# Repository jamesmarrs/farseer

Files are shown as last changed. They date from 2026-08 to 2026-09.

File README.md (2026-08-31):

# farseer

In-car race telemetry module: GPS uplink over UDP via Quectel BG95-M3, with a
low-volume server downlink.

## Bench wiring

See [docs/bench-wiring.md](docs/bench-wiring.md) for Curiosity Nano + Sixfab
Cellular IoT HAT connections, power rails, and bring-up checklist.

## Custom board

**The KiCad project is the single source of truth for the circuit** —
schematic, nets, reference designators, values, footprints, and MPNs. Open it
with:

```bash
open ki_cad_project/farseer/farseer.kicad_pro
```

Export the rendered schematic PDF and the BOM CSV (into `docs/generated/`,
machine-generated — never hand-edit) with:

```bash
./scripts/export_kicad.sh
```

The design *rationale* — datasheet citations, sizing math, traps, and
trade-offs the schematic cannot carry — lives in `docs/`, one document per
block: [MCU](docs/mcu-support-circuit.md),
[cellular](docs/cellular-support-circuit.md),
[GNSS](docs/gnss-support-circuit.md),
[power](docs/power-support-circuit.md), and
[interconnect](docs/interconnect-and-pin-budget.md) where the pin budget is
reconciled against the 48-pin PPS tables. Off-board parts (antennas, pigtail,
SIM) and cost estimates are in [docs/procurement.md](docs/procurement.md).
Pre-KiCad drawings and BOMs are retained in `docs/_archive/` for history only
and must not be treated as authoritative.

It carries no on-board debugger, so the Curiosity Nano's one-cable-does-everything
arrangement splits in two:

| | Bench (Curiosity Nano) | Custom board |
|---|---|---|
| Program + debug | Micro-USB to the on-board ATSAMD21 | **PICkit 5** on `J_icsp`, a 6-pin ICSP header |
| 115200 console | Same cable, debugger's CDC | **USB-C** on `J_dbg`, via a CP2102N bridge |

USB on the custom board is **data only** — it never powers the board, and the
PICkit must not be asked to power the target either.

## Server UDP tunnel (LocalXpose)

The module sends its telemetry datagrams over UDP to `BG95_SERVER_HOST` /
`BG95_SERVER_PORT` (defined in `bg95.h`). During development that destination is
a [LocalXpose](https://localxpose.io/) (`loclx`) UDP tunnel that forwards public
traffic to a listener on the dev machine.

### One-time setup

```bash
loclx account login                       # authenticate (UDP forwarding needs a paid plan)
loclx endpoint reserve --port 59128 --region us   # reserve us.loclx.io:59128 (once)
```

### Run the tunnel

Start the tunnel BEFORE powering the module, and forward to the same port your
server binds:

```bash
loclx tunnel udp --reserved-endpoint us.loclx.io:59128 --to 127.0.0.1:9000
```

### Gotchas (learned the hard way)

- **Use `127.0.0.1`, never `localhost`, in `--to`.** With `--to localhost:9000`
  loclx does not forward: `localhost` can resolve to IPv6 `::1` while the server
  binds IPv4, so tunneled packets are silently dropped even though the tunnel
  shows "running". Always use the IP literal, e.g. `--to 127.0.0.1:9000`.
- **Keep the port in sync.** The reserved-endpoint port, the module's
  `BG95_SERVER_PORT` in `bg95.h`, and your server's bind port (the `--to` port)
  must all agree. The reserved endpoint's public port and the local `--to` port
  do NOT have to match each other, but the module must target the public port.
- **`--to` port must match the server's bind port**, and the server must listen
  on that UDP port (e.g. `nc -u -l 9000` for a quick stand-in).
- **UDP forwarding is a paid `loclx` feature.** On a free plan the tunnel can
  appear up but never forward UDP.
- **`SEND OK` from the BG95 only means the module handed the datagram to the
  network** — UDP has no delivery ack, so it does not confirm the server (or
  tunnel) received anything.

### Verify the public path

Independently of the module, send a probe to the public endpoint and watch the
server (or a `nc -u -l <port>` stand-in) for it:

```bash
echo "probe" | nc -u -w1 us.loclx.io 59128
```

If the probe lands, the tunnel is good and any remaining delivery gap is on the
module egress side (e.g. BG95 DNS resolution of the host). If it does not land,
the tunnel/endpoint/port/plan is the problem — no firmware change will help.

## Structure

| Path | Purpose |
|---|---|
| _build | The [CMake build tree](https://cmake.org/cmake/help/latest/manual/cmake.1.html#introduction-to-cmake-buildsystems), can be deleted. |
| cmake | Generated [CMake](https://cmake.org/) files. May be deleted if user.cmake has not been added |
| .vscode | See [VSCode](https://code.visualstudio.com/docs/getstarted/settings) |
| .vscode/settings.json | Workspace specific settings |
| .vscode/farseer.mplab.json | The MPLAB project file, should not be deleted |
| out | Final build artifacts |

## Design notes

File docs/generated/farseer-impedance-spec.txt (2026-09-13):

FARSEER - CONTROLLED IMPEDANCE SPECIFICATION (generated, do not edit)

Fab: JLCPCB, 4-layer, 1.6 mm. Select 'Impedance Control' = YES and the
stackup JLC04161H-7628 at order time. The trace below is sized for this
stackup only; JLC's default 4-layer build is NOT equivalent.

Controlled net
  Net name              /GPS/GNSS_RF_IN
  Layer                 Top (F.Cu, L1)
  Structure             Coplanar waveguide with ground (single-ended)
  Reference plane       L2 (In1.Cu, GND)
  Trace width           0.34 mm  (base width as drawn; apply your etch compensation)
  Gap to coplanar GND   0.45 mm  (both sides, F.Cu GND pour)
  Target impedance      50 ohm single-ended
  Tolerance             +/-10 %
  Frequency             1.56-1.61 GHz (GNSS L1 band)
  Marking               text note on User.Comments beside the trace

Stackup as drawn in farseer.kicad_pcb
  layer            type      thickness  material / er
  F.Cu             copper       0.035   
  dielectric 1     prepreg     0.2104   FR4 7628 (JLC04161H-7628)  er 4.4
  In1.Cu           copper      0.0152   
  dielectric 2     core         1.065   FR4 core (JLC04161H-7628)  er 4.6
  In2.Cu           copper      0.0152   
  dielectric 3     prepreg     0.2104   FR4 7628 (JLC04161H-7628)  er 4.4
  B.Cu             copper       0.035   

Design basis: scripts/rf_impedance.py (field solve) and
docs/gnss-support-circuit.md section 5 'ESD and layout'.

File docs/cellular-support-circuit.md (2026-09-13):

# BG95-M3 Mini PCIe support circuit — design rationale

> **KiCad is the source of truth.** The circuit itself — parts, values, nets,
> footprints, MPNs — lives on the **`cellular` sheet**
> (`ki_cad_project/farseer/cellular.kicad_sch`: socket `J5`, SIM holder `J6`,
> BOM-only latch `MP1`, ESD `U9`, `R54`–`R58`, `C53`–`C61`) with the `3V3_CELL`
> buck on `3v3_cell.kicad_sch`. This document records only the reasoning a
> schematic cannot carry. If a value here ever disagrees with KiCad, KiCad
> wins.

Authoritative device source:
`datasheets/Quectel_BG95-M3_Mini_PCIe_Hardware_Design_V1.0.pdf`.

> **Read the right document.** `datasheets/quectel_bg95_series_hardware_design_v1-6.pdf`
> describes the raw **102-pin LGA module** soldered inside the card. Its pin
> numbers and its **1.8 V** UART levels do **not** apply at the Mini PCIe edge
> connector. Everything below comes from the Mini PCIe document. Getting these
> two confused is the single most expensive mistake available on this board.

---

## 1. The three findings that shape this design

**The card level-shifts internally — no level shifters needed.** Table 8
(p. 23) lists the UART lines as **3.3 V power domain** and the body text says
plainly *"The power domain of UART interface is 3.3 V."* Table 10 (p. 25) puts
`RI`, `DTR`, `W_DISABLE#`, and `PERST#` in the 3.3 V domain too. Only **PCM,
I2C, and the (U)SIM** lines are 1.8 V (Table 22/23 note 1, p. 38). The PIC at
3.3 V connects directly. Do not fit the TXS0108 that the raw-LGA design guide
calls for.

**There is no PWRKEY, and no power-on pulse to generate.** The functional
diagram (Figure 1, §2.3, p. 11) shows `VCC_3V3` feeding a boost circuit and an
**automatic power-on circuit** on the card; `PWRKEY` appears nowhere in the
52-pin map. The card boots when its rail comes up, so boot ordering is
controlled by the **`3V3_CELL` buck's EN** (`CELL_PWR_EN` into `U3` on
`3v3_cell.kicad_sch`), not by a module-side key pin. [bg95.c](../bg95.c)
drives this from RC7 with the matching active-HIGH polarity (HIGH = rail on)
— the inverse of the legacy Sixfab `HAT_PWR_OFF` scheme in
[bench-wiring.md](bench-wiring.md), which this firmware no longer targets.

**The SIM holder is ours.** `USIM_VDD/DATA/CLK/RST/DET` route out to socket
pins 8, 10, 12, 14, and 44 at **1.8 V** (Table 7, p. 19), so the full Quectel
SIM reference circuit exists on our board around `J6`.

## 2. Reading the 52-pin socket (traps, not the map)

The pin-by-pin map is the `J5` symbol in KiCad. What the schematic cannot say:

- **All four `VCC_3V3` pins (2, 39, 41, 52) must be fed.** They are spread
  across the connector deliberately; feeding only one is a current-density
  mistake. All fourteen GND pins go to the plane (Table 6, p. 18).
- Table 4 note 3 is a hard rule: **"Keep all reserved and unused pins
  unconnected."** Do not tie reserved pins to ground "to be safe" — several
  carry standard Mini PCIe functions (COEX, CLKREQ#, PETn0/PETp0, 1.5 V) that
  the card repurposes or leaves internally connected.
- **Standard-name collisions** will confuse anyone reading a generic Mini PCIe
  pinout: pins 11/13 are `REFCLK−`/`REFCLK+` in the PCIe standard but
  **UART_RX/TX** here; 23/25 are `PERn0`/`PERp0` but **UART_CTS/RTS**; 44 is
  `LED_WLAN#` but **USIM_DET**. The schematic uses the Quectel names.

## 3. Rail voltage — `3V3_CELL` stays at 3.3 V

**Decision: 3.3 V nominal. Do not raise the rail toward 3.6 V to buy droop
margin.** Recorded here because it is a tempting and dangerous optimization.

The card's input is 3.3 V ±9% (3.0–3.6 V; Table 21, p. 37), so 3.6 V is the
**ceiling of the tolerance window, not an operating point** — a ±2% buck set
at 3.6 V is already out of spec before ripple or load-release overshoot.

The decisive reason is cross-rail level compatibility. Table 22 (p. 38)
specifies the card's VOH as **`VCC_3V3` − 0.5 V to `VCC_3V3`**, so `UART_TX`
swings to whatever `3V3_CELL` is. That signal drives a PIC input powered from
the **separate `3V3_SYS` rail** at 3.3 V, and PIC I/O is rated to
**VDD + 0.3 V = 3.6 V** (DS40002213 §50.1). Raising `3V3_CELL` to 3.6 V would
sit exactly at the PIC's absolute maximum with zero margin and forward-bias
its ESD clamp on every UART idle. Because the two rails are independent,
raising one silently creates a mismatch no single-rail review would catch.

The correct fix for droop is lowering source impedance — capacitance, ESR,
and copper — which is what §4 does.

Input levels the other way are comfortable (card VIH = 0.7 × 3.3 = 2.31 V; the
PIC drives near 3.3 V), with one exception: **`PERST#` and `W_DISABLE#` have a
VIL maximum of 0.5 V** (Table 22 note 2), tighter than the 0.99 V that applies
elsewhere — drive them from a real push-pull GPIO or open-drain with a firm
pull-down, never through a lossy series resistor.

## 4. Socket power and bulk capacitance (C57–C61, C54–C56)

§3.2 (p. 18) is the governing text: in 2G the input peak current may reach
**2.7 A** during transmit, and a **low-ESR bypass capacitor no less than
470 µF** is required to prevent the voltage from dropping. Quectel's Figure 3
reference puts 470 µF + 100 nF + 33 pF + 10 pF at the card.

The reservoir is implemented as **three 220 µF polymer caps (`C57`–`C59`)**
plus `C60`/`C61` HF decoupling and the ladder's small RF-bypass caps
**`C9` (33 pF) and `C8` (10 pF)** at the socket VCC pins; the droop budget
and ESR arithmetic behind that choice are in
[power-support-circuit.md](power-support-circuit.md). (The 33 pF caps
`C54`–`C56` are *not* part of this ladder — they are the §3.3/Figure 4
EGSM900 filters on the USIM signal lines; see §5.)

Placement: `C8`/`C9` only work at RF if the loop is tiny — smallest cap
nearest the pin, so `C8` (10 pF) closest to `J5` VCC, then `C9`, then
`C61`/`C60`, with the bulk `C57`–`C59` behind them.

For thermals, LTE Cat M1 transmit is far gentler than the 2G burst — Table 21
(p. 41) gives 235–260 mA average and 495–618 mA max across bands. **The 2.7 A
figure is the EGPRS/2G case**, and it is what sets the rail.

Also from §3.2, a placement-time constraint: keep the switching supply's
power devices and routing **away from the antennas**. The `3V3_CELL` buck
(`U3`, its inductor `L3`, and catch diode `D4` on `3v3_cell.kicad_sch`) is a
switcher — keep its switch-node copper away from the card's antenna
connectors and the antenna cable run.

## 5. (U)SIM interface (J6, C53–C56, U9, R54–R56)

Only **1.8 V (U)SIM cards are supported** (§3.3, p. 19). The card supplies
`USIM_VDD` itself; our board provides the holder and protection, built from
**Figure 4** (holder with card-detect switch, p. 20).

- **Why a hinged holder** (`J6`, GCT SIM8060): the stainless cover locks over
  the card, so there is no eject spring for in-car vibration to actuate — the
  failure a push-push holder invites. The SIM is a **Hologram Hyper**
  triple-cut card punched to nano (1.62–5.5 V so 1.8 V-capable; industrial
  −40 to +105 °C).
- **Deliberate deviation from Figure 4:** the 0 Ω series links Quectel draws
  in RST/CLK/DATA (a cut/isolate debug aid, no electrical function) are
  omitted — the lines run straight from socket to holder. `R54` (15 kΩ to
  `USIM_VDD`) is the Figure 4 anti-jamming pull-up on `USIM_DATA`.
- **Card detection — why the 51 k/51 k divider (`R55`/`R56`).** Figure 4
  pulls `USIM_DET` to an always-on 1.8 V rail through 51 kΩ; the switch
  grounds it when a card is seated. The Mini PCIe card exports **no always-on
  1.8 V rail** — only `USIM_VDD`, which the modem may power down when no SIM
  is present, corrupting the detect level exactly when detection matters. So
  the bias is synthesised with a 51 k/51 k divider from `3V3_CELL`, giving
  ~1.65 V — inside the 1.2–2.0 V VIH window of the 1.8 V domain (Table 23).
  Card inserted → switch closes → `SIM_DET` = 0 V.
- **Hot-plug is disabled by default** (§3.3): firmware must send
  `AT+QSIMDET=1,0` once (0 = pin low when inserted, matching this wiring;
  saved to NV, effective after reboot) and `AT+QSIMSTAT=1` for
  insertion/removal URCs. With that, a card that bounces under vibration
  re-initialises automatically instead of leaving the modem dead until a
  power cycle — and the URC timestamps the event.
- `C53` on `USIM_VDD` must stay ≤ 1 µF and close to the holder (§3.3); the
  33 pF caps (`C54`–`C56`) filter EGSM900 interference on RST/CLK/DATA;
  `U9` (TI TPD4E02B04DQAR, 4-channel array, 0.25 pF/ch typ, USON-10;
  IEC 61000-4-2 ±12 kV contact) is the §3.3-mandated ESD array.

Layout rules from §3.3, all mandatory in review: holder close to the socket,
**trace length under 200 mm**; SIM signals away from RF and power traces (in a
car, with the antenna cable and a 2.7 A switching rail nearby, this is the
real risk); socket-to-holder ground short and wide (≥ 0.5 mm); `USIM_DATA` and
`USIM_CLK` separated and shielded with ground; all SIM peripheral parts at the
holder, not the socket.

## 6. UART to the PIC (R57, R58)

Direct connection, 3.3 V both ends, **115200 8N1** matching
[uart3.c](../uart3.c) (supported rates 9600–230400, §3.5).

**Watch the naming.** Table 4 says pin 11 `UART_RX` is *"Connect to DTE's TX"*
and pin 13 `UART_TX` is *"Connect to DTE's RX"* — the names are
**card-relative**, already crossed for you. Wire PIC TX (`CELL_RX` net) to
pin 11 and PIC RX (`CELL_TX` net) to pin 13; do not cross them a second time.

`R57`/`R58` (220 Ω series) survive from the bench design: with both ends on
one board the back-power case from [bench-wiring.md](bench-wiring.md) is gone,
but they remain useful for edge-rate and ESD control.

Hardware flow control is disabled by default (`AT+IFC`) and unused by
firmware, but `CELL_CTS`/`CELL_RTS` are routed to spare PIC pins anyway — at
115200 with UDP bursts they are cheap insurance and cannot be retrofitted.

## 7. Control and indication

### PERST# (pin 22)

The only reset available, and the card's boot-order lever alongside the buck
EN. Pulled up on the card, active low (Table 10). Reset requires driving low
for **≥ 2 s and ≤ 3.8 s**, then releasing (Figure 10, p. 27), with
**VIL ≤ 0.45 V** — tighter than the general 3.3 V spec.

Drive it open-drain (`TRIS` toggling against the card's internal pull-up)
rather than push-pull, so the card's pull-up defines the idle state while the
PIC is in reset and there is no contention if the rails skew. A ≥ 2 s low is
an eternity in firmware — implement it in the existing non-blocking state
machine in [bg95.c](../bg95.c), not as a busy-wait.

> **Open item:** the belt-and-braces external pull-up (10 kΩ to `3V3_SYS`)
> and a `PERST#` test point are not currently placed in KiCad — only the
> `CELL_PERST` net. Decide before layout; a 2–3.8 s pulse is worth being able
> to scope.

### W_DISABLE# (pin 20)

Airplane-mode input, pulled up on the card, active low. Left **NC**: the pin
function is disabled by default (needs `AT+QCFG="airplanecontrol",1`), and
`AT+CFUN=4` achieves the same in software. Same 0.5 V VIL limit if ever
driven.

### LED_WWAN# (pin 42)

Open collector, **sinks up to 40 mA**; §3.7.4 requires a series resistor with
the LED (Figure 11: pin → LED → resistor → VCC; ~1 kΩ gives ≈2 mA with a red
LED). The default `AT+QCFG="ledmode",0` pattern (Table 13) is a genuinely
useful trackside diagnostic — 200/1800 ms = searching, 1800/200 ms =
registered, 125/125 ms = data — readable from across the paddock.

> **Open item:** no LED or resistor is currently placed in KiCad. If fitted,
> the resistor is not optional — the pin will sink 40 mA and cook the LED.

### RI (pin 17) and DTR (pin 31)

`RI` pulses **low for 120 ms** on a URC after
`AT+QCFG="risignaltype","physical"` (Figure 9); it is routed (`CELL_RI`) so
firmware can stop polling for downlink URCs via interrupt-on-change. `DTR`
(sleep control) is left NC.

## 8. USB (pins 36, 38) — not fitted

The card's USB 2.0 port carries AT commands, NMEA, debugging, and **firmware
upgrade** (§3.4). The update path is currently not fitted on the board; if it
is ever added: 90 Ω differential with ground surround, common-mode choke close
to the socket, low-cap ESD array, no routing under crystals/RF, minimal stubs
(§3.4, Figure 6). Until then, modem re-flash requires bench access to the
card.

## 9. RF / antenna

**Nothing on our board.** The card carries its own 50 Ω main-antenna
connector (§5.1); no 50 Ω trace, matching network, or antenna feed exists on
the host PCB. What the board must provide is **mechanical**: clearance above
the card for the U.FL plug and cable bend radius (Figure 16), a routing path
to the enclosure bulkhead, and strain relief — in a race car this cable sees
vibration continuously, so anchor it. Mating plug family per §5.4: U.FL-LP.
Off-board antenna parts are in [procurement.md](procurement.md).

## 10. ESD

Table 20 (§6.5) lists the card's own ESD ratings as **TBD**. Treat that as
"unspecified, therefore unprotected" and protect at the host: `U9` on the SIM
lines (the only user-accessible connector on this subsystem, hence the
realistic entry point — mandatory per §3.3). A socket-local rail TVS (former
`D6`) was considered and removed: `3V3_CELL` never leaves the board, load
transients are the job of the `C57`–`C61` bank, and no avalanche TVS clamps
low enough to protect a 3.6 V-max load from a failed buck (the SMAJ family
floor is 5.0 V standoff / ~9.2 V clamp; the regulator's own OVP is the real
mitigation).

## 11. Mechanical

- Full-size Mini PCIe socket (`J5`, Molex 679105700 per Figure 19). Its custom
  footprint combines the stock KiCad 52-pin Mini PCIe connector geometry with
  the remote latch land pattern from Molex drawing `SD-67910-004`: the latch
  datum is 50.40 mm from the socket datum, with Ø1.60/Ø1.10 mm locator holes,
  24.20 mm hole spacing, and four 4.80 × 3.00 mm anchor pads. The latch is
  represented by BOM-only item `MP1` (Molex 48099-5701), currently DNP.
  `MP1` intentionally has no separate PCB footprint because its complete land
  pattern is already part of `J5`. In a vehicle, fit positive retention before
  service; a card that walks out of its socket takes the telemetry link with it.
- Operating range tops out at **+75 °C** (§2.2; extended +80 °C). An
  enclosure in a race car, possibly near the transmission tunnel, can exceed
  that — plan mounting location and airflow accordingly.

---

## 12. Bring-up checklist (process, not values)

- [ ] Every RESERVED pin genuinely **unconnected** — not grounded (Table 4
      note 3)
- [ ] No level shifters anywhere on the UART — the card is 3.3 V (Table 8)
- [ ] PIC TX → pin 11, PIC RX → pin 13 (names are card-relative; do not cross
      twice)
- [ ] `PERST#` drive meets VIL ≤ 0.45 V; firmware holds it low 2–3.8 s in the
      `bg95.c` state machine
- [ ] Firmware sends `AT+QSIMDET=1,0` and `AT+QSIMSTAT=1` once (polarity
      matches the divider wiring)
- [ ] PCM and I2C left NC
- [ ] Buck switch node and inductor kept away from the antenna connector and
      cable route (§3.2 EMI warning)
- [ ] `3V3_CELL` still **3.3 V nominal** — see §3 before anyone "adds margin"
- [ ] Socket latch plus secondary retention for vibration
- [x] 10 pF ladder cap decided: fitted, with 33 pF, as `C8`/`C9` at the
      socket VCC pins (completes the Figure 3 ladder)
- [ ] Open items decided: PERST# pull-up/test point, LED_WWAN# indicator,
      modem USB access

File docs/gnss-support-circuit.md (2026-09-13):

# NEO-M9N support circuit — design rationale

> **KiCad is the source of truth.** The circuit itself — parts, values, nets,
> footprints, MPNs — lives on the **`gps` sheet**
> (`ki_cad_project/farseer/gps.kicad_sch`: module `U4`, antenna connector
> `J3`, ESD `D5`, supply ferrite `FB1`, bias-T `L4`/`C52`/`R50`, decoupling
> `C48`–`C51`). This document records only the reasoning a schematic cannot
> carry. If a value here ever disagrees with KiCad, KiCad wins.

Authoritative device sources:

- `datasheets/NEO-M9N-00B_DataSheet_UBX-19014285.pdf` — electrical limits,
  pin definitions, package mechanicals.
- `datasheets/NEO-M9N_Integrationmanual_UBX-19014286.pdf` (**R10**, "IM") —
  the design chapter: power supply, minimal design, antenna circuits,
  footprint, layout.

---

## 1. Package — LCC, not LGA

The NEO form factor is a 24-pin **LCC** (leadless chip carrier) with 1.1 mm
pitch perimeter castellations (Datasheet §6, Table 20, Figure 5). This is a
friendly package to assemble: pads run along the outside edges, not under the
body, so joints are visible and probeable; there is no hidden thermal pad and
nothing needs X-ray inspection. Reflow with a stencil is ideal; hot air works.

Two footprint notes: use the suggested copper and paste-mask geometry from
IM §4.8.3 (Figures 37 and 38) rather than rolling your own, and allow keep-out
for the **de-paneling residual tabs** (up to 0.5 mm) that may protrude on one
long edge (Datasheet §6 note, p. 17).

## 2. Pin handling — the two that defy the "leave open" rule

The pin-by-pin connections are the `U4` symbol in KiCad. The datasheet's
baseline rule (§5, p. 12) is that *"all the inputs have internal pull-up
resistors in normal operation and can be left open if not used"* — with traps:

- **`D_SEL` (pin 2) must not be grounded.** Open selects UART + I2C (what the
  firmware uses); GND selects SPI. No external resistor needed — the internal
  pull-up is 30–130 kΩ.
- **`V_USB` (pin 7) must be tied to GND**, not left open — see §4.
- Reserved pins 15–17: do not connect.
- `RESET_N` (pin 8) has an internal 7–13 kΩ pull-up and no external RC is
  specified; it is driven open-drain from the PIC (`GNSS_RESET`).
- `TIMEPULSE` (pin 3) is routed (`GNSS_1PPS`) even though firmware does not
  use it yet — see §6.

## 3. Main supply (VCC)

Key electrical facts (Datasheet Tables 10–12): operating range 2.7–3.6 V,
**100 mA** acquisition peak, 28–50 mA average. Three constraints that are
easy to violate:

- **Series resistance in the VCC line must stay under 0.2 Ω.** IM §4.2.1 and
  §4.9.1: anything more generates input voltage noise under dynamic current.
  This directly constrains `FB1`, the ferrite on the GNSS branch — it was
  **selected for DCR below 0.2 Ω**, not just for its 600 Ω @ 100 MHz
  impedance. A typical bead of that impedance class can easily exceed 0.2 Ω;
  check DCR on any substitution.
- **The VCC ramp rate is a part-damaging spec.** 20–8000 µs/V (Table 10)
  means a 0 → 3.3 V rise must take between **66 µs and 26.4 ms**; too fast
  *"may permanently damage the device"* (note 7). The `3V3_SYS` buck (`U2`,
  LMR16006X) has internal soft-start; its ramp is checked against this window
  in [power-support-circuit.md](power-support-circuit.md), and must be
  re-checked if the rail's output capacitance ever changes.
- **The VCC pad wants copper, not a thin trace.** IM §4.8.4.2: large pad, low
  impedance, large vias to the power layer, with the 1 µF (`C50`) as close to
  the pad as physically possible. `C49` is the HF companion; `C48` is the
  local reservoir for the 100 mA acquisition peak.

## 4. V_BCKP and V_USB — "unused" does not mean "open"

**V_USB must be tied to GND.** IM §4.2.3: *"If the USB interface is not used,
the V_USB pin must be connected to GND."* Repeated in the §4.3 minimal design
and the §4.9.1 checklist. This is **not** covered by the inputs-may-float
rule.

**V_BCKP is tied to VCC** (IM §4.2.2: *"If no backup supply voltage is
available, connect the V_BCKP pin to VCC"* — never floating). What that
choice costs: without an independent backup source the receiver **cold-starts
at every power-up**, roughly 24–29 s to first fix versus a couple of seconds
hot (Datasheet Table 2) — felt every time the car is keyed off in the
paddock. Backup current is only 45 µA typ at 3 V, so a hold cap or supercap
is a cheap future upgrade; `C51` sits on the V_BCKP tie today.

Two rules if a real backup source is ever fitted:

- **No series resistance on V_BCKP** — the main-to-backup switchover draws a
  short current peak that a resistive path turns into a damaging drop
  (IM §4.2.2).
- In hardware backup mode (V_BCKP alive, VCC down), *"all I/O including
  UART"* must float or be high-impedance, or the chip gets parasitically
  powered through its own pins — the PIC's RD0 must not drive the NEO's RXD
  while the NEO's VCC is down. Today both parts share `3V3_SYS` and power
  down together, so the situation does not arise; it becomes a real
  constraint if GNSS ever moves to a switched rail.

## 5. RF front end — passive and active from one layout

Design goal: **either antenna works**, selected by populate / no-fit of the
bias-T (`L4`, `C52`, `R50`).

### What the module already provides

IM §4.4.3 and §4.5: a **SAW filter**, an **LTE band 13 notch filter**, and an
**LNA** on-module — with the SAW *before* the LNA, so strong out-of-band
interferers cannot saturate it — plus *"an internal DC block and 50 Ω
impedance matching for GNSS signal input."*

So **do not fit a DC block or a matching network on RF_IN** — both are
already inside — and an inexpensive passive antenna genuinely works (§4.5).
The internal SAW-first ordering matters in this vehicle: the BG95 transmits
at up to ~22 dBm from an antenna that may be tens of centimetres from the
GNSS antenna, and out-of-band immunity is a constant +13 dBm except close to
the GNSS band (IM §4.5.3, Figure 34).

### Bias-T choices (active-antenna case)

- **Why `L4` is 47 nH, not the 27 nH in IM Figure 33.** The governing spec is
  impedance **> 500 Ω at the GNSS frequency** (~1575 MHz) at > 300 mA; the
  47 nH part meets it with margin where a generic 27 nH can fall short.
  Verify the impedance curve, not just the inductance, on any substitution.
- **Why `R50` is 22 Ω and not the 10 Ω in IM Table 26.** The text below
  Table 26 qualifies it: when the module supplies bias from `VCC_RF`, short
  circuit current must stay below 150 mA — *"a value of 19 Ω or more is
  required at a module supply of 3.3 V."* 22 Ω is the nearest standard value.
  Check the power rating for the sustained-short case, and remember the
  bias-T inductor DCR (1–2 Ω) and the module's internal feed inductor (1.2 Ω)
  are part of that loop. The antenna feed is the most likely thing to short
  in a race car — a chafed coax against bodywork does it — and this resistor
  is what stops that from destroying the bias-T inductor or the module's
  internal feed.
- `VCC_RF` outputs VCC − 0.1 V at up to 50 mA operating (200 mA abs max),
  comfortably covering the 5–20 mA a typical active antenna draws
  (IM §4.5.2). `LNA_EN` is **active high**. If a future active antenna needs
  a voltage other than 3.3 V, IM §4.5.2 says to use a filtered external
  supply rather than `VCC_RF`.
- **Passive antenna:** no DC bias needed — the antenna connects straight to
  RF_IN (§4.5.1); the bias-T goes no-fit.

### ESD and layout

`D5` (PESD0402-140, low-capacitance, GNSS-band rated) sits at the antenna
connector: IM §4.5.2 requires ESD at the input, and an external RF connector
is a conduction path for destructive signals (§4.9.3). `J3` is a 50 Ω SMA
through-hole right-angle jack for the roof/shell antenna feed — Amphenol RF
`132136`, drawing `SMA6252A2-3GTSGP-50`, filed as
`datasheets/components/J3/Amphenol_132136_SMA6252A2-3GTSGP-50.pdf`. That
PDF is an image-only drawing with no text layer: `pdftotext` returns
nothing, so rasterise it (`pdftoppm -r 200 -png`) to read it.

RF_IN trace rules (IM §4.8.4.1), layout-review pass/fail:

- Grounded co-planar waveguide referenced to layer 2, matched to 50 Ω.
- Via-shield the trace along its entire length; surround the RF_IN pad.
- No stubs; any RF component close to the RF_IN pin.

**Sizing basis (the numbers KiCad carries).** The board is built on the
JLCPCB **JLC04161H-7628** 1.6 mm 4-layer stack: 35 µm top copper over a
single 7628 prepreg, **h = 0.2104 mm, εr 4.4** (JLC impedance-control
spec), to the L2 ground plane. On that stack the grounded CPW of
**W = 0.34 mm, gap S = 0.45 mm** to the F.Cu ground pour, referenced to
In1.Cu, field-solves to **49.8–51.1 Ω** (`scripts/rf_impedance.py line`).
The two figures are the same cross-section solved with electric-wall and
magnetic-wall outer boundaries; they bracket the open-region answer, and
the model cannot resolve inside that ±1 Ω, so quoting a single number here
would overstate what is known. Width is held by the `RF_IN` netclass, gap
by the `GNSS_RF_CPW` rule in `farseer.kicad_dru`.

Two things in that solve are easy to leave out and cost real ohms:

- **Soldermask is worth ≈ 4 Ω.** Bare copper solves to 54–55 Ω; with 20 µm
  of εr 3.6 mask over and between the conductors it drops to the figure
  above. A calculator that ignores mask will tell you this trace is high and
  push you to widen it — do not.
- **Copper thickness** is included (35 µm). Zero-thickness closed forms read
  1–2 Ω higher again.

Cross-check against the fab's own numbers for this exact stackup: JLC's
calculator returns 0.330 mm width for a 0.340 mm gap at 50 Ω, and a
0.345 mm / 0.508 mm design on the same stack has been VNA-verified to
3 GHz. Both sit within 1 Ω of the 0.34 / 0.45 mm drawn here, so the width
was left alone. Confirm on the order form anyway — JLC does the etch
compensation and measures the coupon, so their model wins if it disagrees.

Sensitivity (same solver, one variable at a time from nominal):

| variable | range | Z0 |
|---|---|---|
| prepreg height | ±10 % | 48.4 – 53.6 Ω |
| trace width | ±0.02 mm etch | 52.6 – 49.6 Ω |
| prepreg εr | 4.2 – 4.6 | 52.0 – 50.2 Ω |
| gap | 0.30 – 0.70 mm | 49.8 – 51.7 Ω |

Prepreg height dominates and is the one you cannot see on the Gerbers.
**This is why the board is ordered with JLC's controlled-impedance option
and the stackup pinned to JLC04161H-7628** — they hold ±10 % against their
measured stack; without it the prepreg tolerance alone spreads Z0 across
48–54 Ω, more than everything else on this page combined. The order-time
spec is `docs/generated/farseer-impedance-spec.txt`, regenerated by
`scripts/export_kicad.sh` from the netclass, the rule and the stackup so it
cannot drift from the board, and a matching note sits on `User.Comments`
beside the trace. The gap is a weak knob and exists for shielding, as the IM
asks, not for tuning.

Two traps this replaces:

- The 0.2 mm width the net started life with is a zero-thickness result on a
  0.1 mm prepreg. With 35 µm copper it is ~42–45 Ω on that stack and
  **~63–68 Ω on the JLC stack**. Prepreg height dominates: change fab or
  stack and re-run `scripts/rf_impedance.py` before touching anything else.
- The run is **26.6 mm**, and at L1 (1575.42 MHz) λ0 = 190 mm, εeff ≈ 3.4,
  so **λg ≈ 103 mm** and the trace is **≈ λ/4 (93°)**. A quarter-wave line
  shows any Z0 error at full strength (Z_in = Z0²/50): the old 0.2 mm trace
  would have presented 79–92 Ω to the module (RL 11–13 dB, 0.2–0.4 dB lost
  ahead of the LNA). At the fab's ±10 % the worst case is Z_in ≈ 40 or 60 Ω,
  RL ≈ 20 dB, a few hundredths of a dB. Getting Z0 right matters more here
  than on a short stub would, but the controlled-impedance order is what
  makes it stick.

**`J3` launch.** The pin-1 through-hole is the one discontinuity on the line
that was genuinely off, and it was not visible from the pad outline. An
axisymmetric solve of the whole launch (`scripts/rf_impedance.py launch`:
plated barrel through the full 1.6 mm, both annular pads, both inner planes,
both outer pours) put the stock footprint at **1.21 pF, ≈ 12.7 dB return
loss**. The dominant term is the 1.5 mm barrel coupling coax-fashion to the
In1/In2 plane edges, and that edge was only 2.406 mm across — the pad has
`remove_unused_layers`, so KiCad measured the 0.45 mm clearance from the
hole, not the pad, which made the inner antipad *smaller* than the outer
pour opening. Two changes, both applied by `scripts/apply_rf_tuning.py`:

- **Pin 1 is a 2.05 mm circle, not the stock 2.3 mm roundrect.** Same
  1.5 mm hole. The dimension is KiCad's own pin-1 pad for the vertical
  members of this Amphenol family (`901-144`, `132134`); the `132136`
  drawing specifies holes only (Ø1.5 centre, 4 × Ø1.7 on a 5.08 mm square,
  Ø1.27 pin) and every one of them already matched, so nothing mechanical
  moved. Annular ring 0.275 mm against JLC's 0.15 mm minimum. Do not swap in
  the vertical footprint itself — `J3` is the right-angle jack and the
  vertical outline, courtyard and 3D model are wrong for it.
- **Rule area `J3_RF_ANTIPAD`: 3.0 mm circle, In1.Cu + In2.Cu only, no
  copper pour.** Coax capacitance goes as 1/ln(b/a), so 2.4 → 3.0 mm is
  worth 0.22 pF, 3.0 → 4.0 mm only 0.06 pF, and past that nothing. 3.0 mm is
  the knee, and it stops before the void undercuts the trace (0.35 mm past
  the pad edge, ≈ 1° electrical) or crowds the four ground barrels (inner
  pad edges at 2.34 mm radius). F.Cu and B.Cu keep their pours: the bottom
  ring is the solder joint and both outer pours are the coplanar reference.

Together: 1.21 → 0.77 pF, **≈ 12.7 → 17.9 dB** return loss, net of the
0.25 pF a 50 Ω line carries over that footprint anyway. That is where to
stop — the connector is specified at VSWR 1.3 max (17.7 dB) over DC–6 GHz,
so the launch is no longer the limit. The whole change is worth under
0.2 dB of signal; it is cheap and correct, not decisive.

Via fence: 0.6 mm / 0.3 mm GND vias, centres ≈ 1.1 mm off the trace axis on
both sides, pitch ≤ 1.6 mm along the run (λg/20 ≈ 5.2 mm is the ceiling),
including the `D5`/`L4`/`J3` stretch. A pair at 1.4 mm from the `J3` pin
closes the gap before the fence proper starts at 3.6 mm; the connector's
own ground barrels at 2.54 mm offset bracket the pad as the IM asks. `D5`
and `L4` tap the line with their pads centred on the trace axis, so they add
shunt capacitance (~0.6 pF, RL ≈ 17 dB) but no stub. The 0.8 mm-wide `U4`
RF_IN pad is an inherent, electrically short (<10°) discontinuity and is
left alone.

Absolute limits: in-band 0 dBm, out-of-band +13 dBm, and **max external gain
30 dB** (Tables 10/11 note 8). A high-gain active antenna plus an extra LNA
can exceed 30 dB — do not stack them.

## 6. UART to the PIC

Direct connection, no level shifting, no series resistors specified. Default
**38400 baud, 8N1** NMEA (Table 19), matching the bring-up sequence in
[gps.c](../gps.c), which then negotiates to 115200 for 25 Hz operation.
Levels at 3.3 V are comfortably compatible both ways (Vih = 0.8 × VCC =
2.64 V; outputs swing within 0.4 V of the rails); max 5 mA per digital I/O;
**no hardware flow control** exists (Datasheet §5.1).

`TIMEPULSE` (`GNSS_1PPS`) is routed even though firmware does not use it yet:
1 PPS with **30 ns RMS** accuracy gives a way to discipline timestamps far
better than UART arrival time — exactly what correlating position to lap
timing wants.

---

## 7. Bring-up checklist (process, not values)

- [ ] Populate decision made: passive (bias-T no-fit) vs. active (`L4`,
      `C52`, `R50` fitted, `VCC_RF`/`LNA_EN` in play)
- [ ] `3V3_SYS` ramp verified inside 66 µs – 26.4 ms for the 0 → 3.3 V rise
- [ ] Any `FB1` substitution re-checked for DCR < 0.2 Ω
- [ ] RF_IN laid out as a via-shielded grounded co-planar 50 Ω waveguide,
      no stubs, no DC block, no matching network
- [ ] RF_IN geometry re-checked against the fab stack actually ordered:
      W 0.34 mm / S 0.45 mm assumes JLC04161H-7628 (0.2104 mm 7628 prepreg,
      εr 4.4); any other prepreg height changes the width
- [ ] Footprint and paste mask taken from IM Figures 37/38, with de-panel tab
      keep-out on the long edge
- [ ] Total external gain ≤ 30 dB — no active antenna stacked with an extra
      LNA
- [ ] GNSS antenna sited as far as practical from the BG95 antenna (see
      [procurement.md](procurement.md))

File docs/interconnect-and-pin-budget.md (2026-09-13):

# Interconnect and PIC pin budget

The single place where the subsystems are reconciled against one another. The
circuit itself lives in the KiCad project
(`ki_cad_project/farseer/farseer.kicad_pro`); the net names below are the
global labels used on its sheets, so a net can be traced from sheet to sheet
by name. Per-block rationale lives in
[mcu-support-circuit.md](mcu-support-circuit.md),
[cellular-support-circuit.md](cellular-support-circuit.md),
[gnss-support-circuit.md](gnss-support-circuit.md), and
[power-support-circuit.md](power-support-circuit.md).

> **Every PPS assignment below was checked against the 48-pin column of Table
> 21-1 (PPS Input Selection) and Table 21-2 (PPS Output Selection)**,
> DS40002213F pp. 360-362. The PPS registers accept an illegal port silently
> and route nothing, so this check is the difference between a working board
> and a dead signal with no error.

---

## 1. System block diagram

```mermaid
flowchart LR
  subgraph power [Power]
    VSYS["VSYS 7-18 V"]
    BuckCell["U3 TPS54560-Q1"]
    BuckSys["U2 LMR16006X"]
    RailC["3V3_CELL"]
    RailS["3V3_SYS"]
  end

  subgraph mcu [PIC18F57Q84 48-TQFP]
    PIC["U1 PIC"]
    ICSP["J1 6-pin ICSP, PICkit 5"]
    Bridge["U7 CP2102N USB-UART bridge"]
    UsbC["J4 USB-C"]
  end

  subgraph cell [BG95-M3 Mini PCIe]
    Socket["J5 52-pin socket"]
    SIM["J6 Nano-SIM 1.8 V"]
    AntL["LTE antenna U.FL"]
  end

  subgraph gnss [NEO-M9N 24-LCC]
    NEO["U4 NEO-M9N"]
    AntG["J3 GNSS antenna SMA"]
  end

  VSYS --> BuckCell --> RailC --> Socket
  VSYS --> BuckSys --> RailS
  RailS --> PIC
  RailS --> NEO
  RailS --> Bridge

  PIC <-->|"ICSP program + debug"| ICSP
  PIC <-->|"UART1 115200 console"| Bridge
  Bridge <-->|"USB CDC, data only"| UsbC

  PIC -->|"CELL_PWR_EN -> EN"| BuckCell
  PIC <-->|"UART3 115200"| Socket
  PIC -->|"CELL_PERST"| Socket
  Socket <--> SIM
  Socket --- AntL

  PIC <-->|"UART2 38400 then 115200"| NEO
  PIC -->|"GNSS_RESET"| NEO
  NEO -->|"GNSS_1PPS"| PIC
  NEO --- AntG
```

Two rails, deliberately separate: `3V3_CELL` absorbs the BG95's 2.7 A bursts,
`3V3_SYS` stays quiet for the PIC and the GNSS receiver. **Both are 3.3 V and
must stay 3.3 V** — see
[cellular-support-circuit.md](cellular-support-circuit.md) §3 for why raising
either one breaks cross-rail logic levels.

**No level shifters exist anywhere on this board.** The Mini PCIe card
presents a 3.3 V UART and 3.3 V control pins, and the NEO-M9N runs from the
same 3.3 V rail as the PIC. The 1.8 V domains (card SIM, PCM, I2C) never
touch the MCU — the SIM lines run from the socket to the holder and nowhere
else. The Curiosity Nano's 74LVC1T45 shifters exist only because its target
voltage is adjustable.

---

## 2. Complete PIC pin budget

Existing assignments come from the firmware; new ones are allocated here.
Connections and series parts are in KiCad — this table is the allocation and
its PPS legality.

| Pin | Port | Net | Dir | Peripheral | PPS check (48-pin) | Source |
|-----|---|-----|-----|---|---|---|
| 1 | RC7 | `CELL_PWR_EN` → `U3` EN (via `R49`) | out | GPIO | none needed | [bg95.c](../bg95.c), **repurposed** |
| 6 | VSS | GND | — | — | — | Req |
| 7 | VDD | `3V3_SYS` | — | — | — | Req |
| 9 | RB1 | *(reserved for W_DISABLE#)* | out | GPIO | none needed | not wired in KiCad |
| 16 | RB4 | `CELL_PERST` | out | GPIO | none needed | **new** |
| 17 | RB5 | `CELL_RI` | in | **INT2** | INT2PPS = **B**, F | **new**, Opt |
| 18 | RB6 | `ICSPCLK` | — | ICSP | — | Req, keep clear |
| 19 | RB7 | `ICSPDAT` | — | ICSP | — | Req, keep clear |
| 20 | RE3 | `MCLR` | in | reset | — | Req |
| 21 | RA0 | `CELL_TX` (from card pin 13) | in | **U3RX** | U3RXPPS = **A**, F | [uart3.c](../uart3.c) |
| 22 | RA1 | `CELL_RX` (to card pin 11) | out | **U3TX** | UART3 TX 0x26 = **A**, F | [uart3.c](../uart3.c) |
| 23 | RA2 | `CELL_CTS` (from card pin 25) | in | **U3CTS** | U3CTSPPS = **A**, F | **new**, Opt |
| 24 | RA3 | `CELL_RTS` (to card pin 23) | out | **U3RTS** | UART3 RTS 0x28 = **A**, F | **new**, Opt |
| 30 | VDD | `3V3_SYS` | — | — | — | Req |
| 31 | VSS | GND | — | — | — | Req |
| 36 | RF0 | `USB_RXD` (to U7 RXD) | out | **U1TX** | UART1 TX 0x20 = C, **F** | [uart1.c](../uart1.c) |
| 37 | RF1 | `USB_TXD` (from U7 TXD) | in | **U1RX** | U1RXPPS = C, **F** | [uart1.c](../uart1.c) |
| 40 | RC2 | `GNSS_1PPS` | in | **CCP1** capture | CCP1PPS = **C**, F | **new** |
| 42 | RD0 | `GNSS_RX` (to NEO pin 21) | out | **U2TX** | UART2 TX 0x23 = B, **D** | [uart2.c](../uart2.c) |
| 43 | RD1 | `GNSS_TX` (from NEO pin 20) | in | **U2RX** | U2RXPPS = B, **D** | [uart2.c](../uart2.c) |
| 44 | RD2 | `GNSS_RESET` | out | GPIO | none needed | **new** |

The `USB_TXD`/`USB_RXD` names are **bridge-relative** (U7's TXD drives the
PIC's RX), same convention as `CELL_TX`/`CELL_RX` being card-relative — the
crossing is already in the names, do not cross again in layout.

Free after allocation: RD4-RD7 (2-5), RB0 (8), RB2 (10), RB3 (11),
RF4-RF7 (12-15), RA4-RA5 (25-26), RE0-RE2 (27-29), RA7 (32), RA6 (33),
RC0 (34), RC1 (35), RF2 (38), RF3 (39), RC3 (41), RD3 (45), RC4-RC6 (46-48).
Roughly 27 spare pins — comfortable headroom for sensors, CAN, or an SD card
later.

Per DS40002213F §4.6, drive every unused pin low in firmware or tie it to VSS
through 1-10 kΩ.

### Why these particular pins

**The four UART3 signals use contiguous RA0-RA3 pins.** UART3 RX/CTS inputs and
TX/RTS outputs support **ports A and F** on the 48-pin part, so all four PORTA
assignments are legal. The net names are card-relative: RA0 receives
`CELL_TX`, while RA1 transmits `CELL_RX`. Putting flow control on port B or D
— which would look fine on a 40-pin part — would route nothing.

**`GNSS_1PPS` on RC2 buys hardware timestamping.** CCP1 capture is available
only on **ports C and F** at 48 pins, and RC2 is CCP1's own POR default.
Capturing the 1 PPS edge in hardware rather than an ISR is the difference
between ~30 ns and tens of microseconds of jitter, which is what makes the
pulse worth routing at all. The same C/F restriction applies to SMT1
(`SMT1SIGPPS` = C, F) if a longer capture window is ever wanted — the
constraint already called out in the project rules.

**`CELL_RI` on RB5 uses INT2**, whose 48-pin ports are **B and F**. That lets
a downlink URC wake the firmware instead of being polled.

**`CELL_PWR_EN` uses RC7**, a GPIO that needs no PPS routing. Its active-HIGH
polarity is defined in [bg95.c](../bg95.c) — see section 3.

**Programming and debug are `J1` with a PICkit 5**, not the USB-C port. The
PIC18F57Q84 has no USB peripheral, and its JTAG module is boundary scan only
(DS40002213F §39), so ICSP carries both the programming and the in-circuit
debug traffic. The USB-C port (`U7` from `3V3_SYS`, so it can never
back-power the board) is the console half of what the Curiosity Nano's
debugger used to provide, and nothing more.

---

## 3. Power-up and boot order

There is **no PWRKEY** on the Mini PCIe card; it has an automatic power-on
circuit and boots whenever `3V3_CELL` is live. Sequencing is therefore done
by gating the `3V3_CELL` buck.

```mermaid
sequenceDiagram
    participant V as VSYS
    participant B as U2 / 3V3_SYS
    participant P as PIC
    participant A as U3 / 3V3_CELL
    participant C as BG95 card
    participant G as NEO-M9N

    V->>B: rail rises (always enabled)
    B->>P: PIC + NEO powered together
    B->>G: VCC ramp must land in 66 us - 26.4 ms
    Note over P,A: EN pull-down holds U3 off<br/>while PIC is in reset -> card OFF
    P->>P: init clocks, UARTs, GPIO
    P->>A: drive CELL_PWR_EN high
    A->>C: 3V3_CELL rises -> card auto-powers on
    C->>P: UART active, AT sequence begins
    Note over P,C: PERST# low 2-3.8 s available for recovery
```

1. **`3V3_SYS` first, always.** `U2` is unconditionally enabled, so the PIC
   and the NEO-M9N come up together on the same rail. They can never drive
   each other while one is unpowered, which eliminates the back-power failure
   documented in [bench-wiring.md](bench-wiring.md).
2. **The card starts OFF.** The `EN` pull-down on `3v3_cell.kicad_sch` holds
   `U3` disabled while the PIC is in reset and RC7 is high-impedance (the
   TPS54560-Q1's 1.2 µA internal pull-up only develops 0.12 V across it, well
   below the 1.2 V enable threshold).
3. **The PIC decides when the modem boots** by driving `CELL_PWR_EN` high.
4. **`PERST#` is for recovery, not boot** — a wedged modem gets a 2-3.8 s low
   pulse rather than a power cycle.

> **Firmware change done: `CELL_PWR_EN` polarity inverted.**
> [bg95.c](../bg95.c) previously drove RA2 for the Sixfab `HAT_PWR_OFF` pin,
> where **HIGH = module off**. On the custom board RC7 drives the buck's `EN`,
> where **HIGH = rail on**, and the firmware now matches: init writes
> `LATC7 = CELL_PWR_OFF` (0) and the power-on write in `ST_PWR_HOLD` is
> `LATC7 = CELL_PWR_ON` (1). The polarity is defined once by the
> `CELL_PWR_ON`/`CELL_PWR_OFF` macros in `bg95.c` — getting this backwards
> means the modem is powered before the PIC is ready, or never powers at all.

**GNSS ramp check.** The NEO-M9N tolerates a VCC ramp of only
**20-8000 µs/V**, so a 0 → 3.3 V rise must take between **66 µs and
26.4 ms**; too fast can permanently damage it. That constrains `U2`, and it
is verified in [power-support-circuit.md](power-support-circuit.md).

---

## 4. Combined pre-order checklist

Per-block checklists live in each document. These are the cross-cutting items
that no single document owns.

- [ ] Every PPS assignment re-verified against the **48-pin** column of
      Tables 21-1 and 21-2, not the 28/40-pin columns
- [ ] `CELL_CTS` / `CELL_RTS` on port A or F only (UART3 restriction)
- [ ] `GNSS_1PPS` on port C or F only (CCP1 / SMT1 restriction)
- [x] `CELL_PWR_EN` polarity flipped in [bg95.c](../bg95.c) — high now means
      on
- [ ] `U3` EN pull-down fitted so the card is off while the PIC is in reset
- [ ] `U2` ramp inside the NEO-M9N's 66 µs - 26.4 ms window
- [ ] `FB1` on the GNSS branch has DCR **< 0.2 Ω**
- [ ] Both rails still **3.3 V nominal**
- [ ] Single ground plane, with the `U3` switch node and the SIM/RF areas
      kept apart
- [ ] `U3` power stage routed away from both antenna connectors and cable
      runs
- [ ] Unused PIC pins driven low or pulled to VSS through 1-10 kΩ
- [ ] `U7` fed from `3V3_SYS`, never from USB VBUS — the console must not be
      able to power or back-power the board
- [ ] PICkit 5 target power left off; the board supplies its own rails while
      being programmed or debugged
- [ ] GNSS and LTE antennas separated as far as the enclosure allows (see
      [procurement.md](procurement.md))

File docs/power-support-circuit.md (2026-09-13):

# Power rails — design rationale

> **KiCad is the source of truth.** The circuit itself lives on three sheets
> of `ki_cad_project/farseer/`: **`power_protection.kicad_sch`** (battery
> input `J2`, fuse `F1`, load-dump clamp `D2`, reverse-polarity FET `Q1`,
> pi filter `L1`/`C31`–`C33`, front-end reservoir `C7`),
> **`3v3_cell.kicad_sch`** (`U3` TPS54560-Q1 → `3V3_CELL`), and
> **`3v3_sys.kicad_sch`** (`U2` LMR16006X → `3V3_SYS`). The modem's burst
> reservoir (`C57`–`C59`) sits on `cellular.kicad_sch`, at the socket where
> the current is drawn. This document records the sizing arithmetic and
> trade-offs behind those values. If a value here ever disagrees with KiCad,
> KiCad wins.

Trigger for the reservoir analysis: §3.2 of
`datasheets/Quectel_BG95-M3_Mini_PCIe_Hardware_Design_V1.0.pdf` requires *"a
low-ESR bypass capacitor **no less than 470 µF**"* at the card's 3.3 V input.

---

## 1. What the socket capacitors actually do

The division of labour at the Mini PCIe socket (all on `cellular.kicad_sch`):

| Refs | Job | Frequency domain |
|---|-----|---|
| `C57`–`C59` (3 × 220 µF polymer) | Burst energy reservoir | Low — sized by charge |
| `C60`/`C61` (10 µF + 100 nF) | HF decoupling at the power pins | High — sized by impedance |
| `C54`–`C56` (33 pF) | Quectel Figure 3 RF ladder | RF |
| `C7` (on `power_protection`) | Front-end load-dump reservoir, harness side | Untouched by this analysis |

The reservoir is deliberately **at the socket, not at the converter** — the
22 µF ceramics at `U3` (`C43`–`C45`) are only local output capacitance.

## 2. Droop budget

The card accepts **3.0–3.6 V, typ 3.3 V** (Table 21, Mini PCIe design guide).
Feeding 3.3 V leaves 300 mV to the lower limit, but not all of it is
available for droop:

| Term | Allocation | Note |
|---|---|---|
| Total 3.3 V → 3.0 V | **300 mV** | Hard floor |
| Buck setpoint tolerance (±2%) | −66 mV | Reference + 1% divider tolerance |
| Output ripple (design target 30 mV p-p) | −30 mV | |
| **Available for transient droop** | **≈ 204 mV** | |

Allocate roughly 20 mV to ESR and the remainder to capacitance.

## 3. ESR term — evaluated first

ESR drop is instantaneous and **no amount of capacitance reduces it**:

```
dV_esr = I_burst × ESR = 2.7 A × ESR
```

| Effective ESR | Drop at 2.7 A |
|---|---|
| 25 mΩ | 68 mV |
| 20 mΩ | 54 mV |
| 8 mΩ | 22 mV |

This is why **several smaller polymer capacitors in parallel beat one large
aluminium electrolytic**: paralleling N identical devices divides both ESR
and ESL by N. A single 470 µF aluminium part would satisfy the capacitance
number while landing in the 25 mΩ-plus range and eating a third of the droop
budget on its own. Target: **effective ESR ≤ 10 mΩ**, giving ≤ 27 mV.

## 4. Capacitance term

The reservoir does **not** have to supply the whole 2G burst. `U3` is a 5 A
converter and can carry 2.7 A continuously; the capacitors only bridge the
interval before the control loop responds:

```
dV_c = I_burst × t_response / C
```

With ~184 mV left after the ESR allocation:

| Loop response `t` | Minimum C |
|---|---|
| 10 µs | 147 µF |
| 20 µs | 293 µF |
| 30 µs | 440 µF |
| 50 µs | 734 µF |

This is the sanity check that makes Quectel's number make sense: **470 µF
corresponds to roughly 30–50 µs of full-current response**, about right for
their reference design's MIC29302 **LDO**. A TPS54560-Q1 switching at 500 kHz
responds faster, so 470 µF is conservative here — but it is the stated
minimum and we meet it.

Two effects that do **not** bind:

- **Inductor slew.** At 12 V in, 3.3 V out, 10 µH (`L3`), current slews at
  (12 − 3.3)/10 µH ≈ 0.87 A/µs, so 2.7 A takes ~3.1 µs. The control loop,
  not the inductor, is the limit.
- **Burst-to-burst recharge.** A GSM slot is 577 µs within a 4.615 ms frame,
  leaving ~4 ms and ~2.3 A of spare converter capability to recharge. Ample.

## 5. Selection — why 3 × 220 µF

| Term | Value |
|---|---|
| Capacitance | 660 µF |
| Effective ESR (3 × ~20 mΩ in parallel) | ≈ 6.7 mΩ |
| ESR drop at 2.7 A | ≈ 18 mV |
| Capacitive droop at t = 20 µs | ≈ 82 mV |
| **Total estimated droop** | **≈ 100 mV** vs 204 mV available |

Comfortably inside budget, clears the 470 µF floor with margin, and three
parallel parts keep ESR and ESL low. **Rejected alternatives:** 5 × 100 µF
(lowest ESR, but most board area and placement effort for margin already
sufficient) and 2 × 330 µF (fewest parts, highest ESR of the three options).

Verify at purchase: ESR specified at 100 kHz for the actual MPN, ripple
current rating covers the burst, voltage rating derates acceptably at 3.3 V.

## 6. `3V3_CELL` loop compensation — re-derived for 660 µF

Tripling the output capacitance moved the converter's loop, so compensation
was not a "finalize during capture" item. With `R_load = 3.3 V / 2.7 A ≈
1.22 Ω`, the output pole moved from ≈ 651 Hz (at the original 200 µF) down to
≈ **197 Hz** at 660 µF, and the ESR zero sits at
`1 / (2π × 6.7 mΩ × 660 µF) ≈ 36 kHz`.

The compensation network in KiCad (`R47`, `C46`, `C47` on
`3v3_cell.kicad_sch`) **was re-derived for this** — the Design Notes on those
parts record the TPS54560-Q1 datasheet equations used: Equation 46 for
mid-band gain with Cout ≈ 700 µF (660 µF polymer plus derated local ceramic)
at a 4.4 kHz target crossover, Equation 47 placing the zero at the ~207 Hz
modulator pole, and Equation 48 for the high-frequency pole against the
34 kHz ESR zero. Re-run those equations if the reservoir ever changes again.

**Soft-start / inrush — still verify at bring-up.** Charging 660 µF adds
`I = C × dV/dt` on top of the load current:

| Soft-start time | Added inrush |
|---|---|
| 2 ms | 1.09 A |
| 5 ms | 0.44 A |
| 10 ms | 0.22 A |

The TPS54560-Q1 has **no SS/TR pin** — soft-start is internal and fixed by the
switching frequency (datasheet §7.5, "Internal soft-start time": 2.1 ms typ at
f_SW = 500 kHz, 10 % → 90 %; Figure 21 for the curve). `R46` sets 500 kHz, so
expect **≈ 2 ms**, i.e. roughly **1 A of added inrush** on top of the load
while the reservoir charges. That is well inside the 6.3 A minimum switch
current limit (§7.5, "Current limit threshold"), and the modem draws almost
nothing until the rail is up, so the 2 ms ramp is acceptable; the ≥ 5 ms row
above is not reachable without lowering f_SW, and there is no reason to. Verify
the ramp and peak inductor current on the bench at bring-up.

**`EN` sequencing still works.** Soft-start of a few milliseconds is
irrelevant next to the modem's own multi-second boot, so gating the rail from
`CELL_PWR_EN` (PIC RC7, through the series resistor into `U3` EN) behaves as
described in [interconnect-and-pin-budget.md](interconnect-and-pin-budget.md).
The EN pull-down (see its Design Note in KiCad) keeps the card off while the
PIC is in reset.

## 7. `3V3_SYS` and the NEO-M9N ramp — checked, unaffected

The NEO-M9N is on `U2` (LMR16006X), a separate converter, so nothing above
changes its behaviour. Stated explicitly because the constraint is
**part-damaging** rather than merely out of spec.

NEO `VCC` ramp must be **20–8000 µs/V** (Datasheet Table 10; note 7: too fast
*"may permanently damage the device"*). For a 0 → 3.3 V rise:

| Bound | Ramp rate | Rise time |
|---|---|---|
| Fastest allowed | 20 µs/V | **66 µs** |
| Slowest allowed | 8000 µs/V | **26.4 ms** |

Action at bring-up: measure the LMR16006X's soft-start ramp on `3V3_SYS` and
confirm it falls inside that window. Internal soft-start is typically a few
hundred microseconds to a few milliseconds, comfortably mid-range, but **the
fast bound is the dangerous one** — do not fit a fast-start variant or bypass
soft-start. If output capacitance on this rail ever grows, re-check the slow
bound too.

Related constraint from the NEO integration manual (§4.2.1): series
resistance in the VCC line must stay **below 0.2 Ω**, which makes `FB1` on
`gps.kicad_sch` a DCR-selected part, not just an impedance-selected one — see
[gnss-support-circuit.md](gnss-support-circuit.md).

## 8. Q1 reverse-polarity pass FET

`Q1` sits on `power_protection.kicad_sch` between the fused battery node
(`D2` cathode) and the pi-filter input (`L1`). It carries the **whole board
input current** — `L1`'s Design Notes already put that at **~2.5 A worst
case at 7 V in**, and `F1` is 5 A.

The original `DMP6110SFDF` (U-DFN2020-6 Type F, 110 mΩ max @ −10 V, −3.5 A)
dissipated **I²R ≈ 0.69 W** in a 2 × 2 mm DFN at that current. That was the
thermal bottleneck, not the gate network (`R41` + `D1` 10 V clamp; `VGSS` is
still ±20 V).

KiCad now uses `DMP6023LFGQ-13` (PowerDI3333-8, AEC-Q101):

| | Old `DMP6110SFDF` | New `DMP6023LFGQ` |
|---|---|---|
| `RDS(on)` max | 110 mΩ @ −10 V | 25 mΩ @ −10 V / 33 mΩ @ −4.5 V |
| Continuous `ID` | −3.5 A | −7.7 A (25 °C) / −6.2 A (70 °C) |
| Dissipation at 2.5 A | 0.69 W | 0.16–0.21 W |
| Package | 2.0 × 2.0 mm DFN | 3.3 × 3.3 mm PowerDI3333-8 |

At 2.5 A and 33 mΩ, even the datasheet minimum-pad `RθJA` of 123 °C/W
(Note 5) is only ~26 °C rise. `VDSS` is still −60 V, which clears the
`SM8S26A` clamp at ~42 V. Pinout is **not** the old DFN: pins 1–3 source,
pin 4 gate, pad 5 merged drain tab.

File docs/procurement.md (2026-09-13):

# Procurement — off-board parts, costs, and pre-order checks

The **on-board** parts list is generated from KiCad — run
`scripts/export_kicad.sh` and use `docs/generated/farseer-bom.csv`
(Reference, Value, Footprint, MPN, Manufacturer, Alt MPN, Description, DNP).
This document covers what a KiCad BOM export cannot: parts that never touch
the host PCB, rough cost expectations, and the ordering checks.

Authoritative sources:

- `datasheets/Quectel_BG95-M3_Mini_PCIe_Hardware_Design_V1.0.pdf` — §5
  (antenna connection): connector type, band list (Table 17), antenna and
  cable-loss requirements (Table 20), U.FL-LP mating-plug recommendation
  (§5.4), mated space factor (Figure 16).
- [Taoglas CAB.011 datasheet](https://cdn.taoglas.com/datasheets/CAB.011.pdf)
- [Taoglas TG.30.8113 datasheet](https://www.taoglas.com/datasheets/TG.30.8113W.pdf)

---

## 1. LTE antenna feed (off-board)

The LTE RF chain is entirely off-board: the BG95-M3 Mini PCIe card carries
its own 50 Ω MAIN antenna receptacle (Hardware Design §5.1, Table 16), so the
path is card receptacle → pigtail → enclosure bulkhead → antenna. Contrast
with the GNSS side, where the connector (`J3`) and ESD diode (`D5`) are real
board parts on `gps.kicad_sch` because the NEO-M9N's RF_IN pin is on our PCB.

| Ref | Qty | Value / description | Suggested MPN | Notes |
|-----|-----|---|---|---|
| X_pigtail | 1 | Pigtail, IPEX MHF I plug → SMA(F) bulkhead straight, 95 mm of 1.13 mm coax, 50 Ω, VSWR ≤ 1.3 to 6 GHz | **Taoglas CAB.011** | MHF I mates the card's U.FL-type MAIN receptacle (§5.4 recommends the U.FL-LP family — **not MHF4**, which looks identical and does not mate). Loss ≈ 0.27 dB at 2 GHz for the 95 mm run plus ~0.2–0.3 dB of connector transitions, well inside the Table 20 budget (< 1 dB low bands / < 1.5 dB high bands). D-cut bulkhead: use a D-hole panel cutout for anti-rotation under vibration |
| X_ant | 1 | LTE antenna, SMA(M), 50 Ω, covering 663–2180 MHz (Cat M1 bands, Table 17) + GSM850/900/DCS1800/PCS1900 | **Taoglas TG.30.8113** (Apex, hinged SMA(M), 600–6000 MHz dipole) | Ground-plane independent, 70 %+ typical efficiency (Table 20 requires > 30 %, VSWR ≤ 2 — verify the per-band VSWR plot for B2/B4/B12/B13 before ordering). Hinge is rated for high-vibration use; the straight TG.30.8111 is an alternative with one less moving part. **Known gap: no coverage checkmarks for B71 (617–698 MHz)** — irrelevant for Cat M1, matters only if NB2 on B71 is ever required |

Nothing electrical goes on our board for this chain: no 50 Ω trace, no
matching network, no DC block, no bias-T (the MAIN receptacle carries no DC).
The card's ESD ratings for its antenna connectors are listed TBD (Table 20,
§6.5), and with no board-side RF node there is nowhere to hang a diode — the
antenna's DC-grounded element is the practical ESD path.

What the *mechanical* design owes these parts (also flagged in
[cellular-support-circuit.md](cellular-support-circuit.md) §9):

- Vertical clearance above the card for the mated MHF I plug and its cable
  bend radius (Figure 16 space factor).
- A **6.35 mm D-hole** panel cutout at the enclosure wall for the SMA(F)
  bulkhead (¼-36 UNS thread, nut + washer supplied with CAB.011).
- Cable anchoring — in a race car this cable sees vibration continuously.
- Route the pigtail away from the `3V3_CELL` buck's inductor and switch node
  (§3.2 EMI warning) and do **not** bundle it with the GNSS coax for long
  parallel runs.

## 2. Other off-board items (no line in any BOM)

- **BG95-M3 Mini PCIe card** — plugs into `J5`; the socket is on the board,
  the card is a purchase.
- **GNSS antenna** — SMA(M) onto `J3`. Passive or active decides the bias-T
  populate option on `gps.kicad_sch`; see
  [gnss-support-circuit.md](gnss-support-circuit.md) §5. Total external gain
  must stay ≤ 30 dB.
- **SIM card** — Hologram Hyper, triple-cut punched to nano (4FF); 1.8 V
  capable, industrial temperature grade.
- **PCB fabrication and the enclosure.**

## 3. Antenna siting (install-time, no parts)

- **LTE antenna ≥ 50 cm from the GNSS antenna** (20 cm absolute floor),
  ideally with body metal between them. The separation rule applies to the
  radiating elements — the two SMA bulkheads may sit adjacent on the
  enclosure.
- The specific threat is **LTE B13 uplink (777–787 MHz), whose 2nd harmonic
  (1554–1574 MHz) lands inside the GNSS band** — the NEO-M9N's on-module B13
  notch (IM §4.4.3) is the last line of defence, not the first.
- Verification once hardware exists: compare NMEA C/N0 with the BG95 idle vs.
  transmitting a sustained uplink on B13; a mean drop > 1–2 dB means more
  separation or re-routed cables.

## 4. JLCPCB assembly BOM

`scripts/export_kicad.sh` also writes the two BOMs JLCPCB's SMT quote page
accepts, in its required column layout (`Comment`, `Designator`, `Footprint`,
`LCSC Part #`, `MPN`):

| File | Contents |
|---|---|
| `docs/generated/farseer-jlcpcb-bom-full.csv` | every placeable line |
| `docs/generated/farseer-jlcpcb-bom-smt.csv` | SMT only — `C7`, `F1`, `J1`, `J2`, `J3`, `J5`, `J6`, `JP1`, `MP1` removed as through-hole, wave-solder, or mechanical |

`R54` is DNP in the schematic and is in **neither** file: JLCPCB places every
line it is given, so a do-not-populate part has to be omitted, not annotated.

LCSC part numbers come from `scripts/lookup_lcsc.py`, which resolves each MPN
in the KiCad BOM and caches the result in `docs/generated/jlcpcb-parts.csv`
(LCSC number, Basic/Extended class, stock, unit price, match status). Rules
that script follows, and that any manual edit must keep:

- **Exact MPN only.** This is an AEC-Q200/Q100 design; a "same value" substitute
  silently drops that qualification. Punctuation is ignored when comparing
  (JLC writes `EEH-ZA1H101P` as `EEHZA1H101P`) because that is the same
  ordering number, not a substitute — those rows read `exact-normalized`.
- A part JLC does not carry gets an **empty `LCSC Part #`** and a
  `no-exact-match` status, plus whatever JLC stocks under a similar MPN in
  `JLCCandidates`. Those candidates are **unverified leads for a human**, not
  approved substitutions — some differ only in tape-and-reel suffix, others in
  voltage rating, dielectric, or automotive grade.
- Re-running is offline unless the schematic introduced a new MPN; cached hits
  are reused and previous misses are retried. `--refresh` re-queries everything.

Uploading also needs a CPL / centroid file (`Designator`, `Mid X`, `Mid Y`,
`Rotation`, `Layer`, millimetres) exported from `farseer.kicad_pcb`; that is not
generated yet.

## 5. Approximate cost (qty 1, USD, distributor list — order of magnitude)

| Item | Rough cost |
|---|---|
| On-board parts (full KiCad BOM, incl. `U1` PIC and `U4` NEO-M9N) | ~$70–108 |
| CAB.011 pigtail | ~$5–8 |
| TG.30.8113 antenna | ~$10–15 |

Excluded from all figures: the BG95-M3 card, the GNSS antenna, the SIM, the
PCB, and the enclosure. Prices are volatile — expect materially lower in
volume.

## 6. Verify before ordering

- [ ] Pigtail card end is **MHF I / U.FL-compatible**, not MHF4
- [ ] Mated plug height fits between the card and the enclosure lid
      (Figure 16)
- [ ] 95 mm reaches from the card's MAIN receptacle to the bulkhead with
      slack for strain relief and bend radius — if not, use Taoglas's cable
      builder for a custom length and re-check the loss budget
- [ ] Antenna per-band VSWR ≤ 2 and efficiency > 30 % on B2/B4/B12/B13
      (Table 20 requirements)
- [ ] B71 not required (NB2-only band; TG.30.8113 does not cover it)
- [ ] LTE antenna sited ≥ 50 cm from the GNSS antenna
- [ ] Reservoir caps (`C57`–`C59`): ESR specified at 100 kHz for the actual
      MPN, ripple-current rating covers the 2.7 A burst, voltage derating
      acceptable at 3.3 V (see
      [power-support-circuit.md](power-support-circuit.md) §5)
- [ ] Any `FB1` substitution re-checked for DCR < 0.2 Ω
- [ ] KiCad BOM re-exported (`scripts/export_kicad.sh`) after the last
      schematic change, and DNP column reviewed against the populate
      decisions (GNSS bias-T, open items in the block docs)
- [ ] `scripts/export_kicad.sh` raised no "never been looked up" warning, i.e.
      every MPN in the BOM has been through `scripts/lookup_lcsc.py`
- [ ] Every empty `LCSC Part #` in the JLCPCB BOM has an explicit decision
      (approved substitute, consignment, or hand assembly)
- [ ] Stock and Basic/Extended class confirmed on JLCPCB itself at quote time —
      `jlcpcb-parts.csv` is a snapshot, and Extended parts carry a setup fee

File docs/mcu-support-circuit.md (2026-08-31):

# PIC18F57Q84 support circuit — design rationale

> **KiCad is the source of truth.** The circuit itself — parts, values, nets,
> footprints, MPNs — lives in the KiCad project
> (`ki_cad_project/farseer/farseer.kicad_pro`), on the **root sheet**
> (`farseer.kicad_sch`, the MCU block) and the **`usb_c` sheet**
> (`usb_c.kicad_sch`, the debug console). This document records only the
> reasoning that a schematic cannot carry: datasheet citations, traps,
> trade-offs, and rejected alternatives. If a value here ever disagrees with
> KiCad, KiCad wins.

Authoritative device source:
`pic_resources/PIC18F27-47-57Q84-Microcontroller-Data-Sheet-DS40002213.pdf`
(**DS40002213F**), plus `pic_resources/PIC18F57Q84-Curiosity-Nano-Schematics.pdf`
for reference values Microchip actually shipped.

> **Package warning.** Every pin claim below is from the **48-pin TQFP** column
> of Table 3-2 / Figure 2-7. The datasheet covers 28/40/44/48-pin parts in the
> same tables; numbers from a smaller package do not apply.

---

## 1. The mandatory-connection list, and the trap that isn't there

§4.1 (DS40002213F p. 18) is explicit: **all VDD and VSS pins** (§4.2) and
**MCLR** (§4.3) must always be connected; ICSPCLK/ICSPDAT, OSC pins, and VREF
only if used. That is the entire list. There is **no VCAP pin** on this device
(the word does not appear in DS40002213F), so no external core-regulator
capacitor is required — a common trap when porting from older PIC families
that do have one.

Two package consequences worth designing around: there is **no separate analog
supply** (no AVDD/AVSS pins), so ADC quality depends entirely on how clean
`3V3_SYS` is at the VDD pins — nothing can be filtered separately. And **VREF
is not a dedicated pin**: precision analog would cost RA2 and/or RA3, which are
general I/O in the current design (RA2/RA3 are `CELL_CTS`/`CELL_RTS`).

## 2. Decoupling (C2, C3, C1, C4, C5)

§4.2.1 (p. 19) makes per-VDD-pair decoupling **required**, not recommended
(Table 3-2 note 5 repeats it). `C2`/`C3` are those caps; `C4`/`C5` are the
optional decade pair; `C1` is the §4.2.2 tank cap.

Layout rules from §4.2.1, all pass/fail at review time:

- Cap must be **low-ESR with self-resonance at 200 MHz or higher**; ceramic.
  This rules out bargain-bin Y5V parts.
- Same side of the board as the MCU; if a via is unavoidable, the pin-to-cap
  trace must be **no longer than 0.25 in (6 mm)**.
- Route power **to the capacitor first, then to the device pin**.
- The VDD/VSS pairs (pins 7/6 and 30/31) are on **opposite corners** of the
  package — two separate placements, one shared cap is not compliant.

§4.2.2 makes the tank cap conditional on power runs longer than six inches.
The run from the `3V3_SYS` buck is short, but the NEO-M9N shares the rail and
the BG95 card is a violent switching load nearby, so `C1` (4.7 µF) is kept
anyway.

## 3. MCLR network (R1, R2, C6, JP1)

The board needs field reprogramming, so §4.3's "tie MCLR to VDD" shortcut does
not apply; the Figure 4-1 network does. Why these values and not others:

- **R1 is 10 kΩ, not the Curiosity Nano's 47 kΩ.** The Nano fits only a 47 kΩ
  pull-up (R200) and no capacitor — evidence the simple version works on a
  debugger-driven board, but Figure 4-1 note 1 says **R1 ≤ 10 kΩ**. Follow the
  datasheet, not the dev board.
- **R2 (series into MCLR) must stay ≤ 470 Ω** (Figure 4-1 note 2): it limits
  current from `C6` into the pin on ESD/EOS breakdown.
- **C6 fights the programmer.** §4.3 warns that programmers drive MCLR with
  fast transitions that must not be adversely affected, and Figure 4-2 answers
  with a jumper — that is what `JP1` is for. If the PICkit complains about VPP
  or target detect, lifting `C6` via `JP1` is the knob to reach for.
- **All MCLR components must sit within 0.25 in (6 mm) of pin 20** (§4.3).
- The internal weak pull-up (MCLRE, and LVP forcing MCLR on) gives a working
  reset but **no ESD/EOS protection and no noise filtering** — it is not a
  substitute for the network.

## 4. ICSP header (J1, R3, R5)

**The tool is a PICkit 5, and it is the programmer *and* the debugger** — ICSP
on RB6/RB7 buys programming, halt/single-step, three hardware breakpoints, and
RAM/SFR watch, forever (DS40002213F p. 6). Nothing on the board changes between
programming and debugging: MPLAB manages the `DEBUG` bit (CONFIG7[5]) itself.

> **JTAG cannot do this.** §39 (p. 884): *"The PIC18-Q84 JTAG module does not
> currently support programming over JTAG."* Boundary scan only. ICSP is the
> sole programming and debug path, which is why §4.4's rule is non-negotiable.

- §4.4 is emphatic about what **not** to add: *"Pull-up resistors, series
  diodes and capacitors on the ICSPCLK and ICSPDAT pins are not recommended."*
  RB6/RB7 carry nothing else on this board; `R3`/`R5` are small series
  resistors within §4.4's "tens of ohms, not exceeding 100 Ω" ESD allowance.
- The 6-pin 0.1 in header is the §48.3 (p. 1064) alternative to the RJ-11; the
  PICkit 5 mates directly, its connector pins 7–8 simply go unused. The
  PICkit 5's own 8-pin body is described in no document under
  `pic_resources/`, so the cited 6-pin footprint is the choice here.

Four things that are not obvious from the pinout and each cost an afternoon:

- **Header pin 2 is VDD *sense*, not VDD *supply*.** Leave MPLAB's *"Power
  target circuit from tool"* **off** and power the board from `VSYS` first.
  The tool's supply is meant for a bare MCU; this board hangs the NEO-M9N,
  two bucks, and a BG95 card capable of 2.7 A bursts off the same system. The
  failure is a confusing target-voltage/target-detect error, not an overload
  message — the single most likely first-attempt failure on a new board.
- **Mark pin 1.** The header is unkeyed; reversing it puts VPP where VSS
  should be. Square pad, silkscreen triangle, `VPP` legend.
- **If the tool complains about VPP or target detect, lift `C6` first**
  (`JP1`, §3 above).
- **LVP is a one-way door at 3.3 V.** `LVP` (CONFIG4[5]) erases to `1`, so the
  board programs from VDD alone — what the PICkit does by default and what we
  want. §48.2: while LVP is enabled the MCLR Reset function cannot be
  disabled, and *"the LVP bit can only be reprogrammed to '0' by using the
  High-Voltage Programming mode."* **Do not clear `LVP` in the project
  configuration** — every session after that needs high-voltage entry on VPP,
  and the §3 RC network is the first thing in its way.

## 5. Clock — HFINTOSC, no crystal

The board runs from HFINTOSC at 64 MHz and fits no crystal. The firmware
already assumes 64 MHz Fosc (see the baud derivation in [uart1.c](../uart1.c):
`64 MHz / (16 × 35) = 114286` for `U1BRG = 34`), every UART is asynchronous
with generous margin, and a crystal would cost pins RA6/RA7 for nothing.

> **Gotcha that will brick bring-up if missed.** CONFIG1 resets to all 1s
> (p. 46): **RSTOSC = 111** means "EXTOSC per FEXTOSC" and **FEXTOSC = 111**
> means "external clock above 8 MHz". A factory-fresh or fully erased part
> comes up expecting an **external clock this board does not have**. CONFIG1
> must be programmed with `RSTOSC = 000` (HFINTOSC 64 MHz, CDIV 1:1) for the
> board to run standalone.

If a crystal is ever retrofitted, §4.5 layout rules apply: same side as the
MCU, ≤ 0.5 in (12 mm) from the pins, load caps immediately next to the
crystal, grounded pour routed to MCU ground with no signal traces inside it.

## 6. Pin budget and unused I/O

Firmware pin assignments and the full 48-pin map are reconciled in
[interconnect-and-pin-budget.md](interconnect-and-pin-budget.md) — the single
place the allocation is checked against the **48-pin** PPS legality tables
(Table 21-1/21-2). Net names in KiCad (`CELL_*`, `GNSS_*`, `USB_TXD/RXD`)
match the firmware.

**Unused I/O:** §4.6 (p. 23) — configure as outputs driven low, or tie to VSS
through 1–10 kΩ. Prefer the firmware approach (free); reserve resistors for
pins left floating at a connector. RF3 is unused (no status LED on this board).

## 7. What the Curiosity Nano had that this board deliberately does not

- ATSAMD21E18 on-board debugger and its 3.3 V LDO — replaced by `J1` +
  PICkit 5 (programming/debug) and the `usb_c` sheet (console).
- MIC5353 adjustable LDO and the USB power path — this board is powered from
  the vehicle rail only; USB is data only.
- 74LVC1T45 level shifters between debugger and target — the Nano needs them
  because its target voltage is adjustable 1.8–5.1 V; our rail is fixed 3.3 V,
  so the bridge talks to the PIC directly.
- The 10 MHz crystal and load caps — see §5.
- The debugger's VTG monitoring, which produced the back-power fault
  documented in [bench-wiring.md](bench-wiring.md). On a custom board with
  shared rails that failure mode disappears.

## 8. Debug console — why the `usb_c` sheet looks the way it does

The console is UART1 on RF0/RF1 at 115200 ([uart1.c](../uart1.c)); on the Nano
those pins went into the debugger's CDC virtual COM port. The custom board
replaces that with `U7`, a Silicon Labs **CP2102N-A02-GQFN24** USB-to-UART
bridge on `usb_c.kicad_sch`
(`datasheets/Silabs_CP2102N_USB-UART_Bridge_DataSheet_Rev1.5.pdf`).

### Why a bridge chip and not USB straight to the PIC

**The PIC18F57Q84 has no USB peripheral.** The peripheral summary tables
(pp. 15–17) list CAN FD, every timer and serial block in the family — and no
USB module. The MCU cannot enumerate under any firmware, so a USB-C port is
only possible via a bridge that does the enumerating. The bridge gives the
**CDC half** of what the Nano's debugger did; programming and hardware debug
stay on `J1` with the PICkit 5.

### Powered from `3V3_SYS`, not from VBUS

USB is **data only** — it never powers the board. Since the board must be
running on `VSYS` for a console to be worth reading anyway, the bridge sits on
`3V3_SYS` too, which buys the important property: **when the vehicle rail is
off, `U7` is unpowered and cannot drive the PIC's pins.** A bus-powered bridge
would stay alive off a plugged-in laptop and drive the PIC's RX pin into an
unpowered MCU, parasitically powering it through input protection — the same
class of failure as the bench back-power fault and the failure u-blox warns
about for the NEO in hardware-backup mode. Self-powering avoids it
structurally rather than by adding parts.

The QFN24 variant was chosen because it carries **separate VIO and VDD pins**
(Table 1.1), letting the whole part sit on `3V3_SYS`. The topology is two
datasheet figures at once:

- **Figure 2.3** (regulator unused): `VREGIN` tied to `VDD` on a 3.0–3.6 V
  input (Table 3.6 note 1 states it outright).
- **Figure 2.6** (self-powered): VBUS reaches the **sense pin only**, through
  the divider `R33`/`R34` (22.1 kΩ / 47.5 kΩ). The bus-powered alternative
  (Figure 2.5, VBUS into `VREGIN`) is exactly the wiring this design avoids.

The divider is mandatory, not a refinement. §2.3: the sense pin's absolute
maximum is **VIO + 2.5 V** while the attach threshold is **VIH = VIO − 0.6 V**,
so at VIO = 3.3 V the tap must land between 2.7 V and 5.8 V —
5 V × 47.5/(22.1 + 47.5) = **3.41 V** does. The same note explains the second
job: the divider's current limit prevents VBUS leakage damage from a live
cable against a **dead board** — in a race car, the normal state of affairs.

Two parts that are easy to leave off, both fitted: the **1 kΩ `RSTb` pull-up
to VIO** (`R35`; §2.1 is unconditional), and **4.7 µF + 0.1 µF at each of the
three power pins** — six capacitors (`C25`–`C30`), not two. The 0.1 µF halves
(`C26`/`C28`/`C30`) stay 0402 GCM X7R. The 4.7 µF halves (`C25`/`C27`/`C29`)
are **0603 GRT188C71C475KE13** (X7S 16 V, AEC-Q200 infotainment): GCM X7R
4.7 µF 16 V does not exist smaller than 0805, and three 0805s will not sit on
the QFN24 power pins. That is a size/rating trade for a debug console, not a
drop of the per-pin pair. The MCU tank `C1` stays the 0805 GCM part.

### USB-C specifics that are easy to get wrong

- **Two 5.1 kΩ CC resistors (`R29`, `R32`), one per CC pin.** One shared
  resistor is a common shortcut and it breaks attach detection.
- **D+/D− to both A6/A7 and B6/B7** on `J4` — a USB-2.0-only receptacle still
  has two data pairs, one per orientation; wire both or the cable only works
  one way up. `U6` (USBLC6-2SC6) carries the ESD on the pairs.
- **The shell gets an RC to ground** (`R25`/`C23`), not a hard short: ESD
  needs a path, but a DC connection between car chassis and laptop ground is a
  loop you do not want in a vehicle.

### The cross, once

`U7` TXD → PIC RF1 (`USB_TXD` net into the PIC's RX) and `U7` RXD ← PIC RF0.
The Nano wires it the same way (DS50003011 Figure 3-1). The names are already
crossed — crossing them a second time in layout is the identical trap to the
BG95's pin 11/13 naming in
[cellular-support-circuit.md](cellular-support-circuit.md).

### The console has to work in both directions

Today the traffic is one-way (`printf` out of RF0). But the server URL should
eventually be field-settable, and the device has **1024 bytes of Data EEPROM**
sitting unused — enough for host, port, and APN many times over, rewritable
without a programmer. What matters at board level:

- **The receive path is not decorative.** `U7` TXD through its series
  resistor to RF1 must stay populated even though nothing currently listens on
  UART1; dropping it makes the console output-only and the EEPROM config path
  unreachable without a PICkit.
- **No auto-reset circuit.** Do not wire DTR/RTS through an RC into MCLR: it
  would put a capacitor on MCLR outside the §3 network, fight the PICkit for
  the pin, and hand a laptop the ability to reset a module in a moving car.
  Reset belongs to `J1`.

---

## 9. Bring-up checklist (process, not values)

- [ ] CONFIG1 programmed with `RSTOSC = 000` — an erased device expects an
      external clock and a crystal-less board will not run
- [ ] MPLAB *"Power target circuit from tool"* left **off**; board powered
      from `VSYS` before the PICkit connects
- [ ] `LVP` left at its erased `1` — clearing it forces high-voltage entry on
      VPP forever after
- [ ] If the programmer objects to the MCLR RC, lift `C6` via `JP1`
- [ ] Every unused pin driven low in firmware or pulled to VSS via 1–10 kΩ
- [ ] All PPS assignments re-checked against the **48-pin** port tables
      (Table 21-1/21-2), not the 28/40-pin columns

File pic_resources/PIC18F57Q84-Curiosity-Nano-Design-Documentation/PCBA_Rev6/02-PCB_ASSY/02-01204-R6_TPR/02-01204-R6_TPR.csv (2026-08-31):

Net | Name | X Coord | Y Coord | Side | Hole Size | Type
 | J100-1 | 7.62mm | 2.3368mm | Bottom | 1mm | Through hole
VCC_VBUS | J100-56 | 7.62mm | 17.9832mm | Bottom | 1mm | Through hole
DBG0 | J100-53 | 15.24mm | 17.5768mm | Bottom | 1mm | Through hole
RF3_LED0 | J100-28 | 76.2mm | 2.7432mm | Bottom | 1mm | Through hole
ID_SYS | J100-2 | 10.16mm | 2.7432mm | Bottom | 1mm | Through hole
VCC_EDGE | J100-51 | 20.32mm | 17.5768mm | Bottom | 1mm | Through hole
RC1 | J100-50 | 22.86mm | 17.9832mm | Bottom | 1mm | Through hole
GND | J100-52 | 17.78mm | 17.9832mm | Bottom | 1mm | Through hole
RC0 | J100-49 | 25.4mm | 17.5768mm | Bottom | 1mm | Through hole
RA5_ANA5 | J100-48 | 27.94mm | 17.9832mm | Bottom | 1mm | Through hole
RB5_ANB5_PWM2/3 | J100-47 | 30.48mm | 17.5768mm | Bottom | 1mm | Through hole
RB4_ANB4_PWM2/3 | J100-46 | 33.02mm | 17.9832mm | Bottom | 1mm | Through hole
RA2_ANA2 | J100-45 | 35.56mm | 17.5768mm | Bottom | 1mm | Through hole
RA1_ANA1 | J100-44 | 38.1mm | 17.9832mm | Bottom | 1mm | Through hole
RA0_ANA0 | J100-43 | 40.64mm | 17.5768mm | Bottom | 1mm | Through hole
GND | J100-42 | 43.18mm | 17.9832mm | Bottom | 1mm | Through hole
RD7 | J100-41 | 45.72mm | 17.5768mm | Bottom | 1mm | Through hole
RD6 | J100-40 | 48.26mm | 17.9832mm | Bottom | 1mm | Through hole
RD5 | J100-39 | 50.8mm | 17.5768mm | Bottom | 1mm | Through hole
RA4 | J100-38 | 53.34mm | 17.9832mm | Bottom | 1mm | Through hole
RF7 | J100-37 | 55.88mm | 17.5768mm | Bottom | 1mm | Through hole
RF6 | J100-36 | 58.42mm | 17.9832mm | Bottom | 1mm | Through hole
RF5 | J100-35 | 60.96mm | 17.5768mm | Bottom | 1mm | Through hole
RF4 | J100-34 | 63.5mm | 17.9832mm | Bottom | 1mm | Through hole
GND | J100-33 | 66.04mm | 17.5768mm | Bottom | 1mm | Through hole
RE1 | J100-32 | 68.58mm | 17.9832mm | Bottom | 1mm | Through hole
RE0 | J100-31 | 71.12mm | 17.5768mm | Bottom | 1mm | Through hole
RA7 | J100-30 | 73.66mm | 17.9832mm | Bottom | 1mm | Through hole
RA6 | J100-29 | 76.2mm | 17.5768mm | Bottom | 1mm | Through hole
CDC_RX | J100-3 | 12.7mm | 2.3368mm | Bottom | 1mm | Through hole
CDC_TX | J100-4 | 15.24mm | 2.7432mm | Bottom | 1mm | Through hole
DBG1 | J100-5 | 17.78mm | 2.3368mm | Bottom | 1mm | Through hole
DBG2 | J100-6 | 20.32mm | 2.7432mm | Bottom | 1mm | Through hole
RD0_UART2/4_TX | J100-7 | 22.86mm | 2.3368mm | Bottom | 1mm | Through hole
RD1_UART2/4_RX | J100-8 | 25.4mm | 2.7432mm | Bottom | 1mm | Through hole
RB2_I2C1_SDA | J100-9 | 27.94mm | 2.3368mm | Bottom | 1mm | Through hole
RB1_I2C1_SCL | J100-10 | 30.48mm | 2.7432mm | Bottom | 1mm | Through hole
RC4_SPI1_MOSI | J100-11 | 33.02mm | 2.3368mm | Bottom | 1mm | Through hole
RC5_SPI1_MISO | J100-12 | 35.56mm | 2.7432mm | Bottom | 1mm | Through hole
RC6_SPI1_SCK | J100-13 | 38.1mm | 2.3368mm | Bottom | 1mm | Through hole
RD4_SPI1_SS | J100-14 | 40.64mm | 2.7432mm | Bottom | 1mm | Through hole
GND | J100-15 | 43.18mm | 2.3368mm | Bottom | 1mm | Through hole
RB0_UART2/4_TX | J100-16 | 45.72mm | 2.7432mm | Bottom | 1mm | Through hole
RB3_UART2/4_RX | J100-17 | 48.26mm | 2.3368mm | Bottom | 1mm | Through hole
RE2 | J100-18 | 50.8mm | 2.7432mm | Bottom | 1mm | Through hole
RC7 | J100-19 | 53.34mm | 2.3368mm | Bottom | 1mm | Through hole
RC2 | J100-20 | 55.88mm | 2.7432mm | Bottom | 1mm | Through hole
RC3 | J100-21 | 58.42mm | 2.3368mm | Bottom | 1mm | Through hole
RD2 | J100-22 | 60.96mm | 2.7432mm | Bottom | 1mm | Through hole
RD3 | J100-23 | 63.5mm | 2.3368mm | Bottom | 1mm | Through hole
RF1_UART1/3/5_RX | J100-26 | 71.12mm | 2.7432mm | Bottom | 1mm | Through hole
RF0_UART1/3/5_TX | J100-25 | 68.58mm | 2.3368mm | Bottom | 1mm | Through hole
GND | J100-24 | 66.04mm | 2.7432mm | Bottom | 1mm | Through hole
RF2 | J100-27 | 73.66mm | 2.3368mm | Bottom | 1mm | Through hole
DBG3 | J100-54 | 12.7mm | 17.9832mm | Bottom | 1mm | Through hole
V\O\F\F\ | J100-55 | 10.16mm | 17.5768mm | Bottom | 1mm | Through hole
SWCLK | J202-1 | 3.19mm | 10.795mm | Bottom | 0mm | Surface mount
GND | J202-2 | 3.19mm | 9.525mm | Bottom | 0mm | Surface mount
VCC_P3V3 | J202-4 | 4.46mm | 9.525mm | Bottom | 0mm | Surface mount
SWDIO | J202-5 | 5.73mm | 10.795mm | Bottom | 0mm | Surface mount
S\R\S\T\ | J202-6 | 5.73mm | 9.525mm | Bottom | 0mm | Surface mount
BOOT | TP202-1 | 12.4mm | 5.777mm | Bottom | 0mm | Surface mount

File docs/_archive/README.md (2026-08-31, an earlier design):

# Archive — pre-KiCad artifacts (NOT a source of truth)

Everything in this folder predates the KiCad project and is **superseded** by
[`ki_cad_project/farseer/`](../../ki_cad_project/farseer/). It is retained only
as project history.

**Do not read anything here as authoritative.** The reference designators in
these files (`C_pic1`, `J_icsp`, `U5`, `FB2`, `C10/C11`, …) no longer exist in
the KiCad schematic, and several values are known-stale (e.g. the GNSS bias
choke is drawn here as 27 nH; the real part is `L4` = 47 nH). Do not cite these
files, and do not reconcile the KiCad project against them.

Contents:

- `*-schematic.{svg,png,pdf}` — hand-drawn schemdraw renders of the five old
  schematic sheets.
- `gen_*_schematic.py`, `schematic_common.py`, `build_schematics.sh` — the
  Python/schemdraw pipeline that produced those renders.
- `mcu-bom.md`, `cellular-bom.md`, `gnss-bom.md`, `power-supply-bom.md` — the
  hand-maintained per-block BOMs.
- `gen_full_bom.py`, `full-bom.md`, `full-bom.csv` — the merged-BOM generator
  and its outputs.

Current sources of truth:

- Circuit, nets, designators, values, footprints, MPNs: the KiCad project
  (`ki_cad_project/farseer/farseer.kicad_pro`).
- Rendered schematic PDF and BOM CSV: `docs/generated/`, regenerated with
  `scripts/export_kicad.sh`.
- Design rationale: the `docs/*-support-circuit.md` files.

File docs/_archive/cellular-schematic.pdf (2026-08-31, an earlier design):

FARSEER CELLULAR SUPPORT CIRCUIT - Quectel BG95-M3, Mini PCIe card

Reference designators shown; component values are in cellular-support-circuit.md

Pin numbers are the 52-pin Mini PCIe edge connector (Mini PCIe Hardware Design V1.0, Table 4)

(1) SOCKET POWER : 3V3_CELL -> VCC_3V3 pins 2, 39, 41, 52

## 3V3_CELL

D_cell

+

C10 / C11 | C12 / C13 | C14 / C15
J2 pin 2 | J2 pin 39 | J2 pin 41 | J2 pin 52

3 x 220 uF polymer
>= 470 uF total | 10 uF + 100 nF | 33 pF + 10 pF

Quectel 3.2: in 2G the input peak current reaches 2.7 A, and a LOW-ESR BYPASS CAPACITOR OF NO LESS THAN 470 uF is required to keep the rail from collapsing. C10/C11 is that reservoir; C12-C15 complete the Figure 3 ladder.
All four VCC_3V3 pins must be fed - they are spread across the connector deliberately, and feeding only one is a current-density mistake. All fourteen GND pins (4, 9, 15, 18, 21, 26, 27, 29, 34, 35, 37, 40, 43, 50) go to plane.
Sizing arithmetic is in power-rail-notes.md. Keep buck A's inductor and switch node away from the antenna run.
(2) J2 SIGNAL MAP : every non-power pin we touch

J2 Mini PCIe socket, 52-pin full size + latch

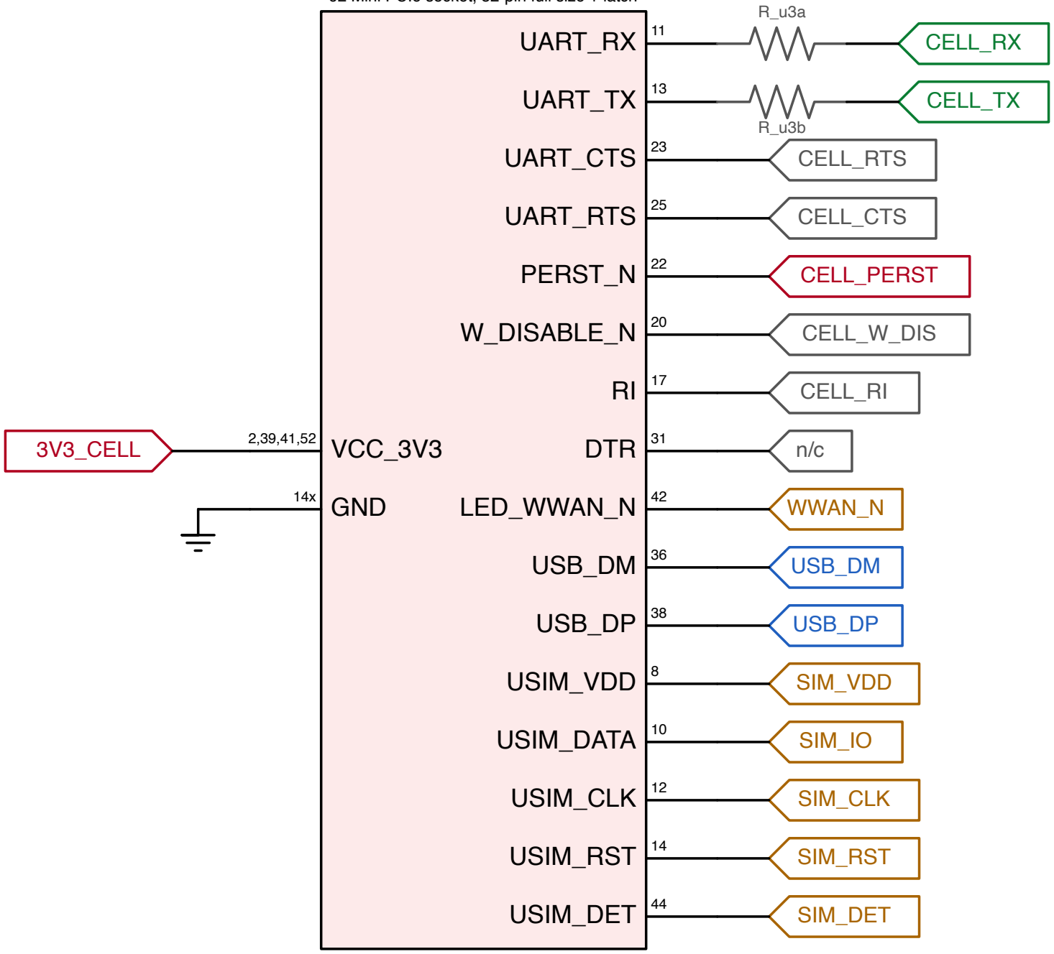
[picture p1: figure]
2,39,41,52 VCC_3V3; 14x GND; 11 UART_RX; 13 UART_TX; 23 UART_CTS; 25 UART_RTS; 22 PERST_N; 20 W_DISABLE_N; 31 DTR; 42 LED_WWAN_N; 36 USB_DM; 38 USB_DP; USIM_VDD; 10 USIM_DATA; 12 USIM_CLK; 14 USIM_RST; 44 USIM_DET; 3V3_CELL

CELL_RX | from PIC RF4 (U3TX) through R_u3a - card RX
CELL_TX | to PIC RF5 (U3RX) through R_u3b - card TX
CELL_RTS | from PIC RF7 (U3RTS) - Opt, flow control off by default
CELL_CTS | to PIC RF6 (U3CTS) - Opt, flow control off by default
CELL_PERST | from PIC RB0, open-drain - VIL <= 0.45 V, hold low 2-3.8 s
CELL_W_DIS | from PIC RB1 - Opt airplane mode, VIL <= 0.45 V
CELL_RI | to PIC RB2 (INT2) - Opt, 120 ms low pulse on a URC
n/c | sleep control - Opt, not routed
WWAN_N | to sheet 4 - open collector, sinks up to 40 mA
USB_DM | to sheet 5 - Opt, 90 ohm differential
USB_DP | to sheet 5 - Opt, 90 ohm differential
SIM_VDD | to sheet 3 - 1.8 V, supplied BY the card
SIM_IO | to sheet 3 - 1.8 V
SIM_CLK | to sheet 3 - 1.8 V
SIM_RST | to sheet 3 - 1.8 V
SIM_DET | to sheet 3 - 1.8 V domain, card-detect, hot-plug via AT+QSIMDET

NO LEVEL SHIFTERS. Table 8 puts UART_RX/TX/CTS/RTS in the 3.3 V power domain and Table 10 does the same for RI, DTR, W_DISABLE# and PERST#, so the 3.3 V PIC wires straight across. Do not fit the TXS0108 the raw-LGA guide
calls for. Only (U)SIM, PCM and I2C are 1.8 V, and none of those reach the MCU.
The UART names are CARD-RELATIVE and therefore ALREADY CROSSED: pin 11 UART_RX is "connect to DTE's TX" and pin 13 UART_TX is "connect to DTE's RX". Wire PIC TX to pin 11 and PIC RX to pin 13; do not cross them a second time.
There is NO PWRKEY on this card. Figure 1 shows an automatic power-on circuit, so the card boots whenever
3V3_CELL is live - boot order is set by buck A's EN pin (PIC RA2, high = on), not by a module key pin.
LEFT UNCONNECTED: WAKE# (1), I2C_SCL/SDA (30, 32), PCM_CLK/DOUT/DIN/SYNC (45, 47, 49, 51), and every RESERVED pin (3, 5, 6, 7, 16, 19, 24, 28, 33, 46, 48). Table 4 note 3: keep all reserved and unused pins unconnected - do NOT ground them "to be safe", since several carry repurposed standard Mini PCIe functions.
(3) (U)SIM HOLDER - 1.8 V only, Quectel Figure 4 (holder with card-detect switch)

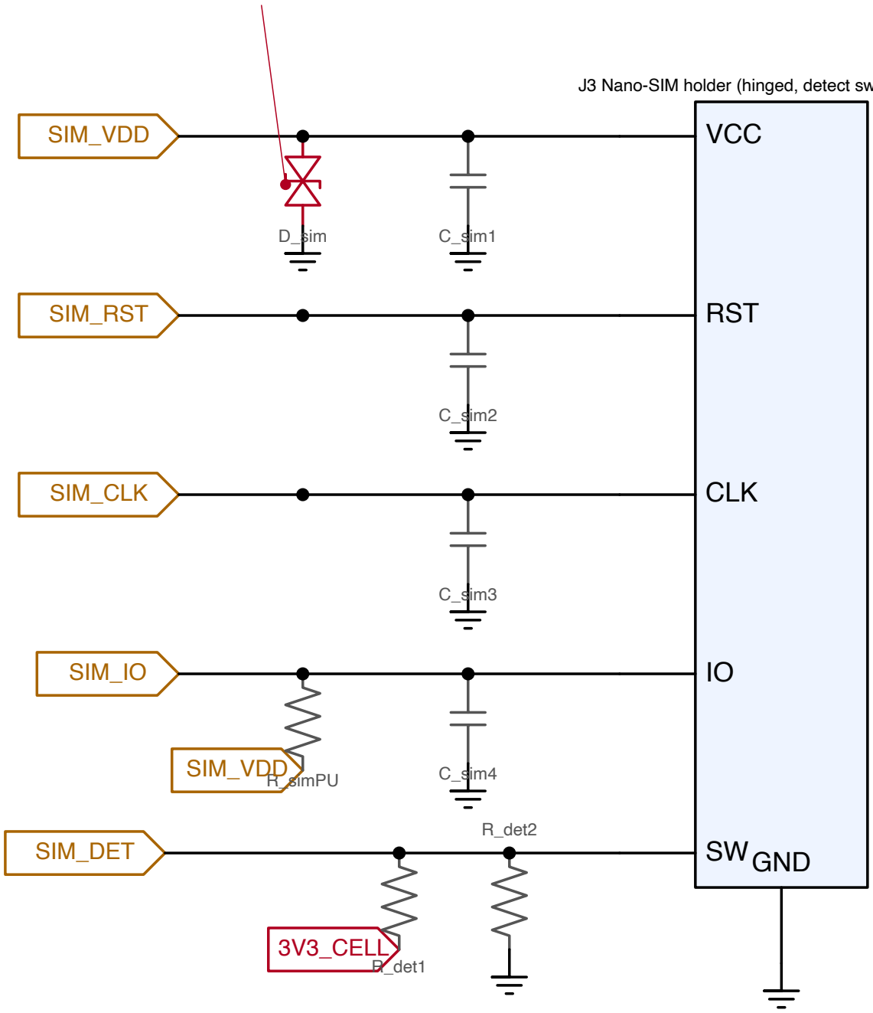
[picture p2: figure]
VCC; RST; CLK; SWGND; D_sim; C_sim1; SIM_VDD; C_sim2; SIM_RST; C_sim3; SIM_CLK; C_sim4 R_simPU SIM_VDD; SIM_IO; R_det2; R_det1; 3V3_CELL; SIM_DET

J3 Nano-SIM holder (hinged, detect switch)

One TVS array, <= 15 pF, covering all four SIM lines at the holder.

The card supplies USIM_VDD itself at 1.8 V; our board provides the holder and the protection network. C_sim1 must NOT exceed 1 uF (3.3) and sits at the holder. The 33 pF caps filter EGSM900 interference. Figure 4's 0 ohm
series links in RST/CLK/DATA (debug aid only) are DELIBERATELY OMITTED - lines run straight to the holder.
The holder is a HINGED type (locking stainless cover, no eject spring to bounce under vibration); the Hologram triple-cut SIM is punched to the nano (4FF) cut.
CARD DETECT: the switch closes SW to the grounded shell when the card is seated, so SIM_DET reads low = inserted. Quectel Figure 4 pulls USIM_DET to an always-on 1.8 V rail, which this card does not export - R_det1/R_det2 divide 3V3_CELL to ~1.65 V instead, inside the 1.8 V domain VIH window (Table 23). Hot-plug is DISABLED BY DEFAULT: firmware sends AT+QSIMDET=1,0 (low = inserted, NV-saved) and AT+QSIMSTAT=1 for insertion/removal URCs. Layout, all mandatory at review: holder as close to the socket as possible with trace length under 200 mm; SIM signals kept away from RF and power-supply traces; ground between socket and holder short and wide, >= 0.5 mm; USIM_DATA and USIM_CLK separated and shielded by surrounding ground. The holder is the only user-accessible connector on this subsystem, so it is the realistic ESD entry point - D_sim is Req, not Rec.
(4) LED_WWAN# - network status, pin 42, open collector, active low

## 3V3_SYS

R_wwan

D_wwan

WWAN_N to J2 pin 42

R_wwan IS NOT OPTIONAL if D_wwan is fitted: 3.7.4 says a resistor MUST be placed in series, and the pin will sink up to 40 mA and cook the LED without it. 1 kOhm gives about 2 mA. Default pattern (AT+QCFG="ledmode",0): 200 ms low / 1800 ms high = searching, 1800 / 200 = registered and idle, 125 / 125 = data transfer - readable across a paddock.

(5) USB - pins 36 / 38, optional, firmware update path

## USB_DM

R_usb1
D_usb

L_usb

## J_usb

## USB_DP

R_usb2

## J_usb

R_usb1/2 are 0 ohm and NOT MOUNTED by default (Figure 6) - they exist so the pair can be broken out to test points. L_usb is a common-mode choke and belongs close to the socket. Route as a 90 ohm differential pair with ground surround, never under crystals, oscillators, magnetics or RF traces, preferably on an inner layer.

(6) RF AND MECHANICAL - no host-board parts
RF: NOTHING on our board. The card carries its own 50 ohm main antenna connector and the antenna mates directly to it - no 50 ohm trace, no matching network, no antenna feed on the host PCB. What the board must provide is mechanical: clearance above the card for the U.FL-LP plug and its cable bend radius, a route to the enclosure bulkhead, and strain relief. In a race car that cable sees vibration continuously - anchor it.
Mechanical: 51.0 x 30.0 mm full-size card, standard 52-pin Mini PCIe socket (e.g. Molex 679105700) WITH latch. In a vehicle the latch is structural, not convenience; add a retaining screw or bracket. Operating range tops out at +75 C (extended +80 C), which an enclosure near a transmission tunnel can exceed - plan the mounting spot.

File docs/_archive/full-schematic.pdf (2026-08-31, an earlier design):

FARSEER - WHOLE-BOARD SCHEMATIC

In-car race telemetry module: PIC18F57Q84 + BG95-M3 Mini PCIe (UDP uplink / downlink) + NEO-M9N GNSS

Sheet 0 is the system overview and the cross-board net list. Sheets A-D are the four detail schematics, unchanged, each generated from its own script and matching its own BOM 1:1.

(0) SYSTEM OVERVIEW - every inter-block connection. Pin numbers: U1 = 48-pin TQFP, J2 = 52-pin Mini PCIe edge, U4 = 24-pin LCC. Wires that cross WITHOUT a dot are not connected.

J1
VBAT_IN
7-18 V

F1 Q1 D1
fuse, reverse polarity,
load-dump TVS, pi filter

U2 TPS54560-Q1
buck 3.3 V, >= 4 A

U3 LMR16006X
buck 3.3 V, ~0.6 A

VSYS

U1 PIC18F57Q84-I/PT
48-pin TQFP
HFINTOSC 64 MHz,
no crystal fitted

J2 BG95-M3
Mini PCIe socket, 52-pin
LTE-M / NB-IoT / EGPRS
no PWRKEY: boots with its rail

J3
Nano-SIM, 1.8 V

LTE antenna
U.FL, on the card

U4 NEO-M9N-00B
24-pin LCC
SAW + LNA + band 13 notch, internal DC block and match

GNSS antenna
J_gnss + bias-T

U5 CP2102N-A02
USB-UART bridge,
runs from 3V3_SYS

J_dbg
USB-C
console only

USB CDC,
data only

J_icsp 6-pin ICSP
PICkit 5: program + debug

3V3_CELL - absorbs the 2.7 A 2G bursts

3V3_SYS

FB2, DCR < 0.2 ohm | VCC ramp must land in 66 us - 26.4 ms

UART3 115200 + PERST# / W_DISABLE# / RI 7 nets

UART2 38400 then 115200 + RESET_N + 1 PPS 4 nets

UART1 console, 115200 2 nets

ICSPDAT / ICSPCLK / MCLR_N 3 nets

CELL_PWR_EN
RA2 (23) -> buck A EN
HIGH = rail on = modem on

CROSS-BOARD NET LIST - every signal crossing a block boundary. No level shifters anywhere: the card's UART and control pins are 3.3 V, and the NEO shares the PIC's rail.

U1 <-> J2 BG95-M3 Mini PCIe socket

CELL_RX | RF4 (12) -> J2 pin 11 UART_RX | 220 ohm series
CELL_TX | RF5 (13) <- J2 pin 13 UART_TX | 220 ohm series
CELL_RTS | RF7 (15) -> J2 pin 23 UART_CTS | Opt
CELL_CTS | RF6 (14) <- J2 pin 25 UART_RTS | Opt
CELL_PERST | RB0 (8) -> J2 pin 22 PERST# | open-drain, 2-3.8 s
CELL_W_DIS | RB1 (9) -> J2 pin 20 W_DISABLE# | Opt
CELL_RI | RB2 (10) <- J2 pin 17 RI | Opt, INT2 wake

Card-relative names, ALREADY CROSSED: pin 11 is "connect to
the DTE's TX". Do not cross the pair a second time.

U1 <-> U4 NEO-M9N

GNSS_RX | RD0 (42) -> U4 pin 21 RXD
GNSS_TX | RD1 (43) <- U4 pin 20 TXD
GNSS_RESET | RB3 (11) -> U4 pin 8 RESET_N | open-drain
GNSS_1PPS | RC2 (40) <- U4 pin 3 TIMEPULSE | CCP1, 30 ns RMS

No hardware flow control exists on the NEO-M9N. TIMEPULSE is
routed even though the firmware does not use it yet: hardware
capture beats UART arrival time by orders of magnitude for
tying a position fix to lap timing.

U1 <-> U5 / J_icsp console and programming

DBG_TX | RF0 (36) -> U5 RXD (20) | 220 ohm series
DBG_RX | RF1 (37) <- U5 TXD (21) | 220 ohm series
ICSPDAT | RB7 (19) <-> J_icsp pin 4
ICSPCLK | RB6 (18) <-> J_icsp pin 5
MCLR_N | RE3 (20) <- J_icsp pin 1 VPP
CELL_PWR_EN | RA2 (23) -> buck A EN | HIGH = rail on

U5 TXD already drives the PIC RX - do not cross again.
Programming and in-circuit debug are J_icsp with a PICkit 5;
the PIC18F57Q84 has no USB peripheral, so USB-C is console only.

RAILS. VBAT_IN 7-18 V -> VSYS -> two independent bucks. 3V3_CELL absorbs the BG95's 2.7 A 2G bursts; 3V3_SYS stays quiet for the PIC, the NEO-M9N and the USB bridge, so a transmit burst cannot brown out the MCU or the GNSS receiver. Both rails are 3.3 V and must stay 3.3 V - raising either one breaks cross-rail logic levels. Single ground plane throughout.

BOOT ORDER. Buck B is always enabled, so the PIC and the NEO-M9N come up together and can never drive each other while one is unpowered. Buck A's EN pull-down holds the modem off while the PIC is in reset; the PIC then drives CELL_PWR_EN high and the card auto-powers on - there is no PWRKEY on this card. PERST# is for recovering a wedged modem, not for boot.

READING SHEETS A-D. Within them, connections are made by NET-LABEL TAG rather than by long wires, and the same tag name on two tiles is the same net: 3V3_SYS on sheet A is the same copper as 3V3_SYS on sheets B and D. Reference designators only are printed; component values live in the matching BOM markdown. Pin budget and PPS checks: interconnect-and-pin-budget.md.

FARSEER POWER RAILS - detailed schematic

Reference designators shown; component values are in power-supply-bom.md

(1) VEHICLE INPUT -> PROTECTION -> VSYS

VBAT_IN (J1)
F1
S | D

G

Q1 (rev-pol)

R1
Dz1 | D1

C0

FB0

VSYS

C2/C3

+

## C1 VSYS

(2) BUCK A U2 TPS54560-Q1 : VSYS -> 3.3 V (>=4 A, 2G-capable) -> 3V3_CELL

## VIN

EN

## BOOT

SW

## FB RT SS COMP GND

U2

C_inA

## VSYS

R_enA

## EN <- PIC GPIO

R_rt

C_ss

R_cmp

C_cmp

## FBA

C_boot

D2

L1
C_outA | 3V3_CELL R_fbA1

R_fbA2 FBA

(3) BUCK B U3 LMR16006X : VSYS -> 3.3 V (~0.6 A) -> 3V3_SYS (comp + soft-start internal)

## VIN

EN

## BOOT

SW

## FB GND

U3

C_inB

## VSYS

EN

EN floats = ON. Optional R_enB 100k -> VSYS, or a divider to set a custom UVLO.

## FBB

C_boot

D3

L2
C_outB | 3V3_SYS R_fbB1

R_fbB2 FBB

(4) 3V3_CELL -> BG95-M3 MINI PCIe SOCKET

## 3V3_CELL

+

C10/C11 | C12/C13 | 3V3

## W_DIS

## PERST

## UART_USB

## USIM

## GND

J2 Mini PCIe

3V3 = pins 2,39,41,52 | USIM = 1.8 V

## J3 SIM

Card is self-contained: on-card VBAT regulation, RF/BB decoupling + ferrite are INSIDE the module. The raw-module VBAT star network (ferrite + MLCC arrays + 2x TVS) is NOT built on our board.

(5) 3V3_SYS -> PIC VTG + NEO-M9N (ferrite-isolated GNSS branch)

## 3V3_SYS

C_pic | PIC VTG

FB2

C_neo | C_bkp | NEO VCC

(A) POWER RAILS component values in power-supply-bom.md

FARSEER MCU SUPPORT CIRCUIT - PIC18F57Q84, 48-pin TQFP

Every resistor and capacitor shows its VALUE next to the reference designator. MPN / status / cost: mcu-bom.md

All pin numbers are the 48-pin TQFP column (DS40002213F Figure 2-7 / Table 3-2)

(1) U1 PIC18F57Q84-I/PT : every connected pin

7

## VDD

30

## VDD

6

## VSS

31

## VSS

20

## MCLR

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
U1 PIC18F57Q84-I/PT 48-pin TQFP

## 3V3_SYS

## 3V3_SYS

## MCLR_N

DBG_TX | to U5 RXD - console TX (U1TX)
DBG_RX | from U5 TXD - console RX (U1RX)
GNSS_RX | to NEO-M9N pin 21 RXD (U2TX)
GNSS_TX | from NEO-M9N pin 20 TXD (U2RX)
GNSS_RESET | to NEO-M9N pin 8 RESET_N, open-drain
GNSS_1PPS | from NEO-M9N pin 3 TIMEPULSE (CCP1 capture)
CELL_RX | to J2 pin 11 UART_RX (U3TX)
CELL_TX | from J2 pin 13 UART_TX (U3RX)
CELL_CTS | from J2 pin 25 UART_RTS (U3CTS, Opt)
CELL_RTS | to J2 pin 23 UART_CTS (U3RTS, Opt)
CELL_PERST | to J2 pin 22 PERST#, open-drain
CELL_W_DIS | to J2 pin 20 W_DISABLE# (Opt)
CELL_RI | from J2 pin 17 RI (INT2, Opt)
CELL_PWR_EN | to buck A EN - HIGH = rail on
ICSPCLK | to J_icsp pin 5 - keep clear of everything else
ICSPDAT | to J_icsp pin 4 - keep clear of everything else
LED0 | status LED, drives low to light

No AVDD / AVSS and no VCAP on this device, so ADC quality depends entirely on how clean 3V3_SYS is at pins 7 and 30 - there is no analog supply to filter separately, and VREF is not a dedicated pin (it would
cost RA2 / RA3). Unused I/O: drive low in firmware (DS40002213F 4.6) or tie to VSS through 1-10 kOhm.
(2) SUPPLY AND DECOUPLING : 0.1 uF per VDD pin, REQUIRED (DS40002213F 4.2.1)

## 3V3_SYS

C_picBulk
4.7 uF / 16 V X7R

C_pic1
0.1 uF X7R

C_pic2
0.1 uF X7R

C_picHF1/2
1 nF (Opt, DNP) | U1 VDD
VDD 7 / VSS 6 | VDD 30 / VSS 31 | only if HF noise is observed

Pins 7/6 and 30/31 sit on OPPOSITE CORNERS of the package, so these are two genuinely separate placements -one shared cap is not compliant. Each cap: ceramic, self-resonant at 200 MHz or above, same side of the board as the MCU, trace no longer than 6 mm, and power routed to the CAP FIRST and then on to the device pin.

(3) MCLR RESET NETWORK (DS40002213F Figure 4-1)

## 3V3_SYS

R_mclr1
10 kOhm

R_mclr2
220 Ohm
MCLR_N | to U1 pin 20 (RE3 / VPP)

C_mclr
0.1 uF

JP_mclr
(lift C_mclr)

Lift C_mclr here if the programmer objects to the RC (Figure 4-2). A no-fit pad on C_mclr does the same job for free.

All three parts within 6 mm of pin 20 (4.3). R_mclr1 <= 10 kOhm and R_mclr2 <= 470 Ohm are datasheet limits,
not suggestions: R_mclr2 caps the current C_mclr can dump into MCLR during an ESD/EOS breakdown. The Curiosity Nano fits 47 kOhm and no capacitor, which violates R1 <= 10 kOhm - follow the datasheet, not the dev board.
(4) ICSP PROGRAM + DEBUG HEADER - PICkit 5 (Microchip PICkit pinout, Figures 48-1 / 48-2)

1

## VPP

2

## VDD_T

3

## VSS

4

## PGD

5

## PGC

6
NC

J_icsp 6-pin 0.1 in header

## MCLR_N

## 3V3_SYS

SENSE ONLY - leave "Power target circuit from tool" OFF in MPLAB. The board runs the NEO-M9N, two bucks and a 2.7 A BG95 card; the PICkit cannot supply it, and reports a target-voltage error if asked.

pin 1: square pad + silkscreen triangle (the header is unkeyed)

R_icsp1
47 Ohm (Opt)R_icspPD1
47 kOhm | ICSPDAT | to U1 RB7, pin 19

R_icsp2
47 Ohm (Opt)

R_icspPD2
47 kOhm | ICSPCLK | to U1 RB6, pin 18

no connect

DS40002213F 4.4 is emphatic about what NOT to add: no pull-UPS, series diodes, or capacitors on ICSPCLK / ICSPDAT - they interfere with programmer communications. R_icsp1/2 are ESD series only and must not exceed 100 Ohm; the 47 kOhm pull-DOWNS are what Microchip debug tooling expects. Nothing else may share RB6 / RB7.

THIS HEADER IS BOTH PROGRAMMER AND DEBUGGER, permanently, not a manufacturing fixture. The device offers In-Circuit Debug with three breakpoints over the SAME two pins (DS40002213F p. 6); MPLAB clears DEBUG (CONFIG7[5]) for a debug session and no board change is needed. JTAG is not an alternative - 39 states the
PIC18-Q84 JTAG module does not support programming. Leave LVP (CONFIG4[5]) at its erased 1: clearing it
forces high-voltage VPP entry from then on, and only HV programming can ever set it back.
(5) DEBUG CONSOLE - USB-C to CP2102N-A02-GQFN24, CDC virtual COM port (console half of the Curiosity Nano debugger, DS50003011 3.1.2)

A4/B9

## VBUS

A6/B6
D+

A7/B7
D-

A5
CC1

B5
CC2

A1/B12

## GND

## SHELL

J_dbg USB-C, 16-pin, USB 2.0 only

1
IO1

6

## IO1b

3
IO2

4

## IO2b

5

## VBUS

2

## GND

D_dbg USBLC6-2SC6 SOT-23-6

C_dbg4
1 uF

R_vbus1
22.1 kOhm

R_vbus2
47.5 kOhm | VBUS_DET

Divider REQUIRED (CP2102N 2.3): 22.1k/47.5k -> 3.41 V at U5 pin 8. D_dbg pin 5 clamps raw VBUS (this node), not VBUS_DET.

## USB_DP

## USB_DM

D_dbg (USBLC6-2SC6) pin hookup - wire BOTH pins of each I/O pair: pin 1 I/O1 -+
pin 6 I/O1 -+- USB_DP = J_dbg D+ (A6/B6) = U5 D+ (pin 3)
pin 3 I/O2 -+
pin 4 I/O2 -+- USB_DM = J_dbg D- (A7/B7) = U5 D- (pin 4)
pin 5 VBUS ---- J_dbg VBUS (A4/B9) -> R_vbus1/R_vbus2 -> VBUS_DET -> U5 VBUS (pin 8) pin 2 GND ---- GND

R_cc1
5.1 kOhm

R_cc2
5.1 kOhm

R_shield
1 MOhm

C_shield
4.7 nF / 2 kV
R_shield || C_shield: ESD reaches ground,
but the car chassis and the laptop share no DC path

3
D+

4
D-

8

## VBUS

7

## VREGIN

6

## VDD

5

## VIO

9

## RSTb

21

## TXD

20

## RXD

2

## GND

U5 CP2102N-A02-GQFN24

## USB_DP

## USB_DM

## VBUS_DET

C_dbg1a
4.7 uF

C_dbg1b
0.1 uF

## 3V3_SYS

C_dbg2a
4.7 uF

C_dbg2b
0.1 uF

## 3V3_SYS

C_dbg3a
4.7 uF

C_dbg3b
0.1 uF
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

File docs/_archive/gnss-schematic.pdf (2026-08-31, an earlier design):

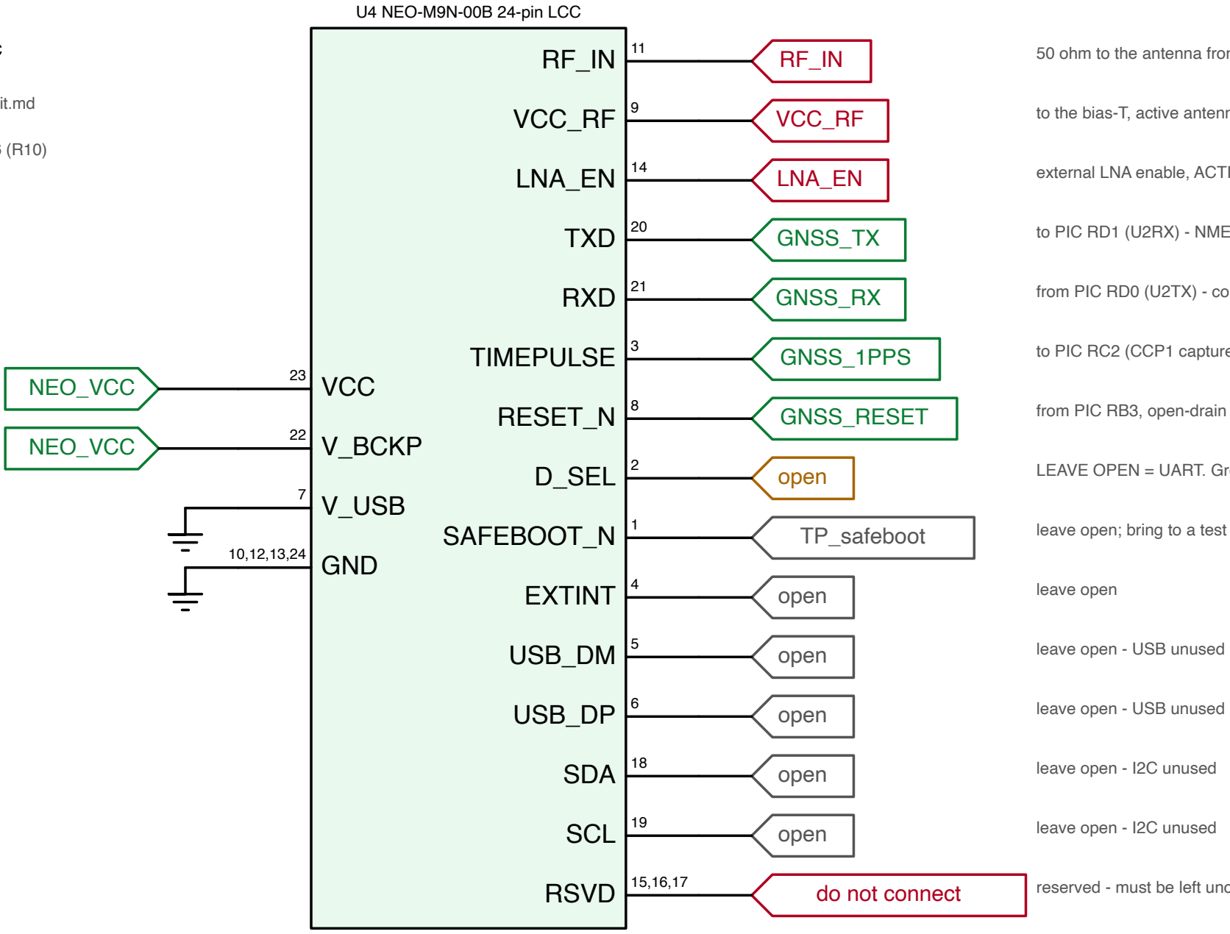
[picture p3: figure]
23 VCC; 22 V_BCKP; V_USB; 10,12,13,24 GND; VCC_RF; 14 LNA_EN; 20 TXD; 21 RXD; TIMEPULSE; RESET_N; D_SEL; SAFEBOOT_N; EXTINT; USB_DM; USB_DP; 18 SDA; 19 SCL; 15,16,17 RSVD; U4 NEO-M9N-00B 24-pin LCC; NEO_VCC; open; leave open; leave open - USB unused; leave open - I2C unused

FARSEER GNSS SUPPORT CIRCUIT - u-blox NEO-M9N-00B, 24-pin LCC

Reference designators shown; component values are in gnss-support-circuit.md

Sources: datasheet UBX-19014285 and integration manual UBX-19014286 (R10)

(1) U4 NEO-M9N-00B : all 24 pins, with the board action for each
RF_IN | 50 ohm to the antenna front end - no DC block, no matching
VCC_RF | to the bias-T, active antenna only - VCC - 0.1 V, 50 mA
LNA_EN | external LNA enable, ACTIVE HIGH - active antenna only
GNSS_TX | to PIC RD1 (U2RX) - NMEA out, 38400 then 115200
GNSS_RX | from PIC RD0 (U2TX) - configuration in
GNSS_1PPS | to PIC RC2 (CCP1 capture) - 1 PPS, 30 ns RMS, 4 mA
GNSS_RESET | from PIC RB3, open-drain - internal 7-13 kOhm pull-up
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

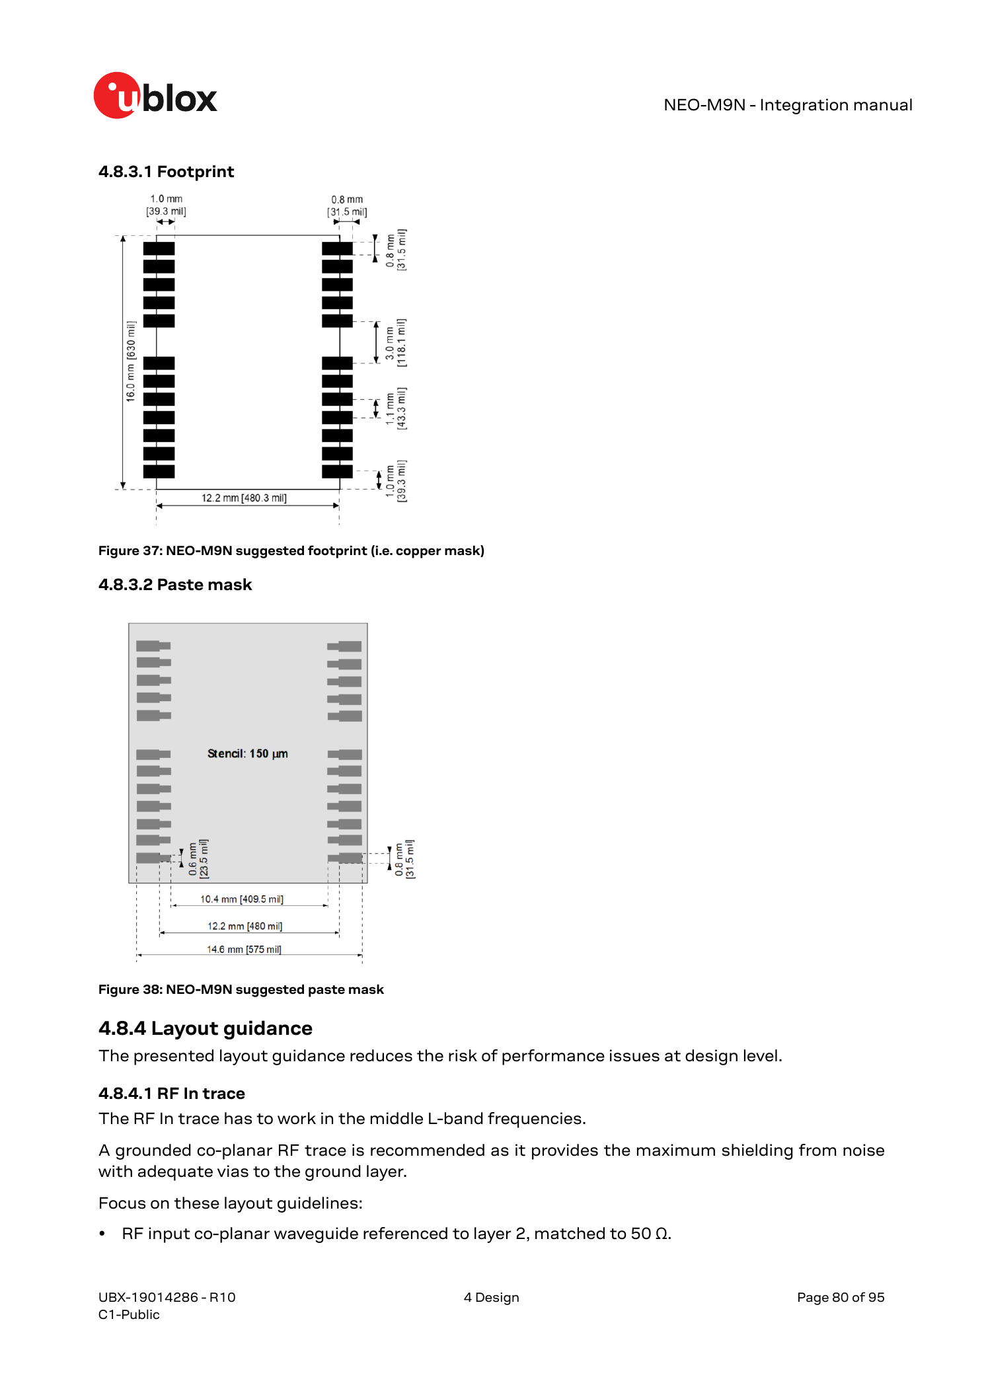
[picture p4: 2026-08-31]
neo-m9n-im-80.png

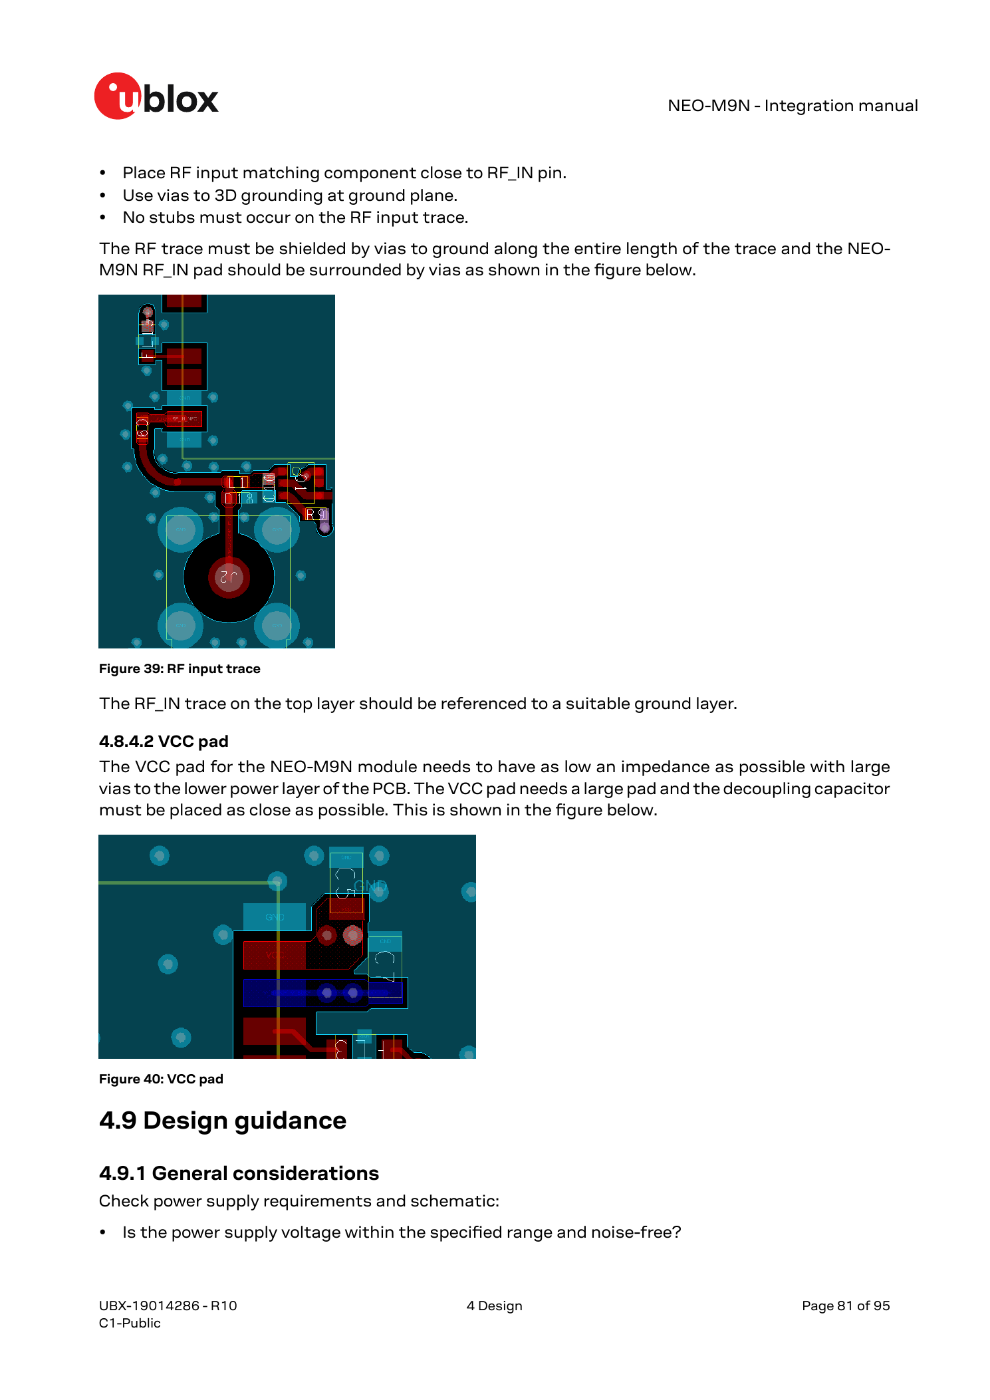
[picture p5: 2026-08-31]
neo-m9n-im-81.png

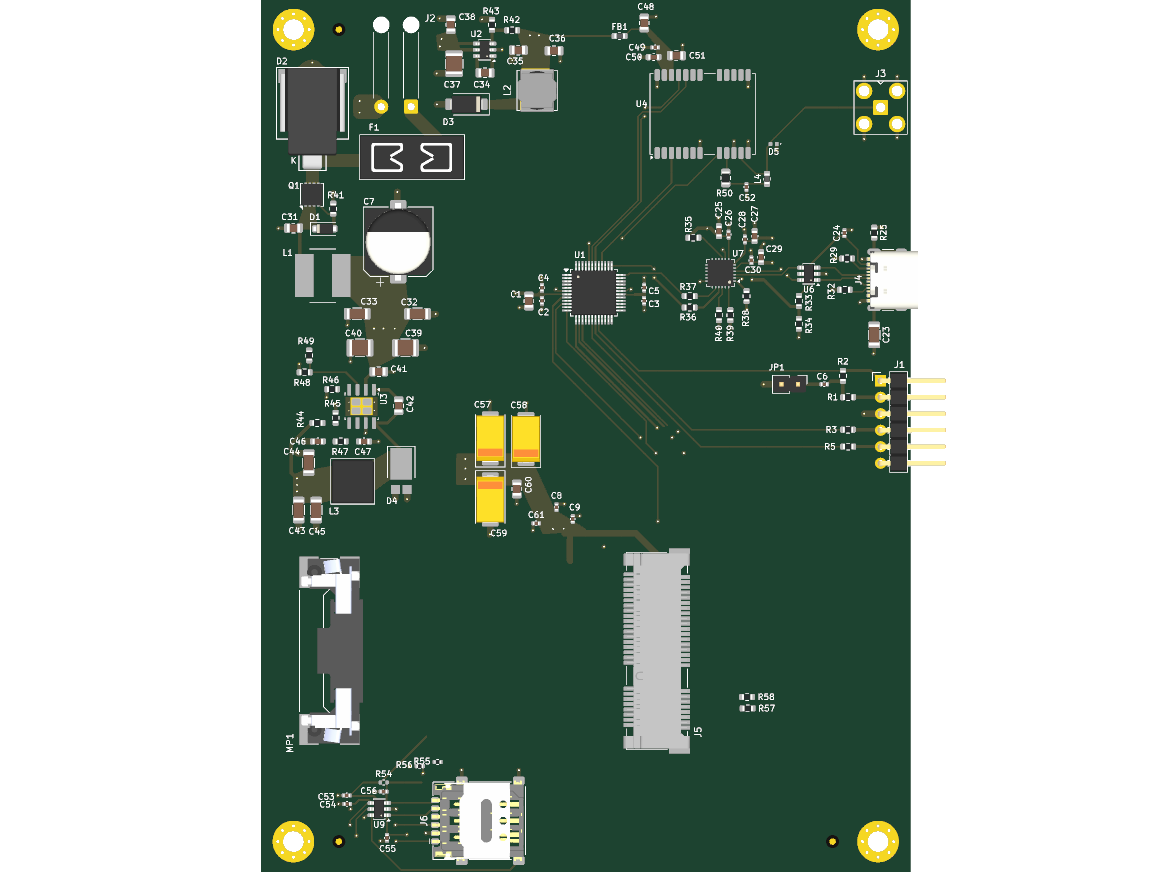
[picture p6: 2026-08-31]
out/mp1-model-check.png

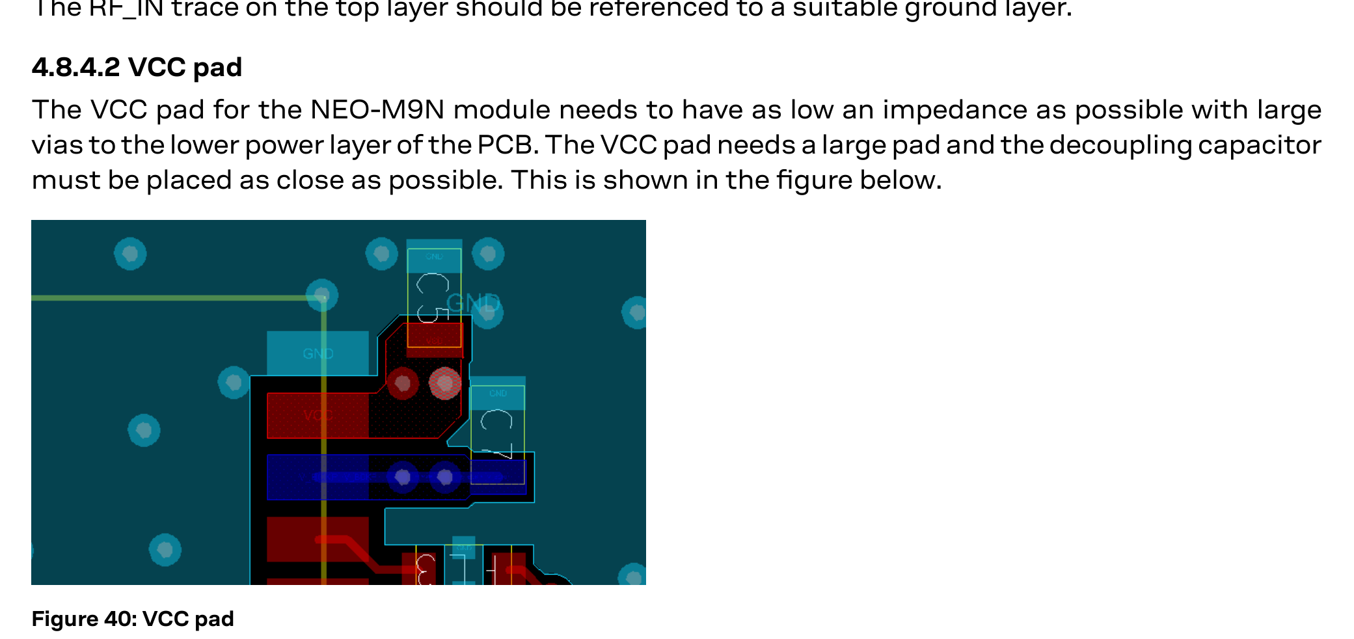
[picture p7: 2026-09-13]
out/im-fig40-c.png

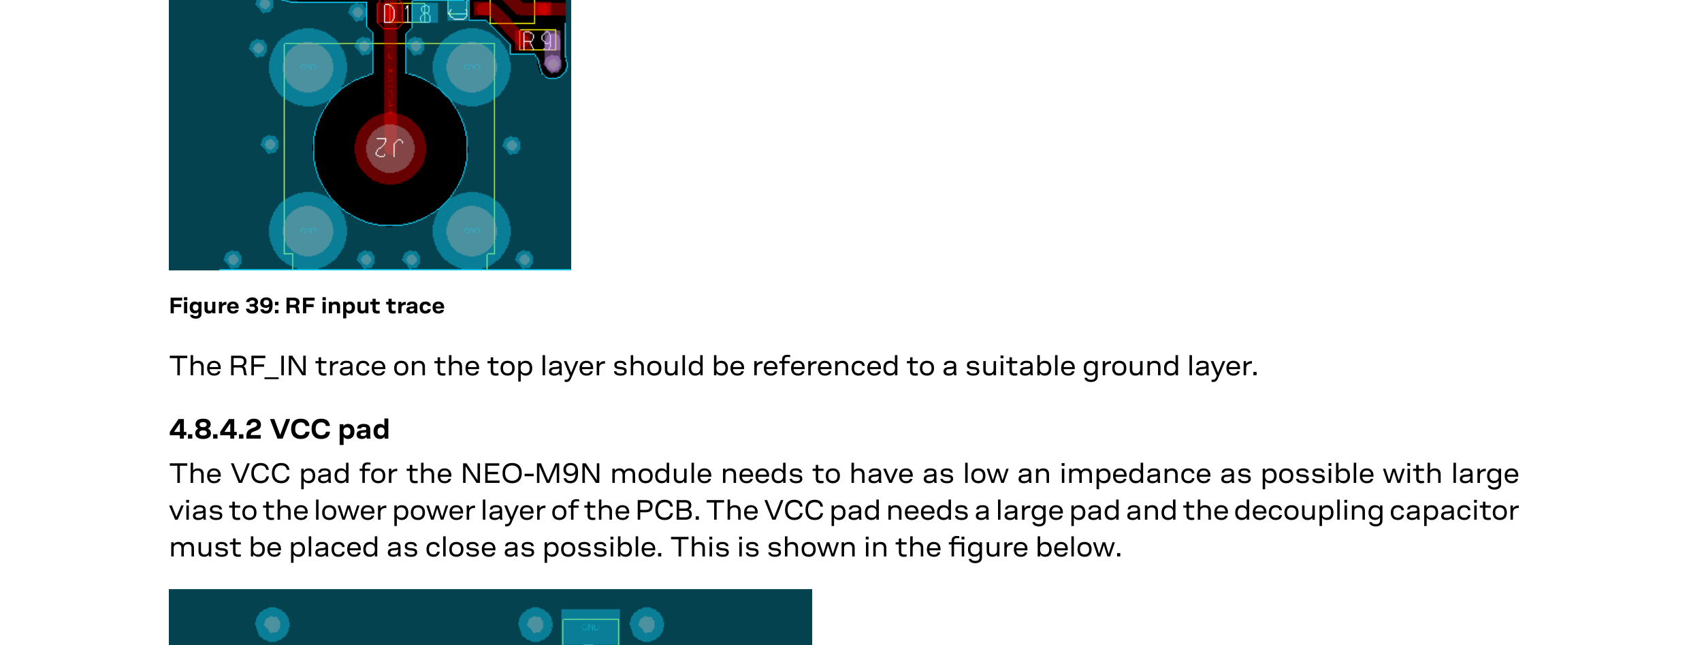
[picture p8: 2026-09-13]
out/im-fig40-tight.png

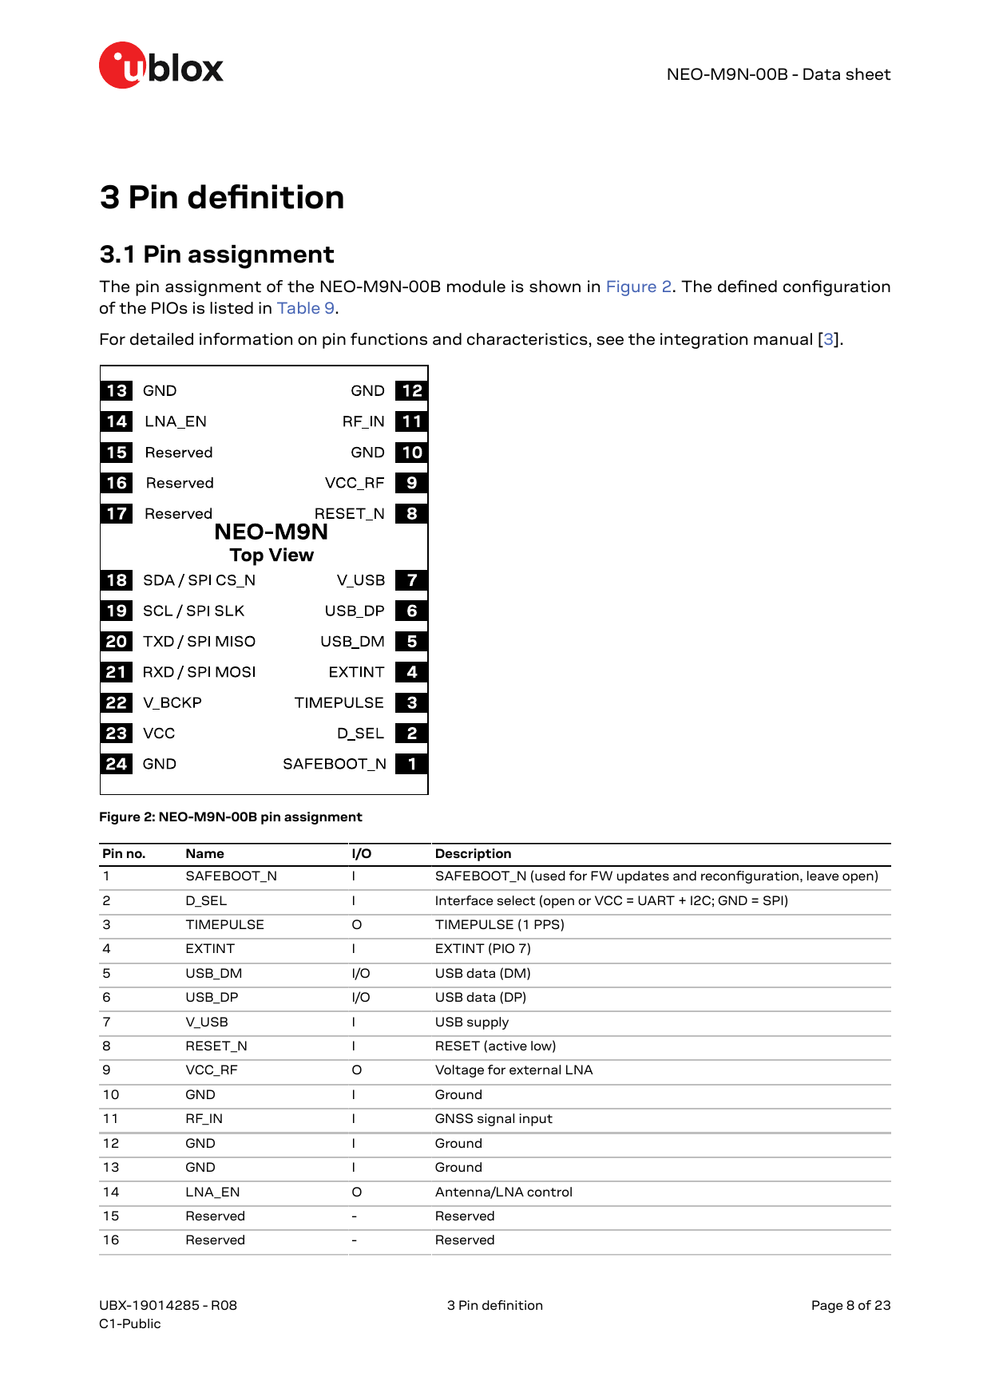
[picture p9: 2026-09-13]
out/ds-pin-08.png

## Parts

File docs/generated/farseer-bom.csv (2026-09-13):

Reference | Value | Footprint | MPN | Manufacturer | Alt MPN | Description | DNP
C1 | 4u7 | Capacitor_SMD:C_0805_2012Metric | GCM21BR71C475KA73L | Murata |  | Unpolarized capacitor
C2,C3,C6,C26,C28,C30 | 0u1 | Capacitor_SMD:C_0402_1005Metric | GCM155R71E104KE02D | Murata |  | Unpolarized capacitor
C4,C5 | 1n | Capacitor_SMD:C_0402_1005Metric | GCM155R71H102KA37D | Murata |  | Unpolarized capacitor
C7 | 100u | Capacitor_SMD:CP_Elec_10x10.5 | EEH-ZA1H101P | Panasonic |  | Polarized capacitor
C8 | 10p | Capacitor_SMD:C_0402_1005Metric | GCM1555C1H100JA16D | Murata |  | Unpolarized capacitor
C9,C54-C56 | 33p | Capacitor_SMD:C_0402_1005Metric | GCM1555C1H330JA16D | Murata |  | Unpolarized capacitor
C23 | 4n7 | Capacitor_SMD:C_1206_3216Metric | C1206C472KGRACAUTO | KEMET |  | Unpolarized capacitor
C24 | 1u | Capacitor_SMD:C_0402_1005Metric | GCM155R71C105KA55D | Murata |  | Unpolarized capacitor
C25,C27,C29 | 4u7 | Capacitor_SMD:C_0603_1608Metric | GRT188C71C475KE13D | Murata |  | Unpolarized capacitor
C31 | 1u | Capacitor_SMD:C_0805_2012Metric | GCM21BR71H105KA03L | Murata |  | Unpolarized capacitor
C32,C33 | 2u2 | Capacitor_SMD:C_1206_3216Metric | GCM31CR71H225KA55L | Murata |  | Unpolarized capacitor
C34,C42 | 100n | Capacitor_SMD:C_0805_2012Metric | GCM21BR71H104KA37L | Murata |  | Unpolarized capacitor
C35,C36 | 22u | Capacitor_SMD:C_0805_2012Metric | GCM21BR61A226ME36L | Murata |  | Unpolarized capacitor
C37 | 4u7 | Capacitor_SMD:C_1210_3225Metric | GCM32ER71H475KA55L | Murata |  | Unpolarized capacitor
C38,C41 | 0u1 | Capacitor_SMD:C_0805_2012Metric | GCM21BR71H104KA37L | Murata |  | Unpolarized capacitor
C39,C40 | 10u | Capacitor_SMD:C_1210_3225Metric | GCM32ER71H106KA03L | Murata |  | Unpolarized capacitor
C43-C45 | 22u | Capacitor_SMD:C_1206_3216Metric | GCM31CR71C226KE02L | Murata |  | Unpolarized capacitor
C46 | 56n | Capacitor_SMD:C_0603_1608Metric | GCM188R71H563KA55D | Murata |  | Unpolarized capacitor
C47 | 330p | Capacitor_SMD:C_0603_1608Metric | GCM1885C1H331JA16D | Murata |  | Unpolarized capacitor
C48,C51,C60 | 10u | Capacitor_SMD:C_0805_2012Metric | GCM21BR71C106KE22L | Murata |  | Unpolarized capacitor
C49,C52,C53,C61 | 100n | Capacitor_SMD:C_0402_1005Metric | GCM155R71C104KA55D | Murata |  | Unpolarized capacitor
C50 | 1u | Capacitor_SMD:C_0603_1608Metric | GCM188R71C105KA64D | Murata |  | Unpolarized capacitor
C57-C59 | 220u | Capacitor_Tantalum_SMD:CP_EIA-7343-31_Kemet-D | T525D227M006ATE025 | KEMET |  | Polarized capacitor
D1 | BZT52B10 | Diode_SMD:D_SOD-123F | BZT52B10Q-7 | Diodes Incorporated |  | 500mW Zener Diode, SOD-123F
D2 | SM8S26A | farseer_footprints:Littelfuse_DO-218AB | SM8S26A | Littelfuse |  | TVS diode, unidirectional, 26V standoff, 31.9V max breakdown, 42.1V clamp @ 167A, 7000W 10/1000us, load dump, SMTO-263 (DO-218AB compatible)
D3 | B160Q | Diode_SMD:D_SMA | B160Q-13-F | Diodes Incorporated |  | 60V 1A Schottky Diode, SMA
D4 | SBR8U60P5 | farseer_footprints:D_PowerDI-5_SBR8U60P5 | SBR8U60P5-13 | Diodes Incorporated |  | Super Barrier Rectifier, 60V 8A, Vf 0.46V @ 8A, PowerDI5 with bottom-side cathode heat sink
D5 | PESD0402-140 | farseer_footprints:D_0402_1005Metric_PESD0402-140 | PESD0402-140 | Littelfuse |  | Bidirectional transient-voltage-suppression diode
F1 | 5A | Fuse:Fuseholder_Blade_Mini_Keystone_3568 | 0297005.WXNV | Littelfuse |  | Fuse
FB1 | 600R@100MHz | Inductor_SMD:L_0603_1608Metric | BLM18KG601SZ1D | Murata |  | Ferrite bead
J1 | Conn_PIC_ICSP_ICD | Connector_PinHeader_2.54mm:PinHeader_1x06_P2.54mm_Horizontal | 61300611021 | Wurth Elektronik |  | Microchip PIC In-Circuit Serial Programming/Debugging (ICSP/ICD) connector
J2 | Conn_01x02 | Connector_Wire:SolderWire-0.5sqmm_1x02_P4.6mm_D0.9mm_OD2.1mm_Relief |  |  |  | Generic connector, single row, 01x02, script generated (kicad-library-utils/schlib/autogen/connector/)
J3 | SMA_RA_TH_50R | farseer_footprints:SMA_Amphenol_901-143_Horizontal | 132136 | Amphenol RF | 901-143-6RFX | coaxial connector (BNC, SMA, SMB, SMC, Cinch/RCA, LEMO, ...)
J4 | USB_C_Receptacle_USB2.0_16P | Connector_USB:USB_C_Receptacle_GCT_USB4105-xx-A_16P_TopMnt_Horizontal | USB4105-GF-A | GCT |  | USB 2.0-only 16P Type-C Receptacle connector
J5 | BG95-M3_MiniPCIe | farseer_footprints:Molex_67910-5700_MiniPCIe | 679105700 | Molex | ATTEND 119A-56A00-R02 (5.6 mm H, spec 119A-XXA00-R02); JAE MM60-52-B1-E1 - both standard CEM r1.2 land pattern; verify vendor product drawing and stack height before substituting | Mini PCIe socket, 52-pin, full-size, with latch - hosts Quectel BG95-M3 LPWA modem card. Pinout per Quectel Mini PCIe HW design Table 4 (NOT generic PCIe names)
J6 | SIM8060-6-1-14-00 | farseer_footprints:nanoSIM_GCT_SIM8060-6-1-14-00 | SIM8060-6-1-14-00-A | GCT |  | Nano-SIM (4FF) holder, hinged locking cover, 6 contacts + normally-open card-detect switch (SW closes to grounded shell when card seated)
JP1 |  | Connector_PinHeader_2.54mm:PinHeader_1x02_P2.54mm_Vertical | 61300211121 | Wurth Elektronik |  | Jumper, 2-pole, closed/bridged
L1 | 4u7 | farseer_footprints:L_Bourns_SRN8040TA | SRN8040TA-4R7M | Bourns |  | Inductor with ferrite core
L2 | 22u | farseer_footprints:L_Bourns_SRN6045TA | SRN6045TA-220M | Bourns |  | Inductor
L3 | 10u | Inductor_SMD:L_Coilcraft_XAL6060-XXX | XAL6060-103MEC | Coilcraft |  | Inductor
L4 | 47n | Inductor_SMD:L_0603_1608Metric | LQW18AN47NG00D | Murata |  | Inductor
MP1 | MiniPCIe_Latch | farseer_footprints:Molex_48099-5701_MiniPCIe_Latch | 48099-5701 | Molex |  | Optional Molex 48099-5701 Mini PCIe retention latch with four grounded shield/anchor pads
Q1 | DMP6023LFGQ | Package_SON:Diodes_PowerDI3333-8 | DMP6023LFGQ-13 | Diodes Incorporated |  | P-channel MOSFET, -60V, -7.7A, 25mOhm @ -10V, AEC-Q101, reverse-polarity pass FET, PowerDI3333-8
R1,R38-R40,R43,R45 | 10k | Resistor_SMD:R_0603_1608Metric | AC0603FR-0710KL | Yageo |  | Resistor, US symbol
R2,R36,R37,R57,R58 | 220 | Resistor_SMD:R_0603_1608Metric | AC0603FR-07220RL | Yageo |  | Resistor, US symbol
R3,R5 | 47 | Resistor_SMD:R_0603_1608Metric | AC0603FR-0747RL | Yageo |  | Resistor, US symbol
R25 | 1M | Resistor_SMD:R_0603_1608Metric | AC0603FR-071ML | Yageo |  | Resistor, US symbol
R29,R32 | 5k1 | Resistor_SMD:R_0603_1608Metric | AC0603FR-075K1L | Yageo |  | Resistor, US symbol
R33 | 22k1 | Resistor_SMD:R_0603_1608Metric | AC0603FR-0722K1L | Yageo |  | Resistor, US symbol
R34 | 47k5 | Resistor_SMD:R_0603_1608Metric | AC0603FR-0747K5L | Yageo |  | Resistor, US symbol
R35,R49 | 1k | Resistor_SMD:R_0603_1608Metric | AC0603FR-071KL | Yageo |  | Resistor, US symbol
R41,R48,R51 | 100k | Resistor_SMD:R_0603_1608Metric | AC0603FR-07100KL | Yageo |  | Resistor, US symbol
R42 | 33k2 | Resistor_SMD:R_0603_1608Metric | AC0603FR-0733K2L | Yageo |  | Resistor, US symbol
R44 | 31k6 | Resistor_SMD:R_0603_1608Metric | AC0603FR-0731K6L | Yageo |  | Resistor, US symbol
R46 | 200k | Resistor_SMD:R_0603_1608Metric | AC0603FR-07200KL | Yageo |  | Resistor, US symbol
R47 | 13k3 | Resistor_SMD:R_0603_1608Metric | AC0603FR-0713K3L | Yageo |  | Resistor, US symbol
R50 | 22 | Resistor_SMD:R_0805_2012Metric | ERJ-P06J220V | Panasonic |  | Resistor, US symbol
R54 | 15k | Resistor_SMD:R_0402_1005Metric | AC0402FR-0715KL | Yageo |  | Resistor, US symbol | DNP
R55,R56 | 51k | Resistor_SMD:R_0402_1005Metric | AC0402FR-0751KL | Yageo |  | Resistor, US symbol
U1 | PIC18F57Q84 | farseer_footprints:TQFP-48-1EP_7x7mm_P0.5mm_EP3.5x3.5mm_ThermalVias | PIC18F57Q84-I/PT | Microchip |  | 8-bit PIC18 microcontroller, 128kB Flash, 8kB RAM, CAN FD, 48-pin TQFP 7x7mm
U2 | LMR16006X | Package_TO_SOT_SMD:TSOT-23-6 | LMR16006XDDCR | Texas Instruments |  | Buck converter, 4-60V in, 0.6A, 0.7MHz (X), internal compensation and soft-start, 3V3_SYS rail (U2), SOT-23-THIN 6 (DDC)
U3 | TPS54560-Q1 | farseer_footprints:SOIC-8-1EP_3.9x4.9mm_P1.27mm_EP2.95x4.9mm_Mask2.71x3.4mm_ThermalVias | TPS54560QDDARQ1 | Texas Instruments |  | Buck converter, 4.5-60V in, 5A, non-synchronous, adjustable frequency, AEC-Q100, 3V3_CELL rail (U3), HSOIC-8 PowerPAD (DDA)
U4 | NEO-M9N | farseer_footprints:ublox_NEO-M9N-00B | NEO-M9N-00B | u-blox |  | u-blox NEO-M9N-00B standard precision GNSS module, 2.7 V to 3.6 V VCC
U6 | USBLC6-2SC6 | Package_TO_SOT_SMD:SOT-23-6 | USBLC6-2SC6Y | STMicroelectronics |  | Very low capacitance ESD protection diode, 2 data-line, SOT-23-6
U7 | CP2102N-Axx-xQFN24 | Package_DFN_QFN:QFN-24-1EP_4x4mm_P0.5mm_EP2.6x2.6mm | CP2102N-A02-GQFN24 | Silicon Labs |  | USB to UART master bridge, QFN-24
U9 | TPD4E02B04DQA | Package_SON:USON-10_2.5x1.0mm_P0.5mm | TPD4E02B04DQAR | Texas Instruments |  | 4-Channel ESD Protection Diode for USB Type-C and HDMI 2.0, USON-10

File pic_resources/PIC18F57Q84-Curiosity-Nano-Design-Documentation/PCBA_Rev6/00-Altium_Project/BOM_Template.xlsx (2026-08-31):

 | Component list |  | Field=ProjectTitle
 | PCBA Number: |  | Field=ProjectPCBAssyNumber
 | PCBA Revision: |  | Field=ProjectPCBAssyRevision
 | Variant: |  | Field=VariantName
 | Print Date: | Field=CurrentDate | Field=CurrentTime
Column=Fitted | Column=Designator | Column=Quantity | Column=Value | Column=Manufacturer 1 | Column=Manufacturer Part Number 1 | Column=Description_
 |  | Field=TotalQuantity
Approved |  |  | Notes

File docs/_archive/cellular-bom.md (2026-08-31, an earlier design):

# Farseer cellular BOM

Bill of materials for the cellular circuit drawn in `cellular-schematic.pdf`
(generated by `gen_cellular_schematic.py`). Design rationale, the full 52-pin
socket map, and datasheet citations live in
[cellular-support-circuit.md](cellular-support-circuit.md) — this file is the
**single source of truth for parts and values**; that one explains *why*.

Scope: everything the host board provides for a **BG95-M3 Mini PCIe card**, fed
from the `3V3_CELL` rail designed in [power-supply-bom.md](power-supply-bom.md).

Authoritative source:
`datasheets/Quectel_BG95-M3_Mini_PCIe_Hardware_Design_V1.0.pdf` — the **only**
document with the 52-pin edge-connector assignment and the card's power domains.
Do **not** use `quectel_bg95_series_hardware_design_v1-6.pdf`: that describes the
raw 102-pin LGA module inside the card, whose pin numbers and 1.8 V levels do not
apply at this socket.

**Status column** matches `power-supply-bom.md`: **Req** mandatory, **Rec**
strongly recommended, **Opt** genuine choice.

> Three things that are **not** on our BOM because they are integrated on the
> card: the 3.8 V VBAT regulation, the RF/BB decoupling and VBAT star network,
> and the antenna connector. Section 1 of `cellular-support-circuit.md` covers
> why. `J2`, `C10`–`C15`, and `J3` are also listed in `power-supply-bom.md` §4 —
> **same physical parts**, do not order twice.
>
> [full-bom.md](full-bom.md) merges all four BOMs into one ordering list with
> that overlap already resolved. Regenerate it with
> `python3 docs/gen_full_bom.py` after any change here.

---

## 1. Mini PCIe socket and rail decoupling

§3.2 governs: *"In 2G network, the input peak current may reach **2.7 A**...
a **low-ESR bypass capacitor no less than 470 µF** should be used."* Quectel's
Figure 3 reference puts 470 µF + 100 nF + 33 pF + 10 pF at `VCC_3V3`.

| Ref | Qty | Status | Value / description | Suggested MPN (datasheet) | Notes |
|-----|-----|---|---|---|---|
| J2 | 1 | Req | Mini PCIe socket, **52-pin, full-size**, with latch | Molex 679105700 (Quectel's own reference, Figure 19) | Card supply on `VCC_3V3` pins **2, 39, 41, 52** — **not pin 24, which is RESERVED** on this card despite being 3.3Vaux in the Mini PCIe standard. GND on 4, 9, 15, 18, 21, 26, 27, 29, 34, 35, 37, 40, 43, 50 (Table 6) |
| C10, C11 | **3** | Req | Bulk reservoir **3 × 220 µF = 660 µF**, ≥ 6.3 V, low-ESR polymer, **effective ESR ≤ 10 mΩ** | Panasonic SP-Cap / Kemet T520 | Sources the TX burst locally at the socket. Sizing math in [power-rail-notes.md](power-rail-notes.md); paralleled to divide ESR and ESL |
| C12, C13 | 2 | Req | 10 µF 16 V X7R (0805) + 100 nF 0402 | generic | HF decoupling at the socket power pins |
| C14, C15 | 2 | Rec | 33 pF + 10 pF, 0402 | generic | Completes the Figure 3 cap ladder |
| D_cell | 1 | Rec | TVS on `3V3_CELL`, low clamp above 3.6 V | select clamp < card abs max (verify) | Socket-local clamp — the front-end TVS `D1` is far away at the harness entry |

Placement constraint from §3.2 that is decided at layout, not at order time: keep
buck A's inductor, catch diode, and switch-node copper **away from the antenna
connector and cable run**. For thermal sizing, LTE Cat M1 TX is far gentler
(235–260 mA avg, 495–618 mA max, Table 21) — **the 2.7 A figure is the 2G/EGPRS
case**, and it is what sets the rail.

---

## 2. (U)SIM interface — §3.3, Figure 4

Only **1.8 V (U)SIM cards are supported**; the card supplies `USIM_VDD` itself.
Everything here belongs **at the holder**, not at the socket. Built from
**Figure 4 (holder with card-detect switch)** — the detect switch is wired to
`USIM_DET` (pin 44) for hot-plug recovery, so the 6-pin Figure 5 variant no
longer applies. The holder is a **hinged type** chosen for in-car vibration:
the stainless cover locks over the card (lock force ≥ 1.5 N, unlock ≤ 10 N;
shock-tested at 490 m/s² and vibration-tested per the GCT spec), unlike a
push-push holder whose eject spring a hard shock can actuate. The SIM itself is
a **Hologram Hyper triple-cut card punched to the nano (4FF) cut** — 1.62–5.5 V,
so 1.8 V-compatible, industrial grade −40 to +105 °C.

| Ref | Qty | Status | Value / description | Suggested MPN (datasheet) | Notes |
|-----|-----|---|---|---|---|
| J3 | 1 | Req | Nano-SIM holder, **hinged locking cover**, 6 contacts + detect switch | **GCT SIM8060-6-1-14-00-A** | Normally-open switch closes `SW` to the grounded shell when the card is seated → `SIM_DET` low = inserted |
| C_sim1 | 1 | Req | **100 nF**, 0402, `USIM_VDD` → GND | Murata GRM155R71C104KA88D | §3.3: decoupling **must not exceed 1 µF** and must sit close to the holder |
| C_sim2..4 | 3 | Req | **33 pF**, 0402, one per RST / CLK / DATA to GND | Murata GRM1555C1H330JA01D | Filters EGSM900 interference |

Deliberate deviation from Figure 4: the 0 Ω series links Quectel draws in
RST / CLK / DATA (a cut/isolate debug aid, no electrical function) are
**omitted** — the lines run straight from the socket to the holder.
| D_sim | 1 | Req | TVS array, **parasitic capacitance ≤ 15 pF** | **TI TPD4E02B04DQAR** (~0.25 pF/ch, USON-10) | At the holder, on VDD / IO / CLK / RST. The 15 pF ceiling is the selection criterion |
| R_det1, R_det2 | 2 | Req | **51 kΩ**, 0402 — `SIM_DET` divider from `3V3_CELL` | Yageo RC0402FR-0751KL | See detect note below |
| R_simPU | 1 | Opt | **15 kΩ** 0402 to `USIM_VDD` | Yageo RC0402FR-0715KL | Pull-up on `USIM_DATA`; improves anti-jamming on long or noisy traces. Value per Figure 4/5; fit **DNP** by default |

**Card-detect divider (R_det1/R_det2).** Quectel's Figure 4 pulls `USIM_DET` up
to an always-on **1.8 V** rail through 51 kΩ, but the Mini PCIe card exports no
such rail — only `USIM_VDD`, which the modem may power down when no SIM is
present, which would corrupt the detect level exactly when it matters. A
51 k / 51 k divider from `3V3_CELL` synthesises ~1.65 V on `SIM_DET`, inside
the 1.2–2.0 V VIH window of the 1.8 V domain (Table 22/23); the holder switch
shorts the node to GND when a card is seated. Hot-plug is **disabled by
default** (§3.3) — firmware enables it once with `AT+QSIMDET=1,0` (low =
inserted; saved to NV, effective after reboot) plus `AT+QSIMSTAT=1` for removal
URCs.

The SIM holder is the **only user-accessible connector** on this subsystem, so it
is the realistic ESD entry point and the one place protection is mandatory.
Layout rules (all pass/fail at review): trace length **< 200 mm**, ground between
socket and holder **≥ 0.5 mm wide**, `USIM_DATA` and `USIM_CLK` separated and
shielded by ground, and the whole group kept away from RF and the switching rail.

---

## 3. UART to the PIC — §3.5

Direct connection, **3.3 V both ends, no level shifters anywhere**. Default
115200 8N1, matching [uart3.c](../uart3.c).

| Ref | Qty | Status | Value / description | Suggested MPN (datasheet) | Notes |
|-----|-----|---|---|---|---|
| R_u3a, R_u3b | 2 | Rec | 220 Ω 0603 | generic | Series on `CELL_RX` / `CELL_TX`. Both ends now share a board, so the back-power case from [bench-wiring.md](bench-wiring.md) is gone; these remain useful for edge-rate and ESD control |

Nets, no parts: PIC RF4 (pin 12, U3TX) → socket pin **11**; socket pin **13** →
PIC RF5 (pin 13, U3RX). The signal names in Table 4 are **card-relative and
already crossed** — do not cross them a second time. `UART_CTS` (23) and
`UART_RTS` (25) are Opt; flow control is off by default and firmware does not use
it, but route them to spare pins if the budget allows since they cannot be
retrofitted.

---

## 4. Control and indication

| Ref | Qty | Status | Value / description | Suggested MPN (datasheet) | Notes |
|-----|-----|---|---|---|---|
| R_perst | 1 | Rec | 10 kΩ 0603 to `3V3_SYS` | generic | Belt-and-braces pull-up on `PERST#` (pin 22); holds reset released while the PIC is itself in reset. The card already pulls up |
| TP_perst | 1 | Rec | Test point | generic | A 2–3.8 s reset pulse is worth being able to scope |
| D_wwan | 1 | Opt | LED, low-current, 0603 | generic | `LED_WWAN#` (pin 42), open collector, active low |
| R_wwan | 1 | **Req if D_wwan fitted** | **1 kΩ** 0603 from `3V3_SYS` | generic | §3.7.4: *"a resistor must be placed in series with the LED."* ≈2 mA at 3.3 V. **Do not omit** — the pin sinks up to 40 mA and will cook the LED |

`PERST#` is the only reset available. Drive it from a PIC GPIO, **open-drain**
(toggle `TRIS` against the card's pull-up) so the idle state is defined while the
PIC is in reset. Reset needs a low of **≥ 2 s and ≤ 3.8 s**, at **VIL ≤ 0.45 V** —
tighter than the general 3.3 V I/O spec. Implement that delay in the existing
non-blocking state machine in [bg95.c](../bg95.c), never as a busy-wait.

The default LED pattern is a genuinely useful trackside diagnostic — 200 ms
low / 1800 ms high is *searching*, the inverse is *registered idle*, and
125/125 ms is *data transfer*. Worth the two parts.

Left NC by design: `W_DISABLE#` (20, function disabled by default and `AT+CFUN=4`
does the same job) and all PCM and I2C pins. `USIM_DET` (44) is **no longer NC**
— it is wired to the SIM holder's detect switch (§2) for hot-plug recovery.
`RI` (17) and `DTR` (31) are Opt — routing `RI` to an interrupt-on-change pin
would let firmware stop polling for downlink URCs.

---

## 5. USB — Opt, §3.4

Not needed for operation, but it is the **firmware-upgrade path** for the modem.
Fitting a header means the card can be re-flashed without desoldering.

| Ref | Qty | Status | Value / description | Suggested MPN (datasheet) | Notes |
|-----|-----|---|---|---|---|
| L_usb | 1 | Rec | Common-mode choke, USB 2.0 rated | Würth WE-CNSW or equivalent | §3.4 recommends one in series for EMI. **Place close to the socket** |
| D_usb | 1 | Rec | Low-capacitance ESD array, 2-line | select for low C on a 90 Ω pair | Per Figure 6 |
| R_usb1, R_usb2 | 2 | Opt | 0 Ω 0402, **not mounted by default** | generic | Series to test points, per Figure 6 |
| J_usb | 1 | Opt | USB connector or 4-pin header | generic | Firmware-update access |

Routing: **90 Ω differential** with ground surround, not under crystals,
oscillators, magnetics, or RF traces, preferably on an inner layer, stubs
minimal.

---

## 6. Mechanical

| Ref | Qty | Status | Value / description | Suggested MPN (datasheet) | Notes |
|-----|-----|---|---|---|---|
| MP1, MP2 | 2 | Req | Card standoffs / mounting posts for a full-size card | per socket vendor | Card is 51.0 × 30.0 mm (§7.2) |
| MP3 | 1 | Rec | Retaining screw or bracket, in addition to the latch | generic | In a vehicle the latch is structural. A card that walks out of its socket over a race weekend takes the telemetry link with it |
| — | 0 | Req | U.FL-LP mating plug, clearance, and cable strain relief | §5.4 recommends the U.FL-LP family | **The antenna connector is on the card** — no 50 Ω trace on our PCB. What the board owes is bend-radius clearance (Figure 16), a cable path to the bulkhead, and an anchor against continuous vibration. The pigtail and antenna themselves are ordered from [external-bom.md](external-bom.md) |

Operating range tops out at **+75 °C** (extended +80 °C). An enclosure near a
transmission tunnel can exceed that — plan mounting location and airflow.

---

## Approximate cost (qty 1, USD, distributor list — order of magnitude)

| Block | Rough cost |
|---|---|
| J2 Mini PCIe socket + standoffs | ~$2–4 |
| Bulk reservoir (3× 220 µF polymer) + HF caps | ~$4–7 |
| SIM holder + protection network | ~$2–4 |
| UART / PERST# / LED parts | ~$0.75 |
| USB option (choke, ESD, connector) | ~$2–3 |
| **Total (excluding the BG95-M3 card and antenna)** | **~$10–18** |

The polymer reservoir caps are the surprise line item; they are what the 2.7 A
2G burst costs. Budget separately for the BG95-M3 Mini PCIe card itself and the
LTE antenna.

---

## Verify before ordering

- [ ] All four `VCC_3V3` pins (2, 39, 41, 52) fed, all fourteen GND pins to plane
- [ ] Every RESERVED pin genuinely **unconnected** — not grounded (Table 4 note 3)
- [ ] Reservoir is **≥ 470 µF with effective ESR ≤ 10 mΩ** at the socket
- [ ] No level shifters anywhere on the UART — the card is 3.3 V at this connector
      (Table 8)
- [ ] PIC TX → pin **11**, PIC RX → pin **13** (names are card-relative; do not
      cross twice)
- [ ] `PERST#` drive meets **VIL ≤ 0.45 V**, and firmware holds it low 2–3.8 s
- [ ] `LED_WWAN#` has its 1 kΩ series resistor if the LED is fitted
- [ ] SIM: 100 nF ≤ 1 µF at holder, 3× 33 pF, TVS ≤ 15 pF, GND ≥ 0.5 mm,
      trace < 200 mm, DATA and CLK separated and shielded (0 Ω series links
      deliberately omitted)
- [ ] `USIM_DET` wired to the holder switch through the 51 k / 51 k divider;
      firmware sends `AT+QSIMDET=1,0` (polarity must match the wiring)
- [ ] PCM and I2C left NC
- [ ] Buck A switch node and inductor kept away from the antenna connector and
      cable route (§3.2 EMI warning)
- [ ] `3V3_CELL` still **3.3 V nominal** — see cellular-support-circuit.md §3
      before anyone "adds margin"
- [ ] Socket latch **plus** secondary retention for vibration
- [ ] Rebuild the drawing with `./docs/build_schematics.sh cellular` after any
      change here

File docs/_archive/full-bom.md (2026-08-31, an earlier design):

# Farseer whole-board BOM

**Generated — do not edit.** Written by `gen_full_bom.py` from the four
per-block BOMs, which remain the single source of truth for parts and
values. Change a part there and re-run `python3 docs/gen_full_bom.py`.

| Block | Source BOM | Rationale | Schematic |
|---|---|---|---|
| Power | [power-supply-bom.md](power-supply-bom.md) | [power-rail-notes.md](power-rail-notes.md) | [power-rails-schematic.pdf](power-rails-schematic.pdf) |
| MCU | [mcu-bom.md](mcu-bom.md) | [mcu-support-circuit.md](mcu-support-circuit.md) | [mcu-schematic.pdf](mcu-schematic.pdf) |
| Cellular | [cellular-bom.md](cellular-bom.md) | [cellular-support-circuit.md](cellular-support-circuit.md) | [cellular-schematic.pdf](cellular-schematic.pdf) |
| GNSS | [gnss-bom.md](gnss-bom.md) | [gnss-support-circuit.md](gnss-support-circuit.md) | [gnss-schematic.pdf](gnss-schematic.pdf) |

Everything on one sheet: [full-schematic.pdf](full-schematic.pdf).
A flat version of the table below, for a spreadsheet or a distributor
upload, is in [full-bom.csv](full-bom.csv).

**Status**: **Req** mandatory, **Rec** strongly recommended for
robustness or EMC, **Opt** a genuine design choice. A quantity written as
a range (`0–2`, `2–3`) is one the source BOM leaves open — fit-if-needed
parts, or values still to be pinned down at schematic capture. Quantity
`0` marks a row that documents a **net rather than a part** (`V_USB` to
ground) or a deliberate no-fit (the crystal that is not populated).

---

## Totals

Counted at the low end of each quantity range, excluding rows that
document a net rather than a part.

| Status | Line items | Parts |
|---|---|---|
| Req — mandatory | 52 | 74 |
| Rec — recommended | 26 | 30 |
| Opt — optional | 18 | 13 |
| **Req + Rec** | **78** | **104** |

**GNSS antenna feed** is mutually exclusive: `L_bias` / `C_bias` / `R_bias` versus `R_bias0` — active antenna (bias-T) or passive antenna (0 ohm link) - populate one. Both appear below; the totals count both, so subtract whichever you do not fit.

The three modules that dominate cost — `U1` PIC18F57Q84, `U4` NEO-M9N,
and the BG95-M3 Mini PCIe card itself — are counted as ordinary line
items here. Note the BG95 card is **not** a line in any BOM: it is the
module that plugs into `J2`, bought as an assembly.

---

## Power  -  vehicle input, protection, two bucks

### 1. Front-end protection (vehicle input → `VSYS`)

| Ref | Qty | Status | Value / description | Suggested MPN | Notes |
|-----|-----|---|---|---|---|
| J1 | 1 | Req | 2-pin power input connector, automotive-rated | Molex/JST (verify current + keying) | Car harness entry |
| F1 | 1 | Req | Fuse, 3–4 A slow-blow, + holder | Littelfuse 0451 series (size to draw) | ~2.5 A worst-case in at 7 V; 3–4 A gives margin |
| Q1 | 1 | Req | P-ch MOSFET, −60 V, ~110 mΩ, AEC-Q101 | [Diodes DMP6110SFDF-13](https://www.diodes.com/datasheet/download/DMP6110SFDF.pdf) | Reverse-polarity pass FET; −60 V clears the SM8S26A ~42 V clamp |
| R1 | 1 | Rec | Gate resistor ≈ 100 kΩ, 0603 | generic 1% | Q1 gate pull to source |
| Dz1 | 1 | Rec | Gate-protect Zener ≈ 15 V, SOD-123 | Nexperia BZT52C15 | Clamps Q1 V_GS (abs max ±20 V) on transients |
| D1 | 1 | Req | Uni TVS, 26 V standoff, 42.1 V clamp, 7 kW, AEC-Q101 | [Littelfuse SM8S26A](https://www.littelfuse.com/products/tvs-diodes/surface-mount/sm8s.aspx) | Load-dump clamp; standoff > 18 V max, clamp < 60 V buck abs-max |
| FB0 | 1 | Rec | EMI ferrite / pi-filter element (or ≈ 4.7 µH) | Würth WE-MPSB or 4.7 µH power inductor | Keeps switching noise off the harness |
| C0 | 1 | Rec | Pi-filter input cap ≈ 1 µF, 63 V, X7R, 1210 | generic | Before FB0 (harness side) |
| C2, C3 | 2 | Req | ≈ 2.2 µF, 63 V, X7R, 1210 (at `VSYS`) | generic | After FB0; shared input decoupling for both bucks |
| C1 | 1 | Req | Input bulk ≈ 100 µF, 63 V, aluminum electrolytic (low-ESR) | Panasonic FR/FC series | Transient reservoir; 63 V for headroom over 42 V clamp |

### 2. Buck A — `VSYS` → 3.3 V @ ≥ 4 A (BG95 Mini PCIe rail, 2G-capable)

| Ref | Qty | Status | Value / description | Suggested MPN | Notes |
|-----|-----|---|---|---|---|
| U2 | 1 | Req | Wide-Vin buck, 4.5–60 V in, **5 A**, survives 65 V load dump, AEC-Q100 | [TI TPS54560-Q1](https://www.ti.com/lit/ds/symlink/tps54560-q1.pdf) | V_OUT = 3.3 V; 5 A gives headroom over ~4 A 2G burst; non-sync (needs D2) |
| L1 | 1 | Req | Power inductor ≈ 10 µH, I_sat ≥ 7.6 A, I_rms ≥ 7 A | [Coilcraft XAL6060-103MEC](https://www.coilcraft.com/en-us/products/power/shielded-inductors/molded-inductor/xal/xal60xx/) | Margin over 5.7 A peak; verify L vs U2 procedure at chosen fsw |
| D2 | 1 | Req | Schottky catch diode, 60 V, ≥ 5 A | [Diodes B560C-13-F](https://www.diodes.com/datasheet/download/B560C.pdf) | Required for non-sync TPS54560; **verify thermals at sustained 5 A** (bump to a 60 V/8 A part if running max continuously) |
| C_inA | 3 | Req | 2× 10 µF 63 V X7R (1210) + 0.1 µF | generic | At U2 V_IN, tight loop |
| C_outA | 3 | Req | 3× 22 µF 16 V X7R (1206) | generic | At U2 V_OUT; size for 5 A ripple + burst |
| R_fbA1 | 1 | Req | ≈ 31.6 kΩ 1% 0603 (top) | generic | Sets 3.3 V with V_REF 0.8 V (ratio 3.125) |
| R_fbA2 | 1 | Req | 10 kΩ 1% 0603 (bottom) | generic | — |
| R_rtA | 1 | Req | RT/CLK resistor (set ~500 kHz) | per datasheet | ~100 kΩ region; use datasheet fsw equation |
| C_ssA | 1 | **Req** | Soft-start cap (SS/TR), sized for **≥ 5 ms** | per datasheet | Controlled ramp; must cover inrush into the 660 µF socket reservoir (~0.44 A extra at 5 ms). **Recompute** — see `power-rail-notes.md` |
| R_compA, C_compA(, C_comp2A) | 2–3 | Req | Compensation network | per datasheet | Current-mode external comp — loop is unstable without it. **Must be recomputed for C_out = 660 µF / ESR ≈ 6.7 mΩ**: the output pole moved from ≈651 Hz to ≈197 Hz. See `power-rail-notes.md` |
| C_bootA | 1 | Req | Bootstrap ≈ 0.1 µF, 0603 | per datasheet | BOOT-to-SW; drives internal high-side FET. **Verify against TPS54560-Q1 datasheet** (TI's standard BOOT value is 0.1 µF; the earlier 10 nF was under-sized) |
| R_enA1/2 | 1–2 | Opt | EN pull-down (divider optional) | 1% 0603 | EN driven by PIC GPIO; pull-down = default OFF to sequence card after MCU. Divider only if hardware UVLO wanted |

### 3. Buck B — `VSYS` → 3.3 V @ ~0.6 A (PIC + NEO-M9N rail)

| Ref | Qty | Status | Value / description | Suggested MPN | Notes |
|-----|-----|---|---|---|---|
| U3 | 1 | Req | Small wide-Vin buck, 4–60 V in, 0.6 A, 0.7 MHz | [TI LMR16006XDDCR](https://www.ti.com/lit/ds/symlink/lmr16006.pdf) | V_OUT = 3.3 V (V_REF 0.765 V); **X = 0.7 MHz** chosen over Y (2.1 MHz): at 18 V in / 3.3 V out the Y needs an 87 ns on-time vs the 80 ns TON_MIN (§7.6) — pulse-skips at high line. X needs ~196 ns. Integrates comp + soft-start |
| L2 | 1 | Req | Power inductor **22 µH**, I_sat ≥ 1.7 A (≥ max current limit) | Coilcraft XAL5030-223 or similar (verify I_sat) | Eq. 1 at 18 V in, K_IND 0.3, 0.7 MHz → 21.4 µH → 22 µH (datasheet's own starting point, §9.2.2.2). Ripple ≈ 0.18 A, peak ≈ 0.69 A; I_sat ≥ 1.7 A current-limit max so a short can't saturate it |
| D3 | 1 | Req | Schottky catch diode, 60 V, 1 A (SMA) | [onsemi SS16](https://www.onsemi.com/download/data-sheet/pdf/ss16-d.pdf) (auto: SBRA8160, AEC-Q101) | **Required — LMR16006 is non-sync** (datasheet §9.2.2.4: V_BR ≥ 25% over max V_IN → 60 V) |
| C_inB | 2 | Req | 4.7 µF 63 V X7R (1206) + 0.1 µF | generic | At U3 V_IN; input ripple ≈ 46 mV at 0.7 MHz (Eq. 10), OK |
| C_outB | **2** | Req | **2 × 22 µF** 16 V X7R (1206) | generic | At U3 V_OUT. At 0.7 MHz the transient criterion (Eq. 5, 0→0.6 A, 3%) needs ≥ 17.1 µF and overshoot (Eq. 6, 22 µH) ≥ 11.9 µF — a single derated 22 µF is marginal, so two in parallel |
| R_fbB1 | 1 | Req | ≈ 33.2 kΩ 1% 0603 (top) | generic | Sets 3.3 V with V_REF 0.765 V (ratio 3.31) |
| R_fbB2 | 1 | Req | 10 kΩ 1% 0603 (bottom) | generic | — |
| C_bootB | 1 | Req | Bootstrap **100 nF**, ≥ 10 V X7R, 0603 | generic | CB-to-SW; datasheet §9.2.2.6 requires **0.1 µF or larger** (10 nF is too small) |
| R_enB | 1 | Opt | EN series resistor ≈ 100 kΩ (or divider) | generic 1% | Only if tying EN→VSYS. Can instead float EN (internal pull-up = always on). Divider sets custom UVLO |

## MCU  -  PIC18F57Q84, reset, ICSP, USB console

### 1. Microcontroller

| Ref | Qty | Status | Value / description | Suggested MPN | Notes |
|-----|-----|---|---|---|---|
| U1 | 1 | Req | PIC18F57Q84, 48-pin TQFP, 7×7 mm, 0.5 mm pitch | [Microchip PIC18F57Q84-I/PT](https://www.microchip.com/en-us/product/PIC18F57Q84) | `-I/PT` = industrial temp, TQFP. **No VCAP pin** on this device (§4.1) — do not fit a core-regulator cap |

### 2. Decoupling — DS40002213F §4.2.1, Table 3-2 note 5

| Ref | Qty | Status | Value / description | Suggested MPN | Notes |
|-----|-----|---|---|---|---|
| C_pic1 | 1 | Req | 0.1 µF, 16–25 V, **X7R**, low-ESR ceramic, 0402 | generic (select for SRF ≥ 200 MHz) | VDD pin **7** → VSS pin **6**, ≤ 6 mm, same side as U1 |
| C_pic2 | 1 | Req | 0.1 µF, 16–25 V, **X7R**, low-ESR ceramic, 0402 | generic (select for SRF ≥ 200 MHz) | VDD pin **30** → VSS pin **31**. Opposite corner from C_pic1 — **one shared cap is not compliant** |
| C_picBulk | 1 | Rec | 4.7 µF, 16 V, X7R, 0805 | generic | Tank cap, §4.2.2 (4.7–47 µF range). Kept because the NEO-M9N shares this rail and buck A switches hard nearby |
| C_picHF1, C_picHF2 | 0–2 | Opt | 1 nF (0.001 µF), 0402 | generic | Decade pair in parallel with each 0.1 µF. **Fit only if tens-of-MHz noise is measured** — no-fit pads by default |

### 3. MCLR / reset network — DS40002213F §4.3, Figure 4-1

| Ref | Qty | Status | Value / description | Suggested MPN | Notes |
|-----|-----|---|---|---|---|
| R_mclr1 | 1 | Req | **10 kΩ** 1% 0603, pull-up to VDD | generic | Figure 4-1 R1. Note 1 caps it at **R1 ≤ 10 kΩ**. The Curiosity Nano's 47 kΩ (R200) violates this — **follow the datasheet, not the dev board** |
| R_mclr2 | 1 | Rec | **220 Ω** 0603, series into MCLR (100–470 Ω range) | generic | Figure 4-1 R2. Note 2: **R2 ≤ 470 Ω**, limits C_mclr discharge current into the pin on ESD/EOS |
| C_mclr | 1 | Rec | 0.1 µF, 25 V, X7R, 0603 | generic | Figure 4-1 C1. Immunity to spurious reset on rail sag |
| JP_mclr | 1 | Opt | 2-pin 0.1 in jumper, **or** a no-fit pad on C_mclr | generic header | Figure 4-2: lets C_mclr be lifted if the programmer objects to the RC. Costs nothing as a no-fit |

### 4. ICSP programming + debug header — DS40002213F §4.4, Figure 48-2

| Ref | Qty | Status | Value / description | Suggested MPN | Notes |
|-----|-----|---|---|---|---|
| J_icsp | 1 | Req | 6-pin 0.1 in header, **0.025 in square posts**, 0.1 in pitch | generic (Würth/Molex 0.1 in SIL) | PICkit pinout: 1 VPP/MCLR, 2 VDD, 3 VSS, 4 ICSPDAT, 5 ICSPCLK, 6 NC. Figure 48-2 note 1 requires the 0.025 in square post. **Pin 1 must be marked** — square pad + silkscreen triangle + `VPP` legend; the header is unkeyed and Figure 48-2 draws a "Pin 1 Indicator" as part of the definition. The PICkit 5's 8-pin body mates with this; its pins 7–8 are unused |
| R_icsp1, R_icsp2 | 0–2 | Rec | **47 Ω** 0603, series on PGD / PGC | generic | §4.4: "tens of ohms", **must not exceed 100 Ω**. Fit only if the connector is exposed to ESD |
| R_icspPD1, R_icspPD2 | 2 | Rec | 47 kΩ 0603, pull-down on PGD / PGC | generic | Matches the Curiosity Nano debugger side; expected by Microchip tooling |

### 5. Debug console — USB-C + USB-to-UART bridge

| Ref | Qty | Status | Value / description | Suggested MPN | Notes |
|-----|-----|---|---|---|---|
| U5 | 1 | Req | USB 2.0 full-speed to UART bridge, QFN24 4×4 mm | **Silicon Labs CP2102N-A02-GQFN24** (Rev 1.5) | Integrated transceiver, pull-ups, and 48 MHz oscillator — *"no external resistors required"*, *"no external crystal required"* (p. 1). Enumerates as a COM port exactly like the Nano's CDC. `VIO` = `VDD` = `VREGIN` = `3V3_SYS`, per Figure 2.3 |
| J_dbg | 1 | Req | **USB-C receptacle, 16-pin USB-2.0-only**, SMT with through-hole retention tabs | generic (verify footprint) | 16-pin part avoids the unused SuperSpeed pins. Retention tabs are not optional in a vehicle |
| R_cc1, R_cc2 | 2 | Req | **5.1 kΩ** 1% 0402, one on **CC1**, one on **CC2** | generic | Advertises the board as a USB device (sink). **Two separate resistors** — a single shared resistor breaks cable-orientation detection and some hosts will not attach at all |
| D_dbg | 1 | Req | **Low-capacitance** ESD array, D+/D−/VBUS, SOT-23-6 | **ST USBLC6-2SC6** | KiCad: `Power_Protection:USBLC6-2SC6`, footprint `Package_TO_SOT_SMD:SOT-23-6`. **Pins:** 1+6 I/O1 → `USB_DP` (J_dbg D+ / U5 pin 3); 3+4 I/O2 → `USB_DM` (J_dbg D− / U5 pin 4); 5 VBUS → raw J_dbg VBUS (before divider); 2 GND. Place at the connector |
| R_rst | 1 | **Req** | **1 kΩ** 0402, pull-up from `RSTb` (pin 9) to `VIO` | generic | §2.1 p. 5: *"In all cases, a 1 kΩ pull-up on the RSTb pin is recommended. This pull-up should be tied to VIO on devices that have it."* The QFN24 has VIO, so it goes there |
| R_dbg1, R_dbg2 | 2 | Rec | 220 Ω 0603, series in `DBG_TX` / `DBG_RX` | generic | Edge-rate and ESD control, and a current limit if the two supplies ever skew. Matches `R_u3a`/`R_u3b` on the cellular UART. Harmless at DC: the PIC's input leakage is ±125 nA max (DS40002213F D340) |
| R_vbus1, R_vbus2 | 2 | Req | **22.1 kΩ** (high side, VBUS → sense) and **47.5 kΩ** (sense → GND), 1% 0402 | generic | The exact divider drawn in Figures 2.4 / 2.5 / 2.6. **Not optional**: §2.3 p. 9 states *"A resistor divider (or functionally-equivalent circuit) on VBUS is required."* See the arithmetic below |
| C_dbg1a/b, C_dbg2a/b, C_dbg3a/b | 6 | Req | **4.7 µF (`a`) and 0.1 µF (`b`) per power pin** — pairs at `VREGIN` (7), `VDD` (6), `VIO` (5) | generic, X7R | Figures 2.1–2.3: *"4.7 µF and 0.1 µF bypass capacitors required for each power pin placed as close to the pins as possible."* Three power pins means **six capacitors**, not two |
| C_dbg4 | 1 | Rec | 1 µF 16 V X7R 0603 on VBUS | generic | Local VBUS bypass at the connector |
| R_shield, C_shield | 1+1 | Rec | 1 MΩ 0402 ∥ 4.7 nF 2 kV 0603 | generic | Connector shell to GND. The RC lets ESD through to ground while keeping a DC ground loop from forming between the car chassis and a laptop |

### 6. Indication

| Ref | Qty | Status | Value / description | Suggested MPN | Notes |
|-----|-----|---|---|---|---|
| D_led0 | 1 | Opt | LED, low-current, 0603 | generic | Heartbeat on **RF3 (pin 39)**, driven **active low** by `LATFbits.LATF3` in [main.c](../main.c) |
| R_led0 | 1 | Req if D_led0 fitted | 1 kΩ 0603 | generic | ≈2 mA at 3.3 V. Also see `R_wwan` in [cellular-bom.md](cellular-bom.md) — same idea, different reason |

### 7. Clock — not fitted

| Ref | Qty | Status | Value / description | Suggested MPN | Notes |
|-----|-----|---|---|---|---|
| Y_hs | 0 | Opt | 10 MHz crystal, OSC1 (32) / OSC2 (33) | — | Only with HS/XT in CONFIG1. Costs RA6 + RA7 and buys nothing here |
| C_osc1, C_osc2 | 0 | Opt | 18 pF / 22 pF, 0402 | — | Curiosity Nano values for its 12 pF-CL crystal |
| R_s | 0 | Opt | Series drive resistor | — | §12: may be needed for low-drive-level quartz |
| Y_sosc | 0 | Opt | 32.768 kHz, SOSCI (35) / SOSCO (34) | — | Secondary oscillator unused; not populated on the Nano either |

### 8. Unused I/O

| Ref | Qty | Status | Value / description | Suggested MPN | Notes |
|-----|-----|---|---|---|---|
| R_unused | 0–n | Opt | 1 kΩ–10 kΩ 0603 to VSS | generic | §4.6 allows either firmware (drive as output low, **free — prefer this**) or a resistor to VSS. Reserve resistors for pins left floating at a connector |

## Cellular  -  BG95-M3 Mini PCIe, SIM, USB

### 1. Mini PCIe socket and rail decoupling

| Ref | Qty | Status | Value / description | Suggested MPN | Notes |
|-----|-----|---|---|---|---|
| J2 | 1 | Req | Mini PCIe socket, **52-pin, full-size**, with latch | Molex 679105700 (Quectel's own reference, Figure 19) | Card supply on `VCC_3V3` pins **2, 39, 41, 52** — **not pin 24, which is RESERVED** on this card despite being 3.3Vaux in the Mini PCIe standard. GND on 4, 9, 15, 18, 21, 26, 27, 29, 34, 35, 37, 40, 43, 50 (Table 6) |
| C10, C11 | **3** | Req | Bulk reservoir **3 × 220 µF = 660 µF**, ≥ 6.3 V, low-ESR polymer, **effective ESR ≤ 10 mΩ** | Panasonic SP-Cap / Kemet T520 | Sources the TX burst locally at the socket. Sizing math in [power-rail-notes.md](power-rail-notes.md); paralleled to divide ESR and ESL |
| C12, C13 | 2 | Req | 10 µF 16 V X7R (0805) + 100 nF 0402 | generic | HF decoupling at the socket power pins |
| C14, C15 | 2 | Rec | 33 pF + 10 pF, 0402 | generic | Completes the Figure 3 cap ladder |
| D_cell | 1 | Rec | TVS on `3V3_CELL`, low clamp above 3.6 V | select clamp < card abs max (verify) | Socket-local clamp — the front-end TVS `D1` is far away at the harness entry |

### 2. (U)SIM interface — §3.3, Figure 4

| Ref | Qty | Status | Value / description | Suggested MPN | Notes |
|-----|-----|---|---|---|---|
| J3 | 1 | Req | Nano-SIM holder, **hinged locking cover**, 6 contacts + detect switch | **GCT SIM8060-6-1-14-00-A** | Normally-open switch closes `SW` to the grounded shell when the card is seated → `SIM_DET` low = inserted |
| C_sim1 | 1 | Req | **100 nF**, 0402, `USIM_VDD` → GND | Murata GRM155R71C104KA88D | §3.3: decoupling **must not exceed 1 µF** and must sit close to the holder |
| C_sim2..4 | 3 | Req | **33 pF**, 0402, one per RST / CLK / DATA to GND | Murata GRM1555C1H330JA01D | Filters EGSM900 interference |
| D_sim | 1 | Req | TVS array, **parasitic capacitance ≤ 15 pF** | **TI TPD4E02B04DQAR** (~0.25 pF/ch, USON-10) | At the holder, on VDD / IO / CLK / RST. The 15 pF ceiling is the selection criterion |
| R_det1, R_det2 | 2 | Req | **51 kΩ**, 0402 — `SIM_DET` divider from `3V3_CELL` | Yageo RC0402FR-0751KL | See detect note below |
| R_simPU | 1 | Opt | **15 kΩ** 0402 to `USIM_VDD` | Yageo RC0402FR-0715KL | Pull-up on `USIM_DATA`; improves anti-jamming on long or noisy traces. Value per Figure 4/5; fit **DNP** by default |

### 3. UART to the PIC — §3.5

| Ref | Qty | Status | Value / description | Suggested MPN | Notes |
|-----|-----|---|---|---|---|
| R_u3a, R_u3b | 2 | Rec | 220 Ω 0603 | generic | Series on `CELL_RX` / `CELL_TX`. Both ends now share a board, so the back-power case from [bench-wiring.md](bench-wiring.md) is gone; these remain useful for edge-rate and ESD control |

### 4. Control and indication

| Ref | Qty | Status | Value / description | Suggested MPN | Notes |
|-----|-----|---|---|---|---|
| R_perst | 1 | Rec | 10 kΩ 0603 to `3V3_SYS` | generic | Belt-and-braces pull-up on `PERST#` (pin 22); holds reset released while the PIC is itself in reset. The card already pulls up |
| TP_perst | 1 | Rec | Test point | generic | A 2–3.8 s reset pulse is worth being able to scope |
| D_wwan | 1 | Opt | LED, low-current, 0603 | generic | `LED_WWAN#` (pin 42), open collector, active low |
| R_wwan | 1 | **Req if D_wwan fitted** | **1 kΩ** 0603 from `3V3_SYS` | generic | §3.7.4: *"a resistor must be placed in series with the LED."* ≈2 mA at 3.3 V. **Do not omit** — the pin sinks up to 40 mA and will cook the LED |

### 5. USB — Opt, §3.4

| Ref | Qty | Status | Value / description | Suggested MPN | Notes |
|-----|-----|---|---|---|---|
| L_usb | 1 | Rec | Common-mode choke, USB 2.0 rated | Würth WE-CNSW or equivalent | §3.4 recommends one in series for EMI. **Place close to the socket** |
| D_usb | 1 | Rec | Low-capacitance ESD array, 2-line | select for low C on a 90 Ω pair | Per Figure 6 |
| R_usb1, R_usb2 | 2 | Opt | 0 Ω 0402, **not mounted by default** | generic | Series to test points, per Figure 6 |
| J_usb | 1 | Opt | USB connector or 4-pin header | generic | Firmware-update access |

### 6. Mechanical

| Ref | Qty | Status | Value / description | Suggested MPN | Notes |
|-----|-----|---|---|---|---|
| MP1, MP2 | 2 | Req | Card standoffs / mounting posts for a full-size card | per socket vendor | Card is 51.0 × 30.0 mm (§7.2) |
| MP3 | 1 | Rec | Retaining screw or bracket, in addition to the latch | generic | In a vehicle the latch is structural. A card that walks out of its socket over a race weekend takes the telemetry link with it |
| — | 0 | Req | U.FL-LP mating plug, clearance, and cable strain relief | §5.4 recommends the U.FL-LP family | **The antenna connector is on the card** — no 50 Ω trace on our PCB. What the board owes is bend-radius clearance (Figure 16), a cable path to the bulkhead, and an anchor against continuous vibration |

## GNSS  -  NEO-M9N, supply, RF front end

### 1. Receiver module

| Ref | Qty | Status | Value / description | Suggested MPN | Notes |
|-----|-----|---|---|---|---|
| U4 | 1 | Req | NEO-M9N-00B, **24-pin LCC**, 12.2 × 16.0 × 2.4 mm, 1.1 mm pitch | [u-blox NEO-M9N-00B](https://www.u-blox.com/en/product/neo-m9n-module) | **Perimeter castellations, no hidden thermal pad** — joints are visible and probeable. Footprint and paste mask from IM Figures 37/38, with keep-out for the ≤ 0.5 mm de-panel tabs on one long edge |

### 2. Main supply decoupling (VCC, pin 23)

| Ref | Qty | Status | Value / description | Suggested MPN | Notes |
|-----|-----|---|---|---|---|
| C_neo1 | 1 | Req | **1 µF**, 16 V, X7R, 0603 | generic | IM §4.9.1 asks it as a checklist item verbatim: *"Is there a 1 uF cap right next to the module VCC pin?"* Place as close to the pad as physically possible |
| C_neo2 | 1 | Rec | 100 nF, 16 V, X7R, 0402 | generic | HF companion at VCC |
| C_neoBulk | 1 | Rec | 10 µF, 16 V, X7R, 0805 | generic | Local reservoir for the 100 mA acquisition peak |
| FB2 | 1 | Rec | Ferrite ≈ 600 Ω @ 100 MHz, **DCR < 0.2 Ω** | Murata BLM18 series (**select on DCR**) | Isolates the GNSS branch from the PIC rail. Also listed in `power-supply-bom.md` §5. **Hard limit:** IM §4.2.1 forbids > 0.2 Ω series resistance in the VCC line |

### 3. Backup supply (V_BCKP, pin 22) and V_USB (pin 7)

| Ref | Qty | Status | Value / description | Suggested MPN | Notes |
|-----|-----|---|---|---|---|
| C_bkp | 1 | Rec | 10 µF-class hold cap, 16 V (or a supercap) | generic | Keeps RTC + battery-backed RAM alive for hot/warm starts. Backup draw is only **45 µA** typ at 3 V (Datasheet Table 11). Cold start ≈ 24–29 s to fix vs. a couple of seconds hot |
| — | 0 | Req | **If C_bkp is omitted: tie V_BCKP directly to VCC** | — (a net, not a part) | IM §4.2.2. **Never leave pin 22 floating**, and put **no series resistance** on the line — switchover draws a current peak that a resistive path turns into a damaging drop |
| — | 0 | Req | **V_USB (pin 7) tied to GND** | — (a net, not a part) | IM §4.2.3 — required when USB is unused. This is *not* covered by the "unused inputs may be left open" rule and is the single easiest pin on this part to get wrong |

### 4. RF front end

| Ref | Qty | Status | Value / description | Suggested MPN | Notes |
|-----|-----|---|---|---|---|
| J_gnss | 1 | Req | U.FL or SMA, **50 Ω** | generic (Hirose U.FL-R-SMT / Amphenol SMA) | Roof- or shell-mount antenna feed |
| D_rf | 1 | **Req** | **Low-capacitance** ESD diode, GNSS-band rated | select for C ≲ 0.5 pF, e.g. an ESD8xxx-class part (verify capacitance) | IM §4.5.2: *"An ESD protection diode should also be connected to the input."* At the connector. Capacitance is the selection criterion — a general-purpose TVS will detune the input |
| L_bias | 1 | Opt | **27 nH**, Z > 500 Ω at GNSS frequency, rated **> 300 mA** | Murata LQW/LQG RF inductor (verify Z and Irms) | Bias-T choke; isolates RF from the DC path |
| C_bias | 1 | Opt | **100 nF**, X7R, 10%, 16 V, 0402 | generic | Removes HF noise from the DC feed |
| R_bias | 1 | Opt | **22 Ω**, 0.25 W, 0805 | generic | Short-circuit limiter. **Not the 10 Ω in Table 26** — the text below it requires ≥ **19 Ω** at a 3.3 V supply to hold short-circuit current under 150 mA. 22 Ω is the nearest standard value |
| R_bias0 | 1 | Opt | 0 Ω link, 0402 | generic | Fitted **instead of** `L_bias` / `C_bias` / `R_bias`. Leave `VCC_RF` (pin 9) and `LNA_EN` (pin 14) unconnected |

### 5. Digital interface and test points

| Ref | Qty | Status | Value / description | Suggested MPN | Notes |
|-----|-----|---|---|---|---|
| TP_safeboot | 1 | Rec | Test point or no-fit pad | generic | `SAFEBOOT_N` (pin 1). Left open in normal operation; brought out for future firmware update |
| TP_pps | 1 | Rec | Test point | generic | `TIMEPULSE` (pin 3) — 1 PPS at **30 ns RMS**, 4 mA drive. Route to a PIC input even though firmware does not use it yet; it is the only way to discipline timestamps better than UART arrival time |

---

## Parts carried in two source BOMs

Each of these is **one physical part**, listed twice at the source: once
in `power-supply-bom.md` as rail distribution, and once in the BOM for
the subsystem it feeds. The row below was dropped in favour of the
subsystem row, so it is above exactly once. Order once.

| Dropped from | Ref | Kept in | As |
|---|-----|---|----|
| power-supply-bom.md | `J2` | cellular-bom.md | `J2` |
| power-supply-bom.md | `C10, C11` | cellular-bom.md | `C10, C11` |
| power-supply-bom.md | `C12, C13` | cellular-bom.md | `C12, C13` |
| power-supply-bom.md | `C14, C15` | cellular-bom.md | `C14, C15` |
| power-supply-bom.md | `J3` | cellular-bom.md | `J3` |
| power-supply-bom.md | `FB2` | gnss-bom.md | `FB2` |
| power-supply-bom.md | `C_neo1, C_neo2` | gnss-bom.md | `C_neo1` |
| power-supply-bom.md | `C_neoBulk` | gnss-bom.md | `C_neoBulk` |
| power-supply-bom.md | `C_bkp` | gnss-bom.md | `C_bkp` |
| power-supply-bom.md | `C_vusb` | gnss-bom.md | a net, no designator |
| power-supply-bom.md | `C_pic` | mcu-bom.md | `C_pic1` |
| power-supply-bom.md | `C_picBulk` | mcu-bom.md | `C_picBulk` |

---
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

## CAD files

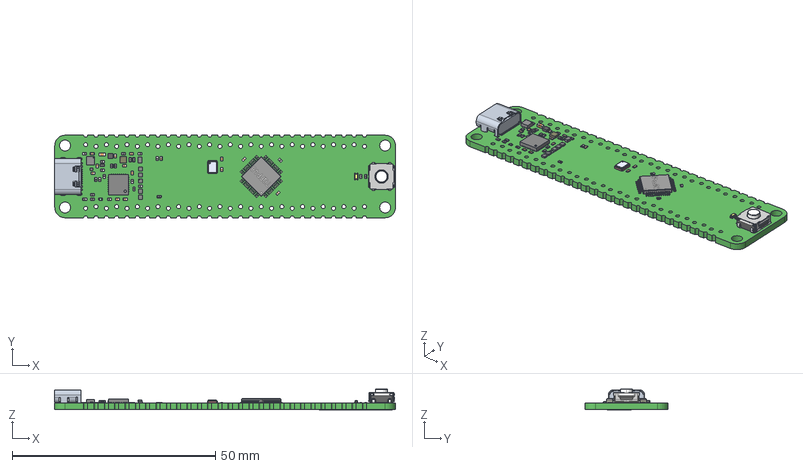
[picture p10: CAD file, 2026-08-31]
pic_resources/PIC18F57Q84-Curiosity-Nano-Design-Documentation/PCBA_Rev6/PIC18F57Q84_Curiosity_Nano.step
83.9 x 20.3 x 5.16 mm
MetalFrame
Pin1Marker
Pin3
Pin1
Lid
Pin4
Pin2
Ceramic
TQFP-48
CAP_C_0402 x 14
RES_0402 x 24
MIC2008YML-TR
bigPin
smallPine x 2
User Library-Thin MLF
mic5528
Extruded x 2
ball x 6
CAP_C_0603 x 3
User Library-LED_1006_R_Rot
User Library-LED_1006_R_Cut006
User Library-LED_1006_R_Cut005
User Library-LED_1006_R_Cut005_(Mirror_#1)
User Library-LED_1006_R_Pad001
LED 0603 Yellow
Thermal_Shape
SKRAAK

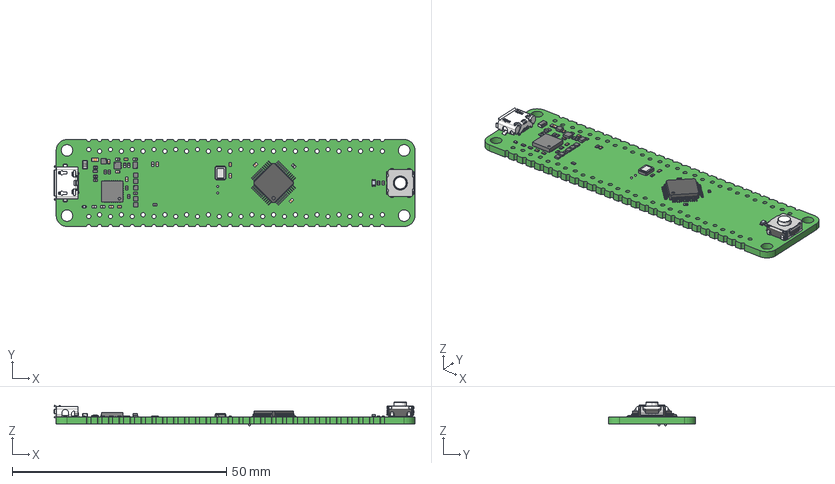
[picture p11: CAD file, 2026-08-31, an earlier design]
pic_resources/PIC18F57Q84-Curiosity-Nano-Design-Documentation/PCBA_Rev4/ExportSTEP/PIC18F57Q84_Curiosity_Nano(Default Assembly).step
84.3 x 20.3 x 5.54 mm
User_Library-TQFP-48_pins_TQFP_pin_TQFP_022x07_1 x 48
User_Library-TQFP-48_body_10x1_TQFP_7x7_1
0402_SMD_Resistor x 19
0805_SMD_Resistor
LF
Open_CASCADE_STEP_translator_6.8_9.1
Open_CASCADE_STEP_translator_6.8_9.2.1
Thermal_Shape x 2
Open_CASCADE_STEP_translator_6.8_9.4.1 x 6
ZX62D-AB-5P8
Open_CASCADE_STEP_translator_6.8_18.1 x 5
Open_CASCADE_STEP_translator_6.8_18.2.1 x 5
Open_CASCADE_STEP_translator_6.8_18.3.1 x 30
0402_SMD_Capacitor x 11
SML-P10
User_Library-0603_SMD_Capacitor
Open_CASCADE_STEP_translator_6.8_3.1
Open_CASCADE_STEP_translator_6.8_3.2.1
Open_CASCADE_STEP_translator_6.8_3.4.1 x 32
Open_CASCADE_STEP_translator_6.8_11.1
Open_CASCADE_STEP_translator_6.8_11.2.1
Open_CASCADE_STEP_translator_6.8_11.3.1 x 6
Open_CASCADE_STEP_translator_6.8_1.1
Open_CASCADE_STEP_translator_6.8_1.2.1
ball x 6
Crystal
Extruded
SKRAAK
SML-D10

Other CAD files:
pic_resources/PIC18F57Q84-Curiosity-Nano-Design-Documentation/PCBA_Rev4/PADSNetlist/PIC18F57Q84_Curiosity_Nano.PRT

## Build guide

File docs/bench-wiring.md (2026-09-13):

# Curiosity Nano + Sixfab Cellular IoT HAT + NEO-M9N — Bench Wiring

Wiring to test the PIC18F57Q84 Curiosity Nano with the Sixfab Cellular IoT HAT
(BG95-M3) and the u-blox NEO-M9N GNSS. This records the legacy bench harness;
it no longer matches the custom-board cellular pin map in `uart3.c` and
`bg95.c`.

> **This is the bench rig, not the product.** Everything below relies on the
> Curiosity Nano's on-board ATSAMD21 debugger, which does two jobs over one
> micro-USB cable: it programs the PIC, and it presents the 115200 `printf`
> console as a virtual COM port. **The custom board has no such chip.** It splits
> the two jobs across two connectors — `J_icsp`, a 6-pin ICSP header driven by a
> **PICkit 5** for programming *and* in-circuit debug, and `J_dbg`, a **USB-C**
> port behind a CP2102N bridge that provides the console alone. See
> [mcu-support-circuit.md](mcu-support-circuit.md) §5 and §9. Two habits from
> this page do not carry over: the PICkit must **not** be asked to power the
> target, and USB no longer powers anything at all.
>
> **Do not run the current custom-board firmware on this harness unchanged.**
> The harness uses RF4/RF5 and RA2 with the Sixfab HAT's active-HIGH
> `HAT_PWR_OFF`; the product firmware uses RA1/RA0 and active-HIGH
> `CELL_PWR_EN` on RC7.

## What you are testing

| Interface | Pins | Baud | Purpose |
|---|---|---|---|
| UART3 | RF4 / RF5 (BG95; moved off RA0/RA1 — RA0 pin dead) | 115200 | BG95 AT commands / UDP |
| UART2 | RD0 / RD1 (J100-7 / J100-8) | 38400 → 115200 | NEO-M9N NMEA ingest (boots at 38400, firmware negotiates to 115200 for 25 Hz) |
| UART1 | On-board USB debugger | 115200 | `printf` debug terminal (no extra wires) |

---

## Wiring diagram

### Block diagram

```mermaid
flowchart TB
  subgraph rails [Your DC Rails]
    R1["Rail1: 5V >= 3A"]
    R2["Rail2: PC USB 5V"]
    R3["Rail3: GND bus optional"]
  end

  subgraph pc [Host PC]
    COM["Virtual COM 115200"]
  end

  subgraph cn [PIC18F57Q84 Curiosity Nano]
    USB["DEBUG Micro-USB"]
    VTG["VTG 3.3V"]
    J43["J100-43 RA0 U3TX"]
    J44["J100-44 RA1 U3RX"]
    J45["J100-45 RA2"]
    J7["J100-7 RD0 U2TX"]
    J8["J100-8 RD1 U2RX"]
    JGND["J100-15 GND"]
  end

  subgraph hat [Sixfab Cellular IoT HAT]
    P2["Pin2 5V"]
    P4["Pin4 5V"]
    P6["Pin6 GND"]
    P8["Pin8 UART_TX"]
    P10["Pin10 UART_RX"]
    P37["Pin37 HAT_PWR_OFF"]
    BG95["BG95-M3 Mini PCIe"]
  end

  subgraph gps [NEO-M9N]
    GVCC["VCC"]
    GTX["TX"]
    GRX["RX"]
    GGND["GND"]
  end

  R1 --> P2
  R1 --> P4
  R2 --> USB
  USB --> COM
  USB --> VTG
  R3 --> P6
  R3 --> JGND
  R3 --> GGND

  J43 -->|"wire 1"| P8
  P8 --> BG95
  BG95 --> P10
  P10 -->|"wire 2"| J44
  J45 -->|"wire 3"| P37
  JGND -->|"wire 4 GND"| P6

  VTG -->|"3.3V"| GVCC
  GTX -->|"wire 5"| J8
  J7 -.->|"wire 6 optional"| GRX
  JGND -->|"GND"| GGND
```

### ASCII bench layout

```
  Rail 1 (5V, >=3A)                         Rail 2 (PC USB 5V)
        |                                           |
        +-------+                                   |
        |       |                                   |
     [Pin2]  [Pin4]   <-- both are 5V         [DEBUG USB]-----> PC (115200 COM)
      5V      5V                                    |
        |       |                                   |  on-board regulator
   +----+-------+-----------------------------------+----+
   |         Sixfab Cellular IoT HAT                 |    |
   |    +----------------------------------+         |    |
   |    |         BG95-M3 (Mini PCIe)      |         |    |
   |    |   UART via SJ7+SJ8 (soldered!)   |         |    |
   |    |   LTE antenna required           |         |    |
   |    +----------------------------------+         |    |
   |                                                 |    |
   |  [Pin6 GND]  [Pin8]  [Pin10]            [Pin37] |    |
   |     GND     UART_TX UART_RX         HAT_PWR_OFF |    |
   +------|----------|---------|----------------|----+
          |          |         |                |
   Rail1 GND   wire1 |   wire2 |          wire3 |
          |          |         |                |
          |    [J100-43] [J100-44]        [J100-45]
          |     RA0 TX    RA1 RX             RA2
          |          |         |                |
   +------|----------|---------|----------------|----+
   |      |   PIC18F57Q84 Curiosity Nano         |    |
   |      |                                      |    |
   |  [J100-15 GND]   [VTG 3.3V]                 |    |
   |      ^               |                      |    |
   |      |               |                      |    |
   |  [J100-8 RD1 RX] [J100-7 RD0 TX]            |    |
   |      ^               |                      |    |
   |      |         wire6 | (optional: config)   |    |
   |      |               v                      |    |
   |      |          [NEO-M9N RX]                |    |
   | wire5|                                      |    |
   |      v                                      |    |
   |  [NEO-M9N TX]   [NEO-M9N VCC] <--- VTG 3.3V |    |
   |  [NEO-M9N GND] <---+--- common GND ---------+    |
   |                                                 |    |
   |  (printf goes out USB CDC; no extra wire)       |    |
   +-------------------------------------------------+

Power note:
  HAT Pin 2 and 4 = 5 V.  HAT Pin 6 = GND (not 5 V).
  NEO-M9N VCC from Curiosity VTG (3.3 V), not from the HAT 5 V rail.
  Tie Rail 1 return, HAT pin 6, Curiosity GND, and NEO-M9N GND together.
```

### Pin map

```
Curiosity J100          Sixfab 40-pin header
-----------             --------------------
RF4      TX       ----> Pin 8   UART_TX  (to module RX)   [was RA0; RA0 dead]
RF5      RX       <---- Pin 10  UART_RX  (from module TX) [was RA1]
J100-45  RA2       ----> Pin 37  HAT_PWR_OFF (HIGH = off; cut SJ1 + 10k pull-up to VTG)
J100-15  GND       ----> Pin 6   GND
                         Pin 2,4  5V  <--- Rail 1

Curiosity J100          SparkFun NEO-M9N breakout
-----------             --------------------------
J100-8   RD1  RX  <---- TX     (GPS transmits NMEA; required)
J100-7   RD0  TX  ----> RX     (config to GPS; optional for basic RX)
VTG      3.3V     ----> 3V3    (or use breakout 5V pin — see power notes)
GND               ----> GND
```

---

## Hardware prep

### Sixfab HAT

Per [Sixfab Base HAT technical details](https://docs.sixfab.com/docs/raspberry-pi-3g-4g-lte-base-hat-technical-details):

1. **Solder jumpers SJ7 and SJ8** — UART is disconnected by default on the HAT.
2. **Cut solder jumper SJ1** — removes the HAT's internal pull-down on pin 37
   (HAT_PWR_OFF / GPIO26) so the external RA2 pull-up defines the default-off
   state for boot-order control (see the pull-up circuit under BG95 signal wires).
3. Seat the **BG95-M3** in the Mini PCIe slot.
4. Install an **LTE / main RF antenna** on the HAT (required for cellular).
5. Insert a valid **nano-SIM** (1.8 V class).
6. BG95 GNSS antenna is **not** required for farseer (position comes from the NEO-M9N).

### NEO-M9N (SparkFun breakout, e.g. GPS-15712)

[SparkFun NEO-M9N hookup guide](https://learn.sparkfun.com/tutorials/sparkfun-gps-neo-m9n-hookup-guide/hardware-overview):

1. Attach a **GNSS antenna** (U.FL / SMA / chip antenna depending on board variant).
2. Power options (pick **one**):
   - **`3V3`** ← Curiosity **VTG** (cleanest; matches PIC I/O), or
   - **`5V`** ← a 5 V source (on-board regulator steps down to 3.3 V; do not exceed 6 V), or
   - USB-C on the breakout (standalone power; still share GND with Curiosity for UART)
3. **UART I/O is 3.3 V** even if you feed the `5V` pin — do not put 5 V on TX/RX.
4. Leave the underside **`SPI` jumper open** (default) so UART stays enabled on the TX/RX pins.
5. No level shifting needed with Curiosity @ 3.3 V VTG.

---

## Power rails

| Rail | Use | Notes |
|---|-----|---|
| **Rail 1 — 5 V, ≥ 3 A** | Sixfab HAT pins **2** and **4** | HAT rated 5 V / 3.0 A; BG95 can peak ~2.7 A during TX |
| **Rail 2 — USB 5 V** | Curiosity **DEBUG Micro-USB** | Powers board at 3.3 V VTG; provides virtual COM; also feeds NEO-M9N via VTG |
| **Rail 3 — spare** | Common ground bus (optional) | Tie HAT, Curiosity, and NEO-M9N GND together |

**Rules**

- Do **not** power the Sixfab HAT from Curiosity VTG (3.3 V).
- SparkFun GPS: power via breakout **`3V3`←Curiosity VTG** or breakout **`5V`←5 V** (regulated on-board). Don’t feed VTG into the SparkFun `5V` pin.
- **Do** share GND between Curiosity, HAT, and SparkFun GPS.
- Keep Curiosity VTG at **3.3 V** (factory default) — UART levels follow VTG.
- For external 3.3 V on Curiosity (instead of USB): apply 3.3 V to **VTG (J100-51)** and short **VOFF (J100-55) → GND** first (DS50003011 §3.3.2).

### Power sequencing (avoid back-power) — IMPORTANT

Bring **all rails up together** (or the PIC/VTG first). The PIC's VTG rail must
**never be dead while the HAT or GPS is powered and driving signals into it.**

Why: every PIC I/O pin has an ESD clamp diode to VDD. If a powered peripheral
drives a pin (UART TX idling HIGH, HAT_PWR_OFF bias, etc.) while VTG = 0, current
is injected through that diode into the dead VDD rail, dragging it to an invalid
~2 V. The Curiosity's on-board debugger monitors VTG within ±100 mV of its
setting; an out-of-window rail trips its power-fault protection — the **PS LED
blinks rapidly (~5 Hz)** and the target regulator is held off, so the **PIC never
boots** (DS50003011 §3.3, Table 3-1). Symptom seen on this bench: powering the
HAT before the Curiosity → PS LED rapid-blink, PIC dead. Fix: shared/simultaneous
rails so there is no "peripheral on / PIC off" window.

Mitigations if rails can ever skew: series resistors on every cross-board line
(RA2↔pin37, RF4↔pin8, RF5↔pin10) to limit ESD-diode current, or power the PIC
target from the **same 5 V rail** as the HAT via a 5 V→3.3 V regulator into VTG
(with VOFF→GND) so VTG is alive whenever the HAT is.

### NEO-M9N sequencing

The NEO-M9N is powered from **VTG (the PIC's own rail)**, so it inherently comes
up with the PIC — no back-power path and no pin-37-style control needed. Only if
you power it from a **separate always-on 5 V** does its `TXD → RD1` line become a
back-power injector (same failure mode as above); avoid that by keeping it on VTG.
For explicit PIC control, drive **RESET_N** (active-low, internal 7–13 kΩ pull-up,
NEO-M9N-00B UBX-19014285) rather than cutting VCC.

---

## Signal wires

### BG95 (UART3)

| Wire | Curiosity J100 | Sixfab HAT | Notes |
|---|---|---|---|
| 1 | RF4 | Pin 8 (UART_TX) | PIC TX → module RX; **~220 Ω series** (moved off RA0; RA0 dead) |
| 2 | RF5 | Pin 10 (UART_RX) | PIC RX ← module TX; **~220 Ω series** (moved off RA1) |
| 3 | J100-45 (RA2) | Pin 37 (HAT_PWR_OFF) | **Cut HAT SJ1**; add **10k pull-up RA2->VTG**. HIGH = module off; PIC drives LOW when ready so the BG95 boots after the PIC |
| 4 | J100-15 (GND) | Pin 6 (GND) | Required |
| (opt) | J100-52 (GND) | Pin 9 or 14 | Extra ground for noise |

#### Series resistors on UART (recommended)

Put **~100–330 Ω** (typ. **220 Ω**) in series on each BG95 UART wire (RA0↔pin 8 and RA1↔pin 10):

```
  Curiosity RA0 (TX) ----[220 Ω]---- HAT pin 8
  Curiosity RA1 (RX) ----[220 Ω]---- HAT pin 10
```

Why: if one board is powered and the other is not, the resistor limits current through ESD diodes (back-power protection). Fine at 115200 for short bench leads. Optional but cheap insurance.

Also fine: power Curiosity and HAT from the same switch so both rails rise/fall together.

#### Power-off / boot-order pull-up (HAT_PWR_OFF, pin 37)

Pin 37 (HAT_PWR_OFF, GPIO26) is **active-HIGH**: HIGH cuts the HAT power regulator
(module off), LOW powers it on. To make the BG95 boot **after** the PIC, cut the
HAT's internal pull-down (**SJ1**) and add a **10 kΩ pull-up from RA2 to VTG (3.3 V)**.
The pull-up holds pin 37 HIGH (module off) while the PIC is in reset / RA2 is
high-Z; firmware then drives RA2 LOW after `BG95_PWR_HOLD_MS` to power it on.

```
        VTG (3.3 V)
          |
        [ 10 kΩ ]        (pull-up; do NOT use 5 V — pin 37 is 3.3 V logic)
          |
   RA2 ---+---------------- HAT pin 37 (HAT_PWR_OFF, SJ1 CUT)
 (J100-45)
   RA2 high-Z / HIGH -> pin 37 HIGH -> module OFF
   RA2 driven LOW    -> pin 37 LOW  -> module ON
```

Note: pin 37 is 3.3 V logic (Raspberry Pi GPIO levels), so pull up to VTG, not 5 V.

### NEO-M9N SparkFun breakout (UART2)

| Wire | Curiosity J100 | SparkFun label | Notes |
|---|---|---|---|
| 5 | J100-8 (RD1 RX) | **TX** | Required — GPS → PIC (NMEA) |
| 6 (opt) | J100-7 (RD0 TX) | **RX** | Only to send config to the GPS |
| — | VTG (3.3 V) | **3V3** | Preferred power from Curiosity |
| — *(alt)* | 5 V (USB VBUS / bench) | **5V** | OK — breakout regulates to 3.3 V; UART still 3.3 V |
| — | GND | **GND** | Same common ground |

Do **not** wire Curiosity VTG into the SparkFun **5V** pin (wrong direction / double-regulation mess). Use either `3V3←VTG` **or** `5V←5V supply`, not both.

Firmware only needs breakout **TX → PIC RD1** for NMEA ingest (`uart2.c` / `gps.c`).

---

## Bring-up

1. Power HAT (5 V rail) and Curiosity (USB) **together** with GND shared — do NOT power the HAT first while the PIC is unpowered (back-power fault; see "Power sequencing" above).
2. Build and flash via MPLAB (**Make and Program Device**).
3. Open the virtual COM port at **115200 8N1**.
4. Expect:
   - `Farseer boot: NEO-M9N + BG95 UDP (non-blocking)`
   - `[BG95] bring-up started; loop is non-blocking`
   - AT-driven status messages from `bg95.c`
   - GPS fix / NMEA-derived output from `gps.c` once the NEO-M9N has sky view

---

## Pre-power checklist

- [ ] All rails brought up together / PIC (VTG) not left dead while HAT or GPS is powered (avoids back-power fault; PS LED rapid-blink = fault)
- [ ] SJ7 + SJ8 soldered on Sixfab HAT
- [ ] SJ1 cut on Sixfab HAT (HAT_PWR_OFF pull-down removed for boot-order control)
- [ ] BG95 seated, **LTE antenna** attached, SIM installed
- [ ] 5 V ≥ 3 A on HAT pins 2/4; GND on HAT pin 6
- [ ] Curiosity powered via USB; VTG = **3.3 V**
- [ ] Shared GND: HAT + Curiosity + NEO-M9N
- [ ] BG95 UART: RF4→pin8, RF5→pin10; RA2→pin37 with 10k pull-up to VTG (boots after PIC)
- [ ] ~220 Ω series on each BG95 UART line (recommended)
- [ ] GPS: SparkFun TX→RD1 (J100-8), 3V3←VTG (or 5V←5V), GND common
- [ ] GPS antenna on SparkFun breakout; SPI jumper left open
- [ ] HAT level-shifts BG95 UART — do not bypass with raw 1.8 V module pins
- [ ] Do not drive HAT UART or NEO-M9N at 5 V logic

---

## References

- Curiosity pin labels: `pic_resources/.../02-01204-R6_TPR.csv`
- Curiosity power: `pic_resources/PIC18F57Q84-Curiosity-Nano-Hardware-User-Guide-DS50003011.pdf` §3.3
- NEO-M9N: `datasheets/NEO-M9N-00B_DataSheet_UBX-19014285.pdf` §4.2 / Table 11–12
- Firmware: `uart2.h`, `uart3.h`, `bg95.c`, `gps.c`, `main.c`
- Sixfab HAT: [technical details](https://docs.sixfab.com/docs/raspberry-pi-3g-4g-lte-base-hat-technical-details)

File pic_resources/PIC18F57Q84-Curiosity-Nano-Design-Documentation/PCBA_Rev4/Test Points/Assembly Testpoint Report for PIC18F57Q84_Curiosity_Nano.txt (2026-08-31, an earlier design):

Net         Name        X Coord     Y Coord     Side        Hole Size   Type        
V\O\F\F\    J200-55        10.16mm   17.5768mm  Bottom             1mm  Through hole
DBG3        J200-54         12.7mm   17.9832mm  Bottom             1mm  Through hole
RF2         J200-27        73.66mm    2.3368mm  Bottom             1mm  Through hole
GND         J200-24        66.04mm    2.7432mm  Bottom             1mm  Through hole
RF0_UART1/3/5_TXJ200-25        68.58mm    2.3368mm  Bottom             1mm  Through hole
RF1_UART1/3/5_RXJ200-26        71.12mm    2.7432mm  Bottom             1mm  Through hole
RD3         J200-23         63.5mm    2.3368mm  Bottom             1mm  Through hole
RD2         J200-22        60.96mm    2.7432mm  Bottom             1mm  Through hole
RC3         J200-21        58.42mm    2.3368mm  Bottom             1mm  Through hole
RC2         J200-20        55.88mm    2.7432mm  Bottom             1mm  Through hole
RC7         J200-19        53.34mm    2.3368mm  Bottom             1mm  Through hole
RE2         J200-18         50.8mm    2.7432mm  Bottom             1mm  Through hole
RB3_UART2/4_RXJ200-17        48.26mm    2.3368mm  Bottom             1mm  Through hole
RB0_UART2/4_TXJ200-16        45.72mm    2.7432mm  Bottom             1mm  Through hole
GND         J200-15        43.18mm    2.3368mm  Bottom             1mm  Through hole
RD4_SPI1_SS J200-14        40.64mm    2.7432mm  Bottom             1mm  Through hole
RC6_SPI1_SCKJ200-13         38.1mm    2.3368mm  Bottom             1mm  Through hole
RC5_SPI1_MISOJ200-12        35.56mm    2.7432mm  Bottom             1mm  Through hole
RC4_SPI1_MOSIJ200-11        33.02mm    2.3368mm  Bottom             1mm  Through hole
RB1_I2C1_SCLJ200-10        30.48mm    2.7432mm  Bottom             1mm  Through hole
RB2_I2C1_SDAJ200-9         27.94mm    2.3368mm  Bottom             1mm  Through hole
RD1_UART2/4_RXJ200-8          25.4mm    2.7432mm  Bottom             1mm  Through hole
RD0_UART2/4_TXJ200-7         22.86mm    2.3368mm  Bottom             1mm  Through hole
DBG2        J200-6         20.32mm    2.7432mm  Bottom             1mm  Through hole
DBG1        J200-5         17.78mm    2.3368mm  Bottom             1mm  Through hole
CDC_TX      J200-4         15.24mm    2.7432mm  Bottom             1mm  Through hole
CDC_RX      J200-3          12.7mm    2.3368mm  Bottom             1mm  Through hole
RA6         J200-29         76.2mm   17.5768mm  Bottom             1mm  Through hole
RA7         J200-30        73.66mm   17.9832mm  Bottom             1mm  Through hole
RE0         J200-31        71.12mm   17.5768mm  Bottom             1mm  Through hole
RE1         J200-32        68.58mm   17.9832mm  Bottom             1mm  Through hole
GND         J200-33        66.04mm   17.5768mm  Bottom             1mm  Through hole
RF4         J200-34         63.5mm   17.9832mm  Bottom             1mm  Through hole
RF5         J200-35        60.96mm   17.5768mm  Bottom             1mm  Through hole
RF6         J200-36        58.42mm   17.9832mm  Bottom             1mm  Through hole
RF7         J200-37        55.88mm   17.5768mm  Bottom             1mm  Through hole
RA4         J200-38        53.34mm   17.9832mm  Bottom             1mm  Through hole
RD5         J200-39         50.8mm   17.5768mm  Bottom             1mm  Through hole
RD6         J200-40        48.26mm   17.9832mm  Bottom             1mm  Through hole
RD7         J200-41        45.72mm   17.5768mm  Bottom             1mm  Through hole
GND         J200-42        43.18mm   17.9832mm  Bottom             1mm  Through hole
RA0_ANA0    J200-43        40.64mm   17.5768mm  Bottom             1mm  Through hole
RA1_ANA1    J200-44         38.1mm   17.9832mm  Bottom             1mm  Through hole
RA2_ANA2    J200-45        35.56mm   17.5768mm  Bottom             1mm  Through hole
RB4_ANB4_PWM2/3J200-46        33.02mm   17.9832mm  Bottom             1mm  Through hole
RB5_ANB5_PWM2/3J200-47        30.48mm   17.5768mm  Bottom             1mm  Through hole
RA5_ANA5    J200-48        27.94mm   17.9832mm  Bottom             1mm  Through hole
RC0         J200-49         25.4mm   17.5768mm  Bottom             1mm  Through hole
GND         J200-52        17.78mm   17.9832mm  Bottom             1mm  Through hole
RC1         J200-50        22.86mm   17.9832mm  Bottom             1mm  Through hole
VCC_EDGE    J200-51        20.32mm   17.5768mm  Bottom             1mm  Through hole
            J200-1          7.62mm    2.3368mm  Bottom             1mm  Through hole
ID_SYS      J200-2         10.16mm    2.7432mm  Bottom             1mm  Through hole
RF3_LED0    J200-28         76.2mm    2.7432mm  Bottom             1mm  Through hole
DBG0        J200-53        15.24mm   17.5768mm  Bottom             1mm  Through hole
VBUS        J200-56         7.62mm   17.9832mm  Bottom             1mm  Through hole
SHIELD      J105-7          2.15mm     5.985mm  Bottom           0.5mm  Through hole
SWCLK       J102-1          3.19mm    10.795mm  Bottom             0mm  Surface mount
VCC_P3V3    J102-4          4.46mm     9.525mm  Bottom             0mm  Surface mount
SWDIO       J102-5          5.73mm    10.795mm  Bottom             0mm  Surface mount
S\R\S\T\    J102-6          5.73mm     9.525mm  Bottom             0mm  Surface mount
BOOT        TP100-1        10.81mm     5.777mm  Bottom             0mm  Surface mount

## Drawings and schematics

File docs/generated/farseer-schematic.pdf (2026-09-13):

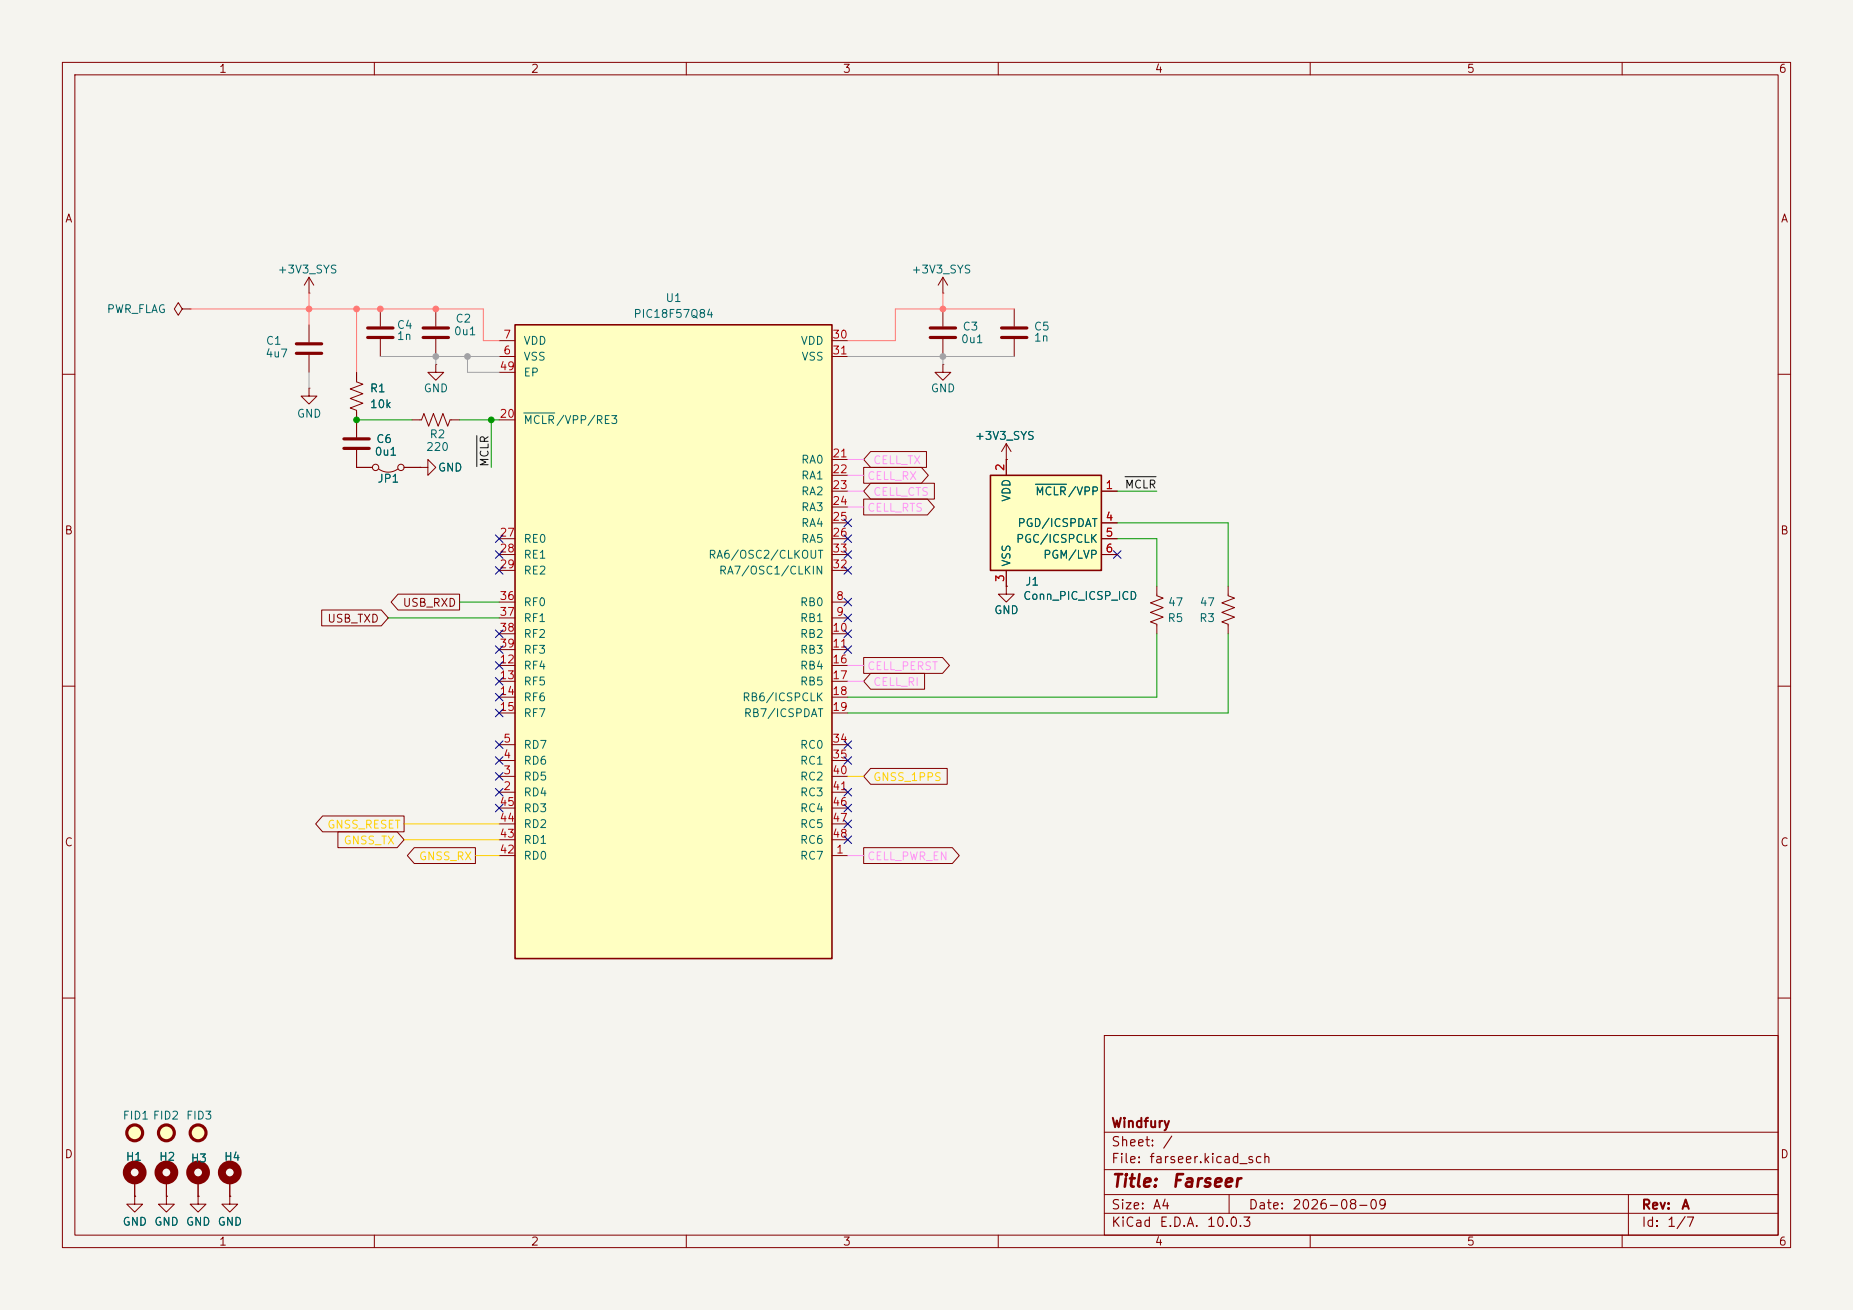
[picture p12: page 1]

3 PGD/ICSPDAT 4 PGC/ICSPCLK 5 PGM/LVP 6 +3V3_SYS GND

3 PGD/ICSPDAT 4 PGC/ICSPCLK 5 PGM/LVP 6

Size: A4 | Rev: A
KiCad E.D.A. 10.0.3 | Id: 1/7

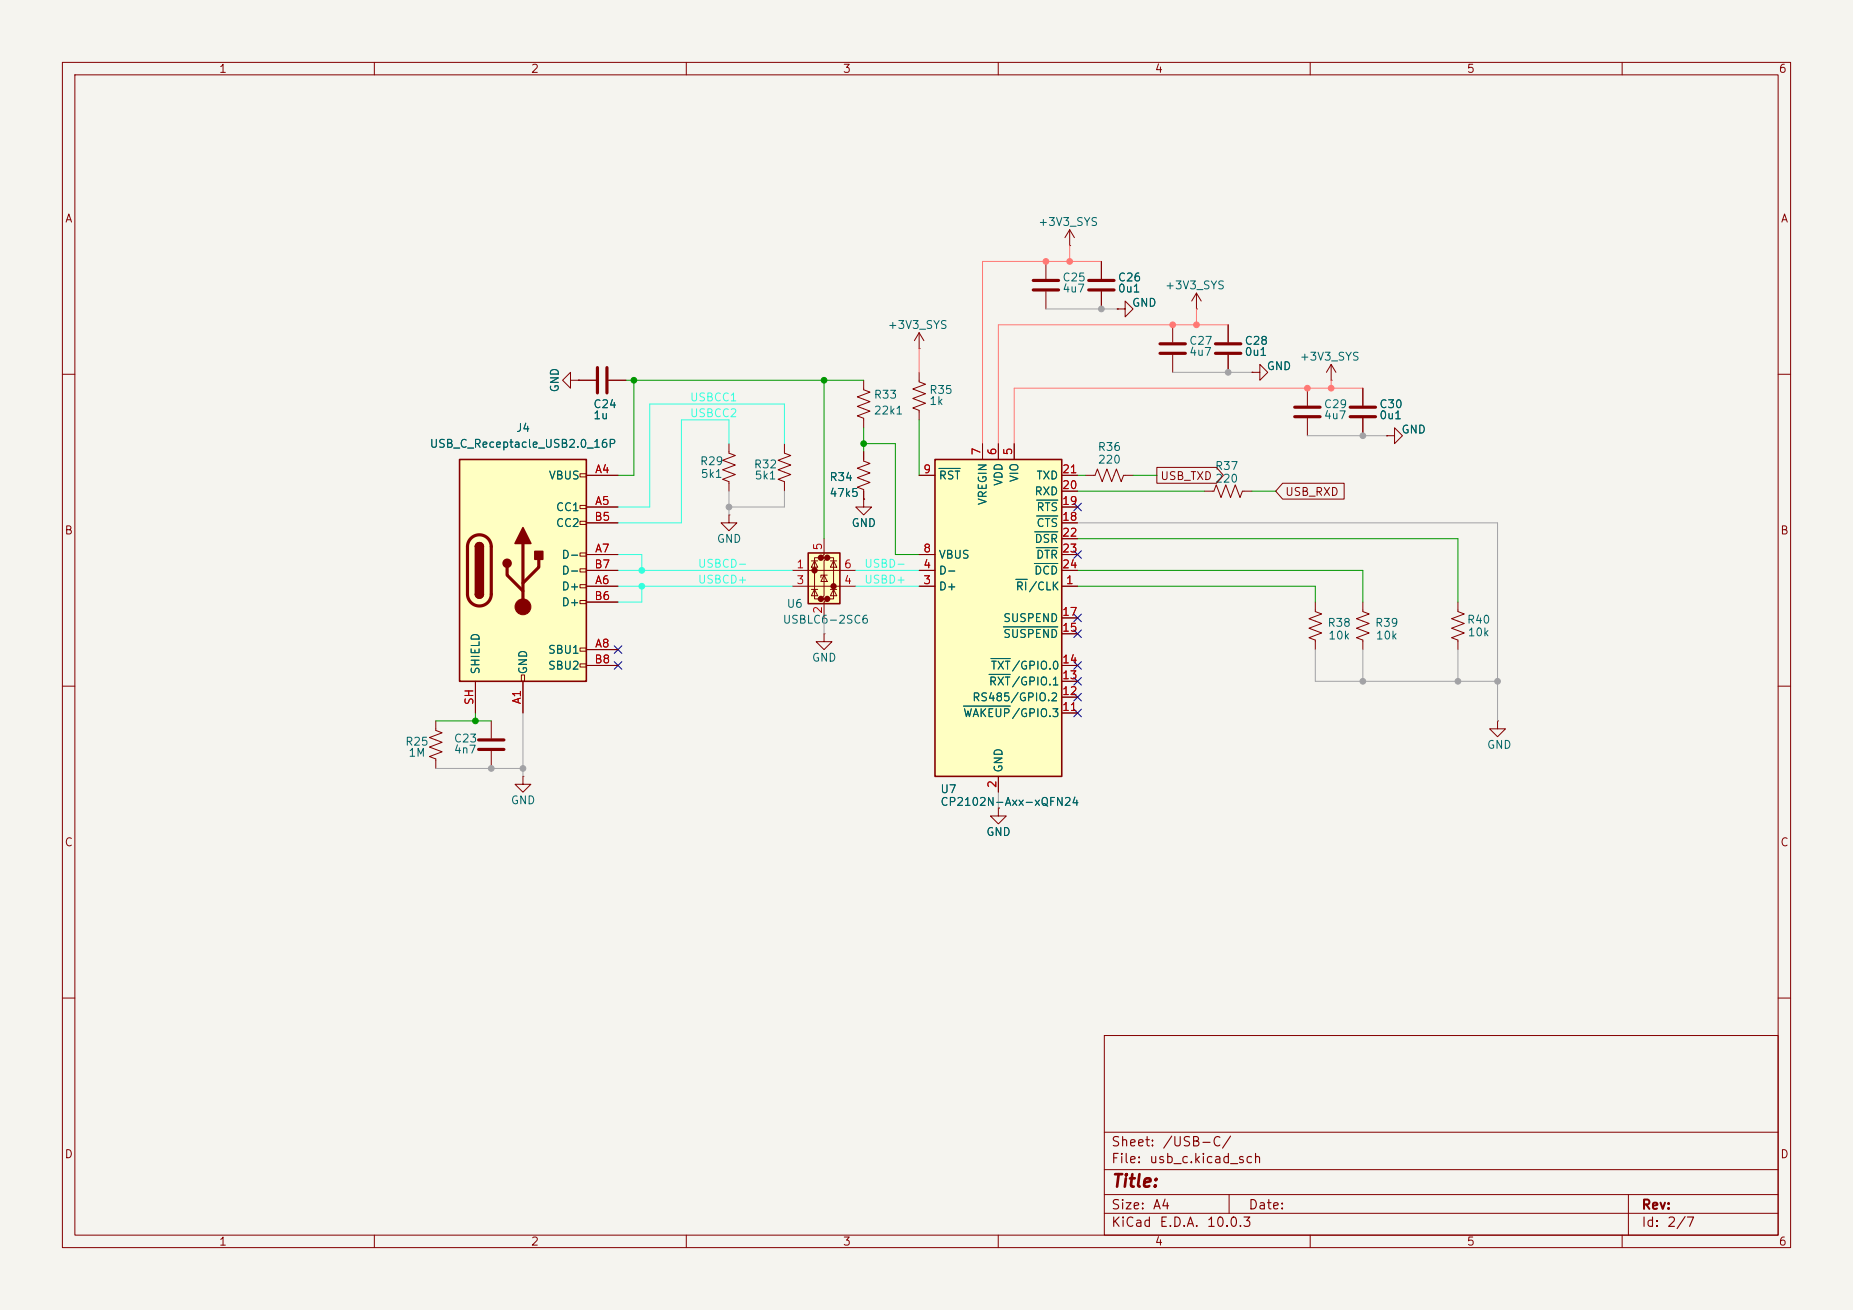
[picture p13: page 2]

SUSPEND 15 SUSPEND 17 CTS 18 RTS 19 RXD 20 TXD 21 DSR 22 DTR 23 DCD 24 R34

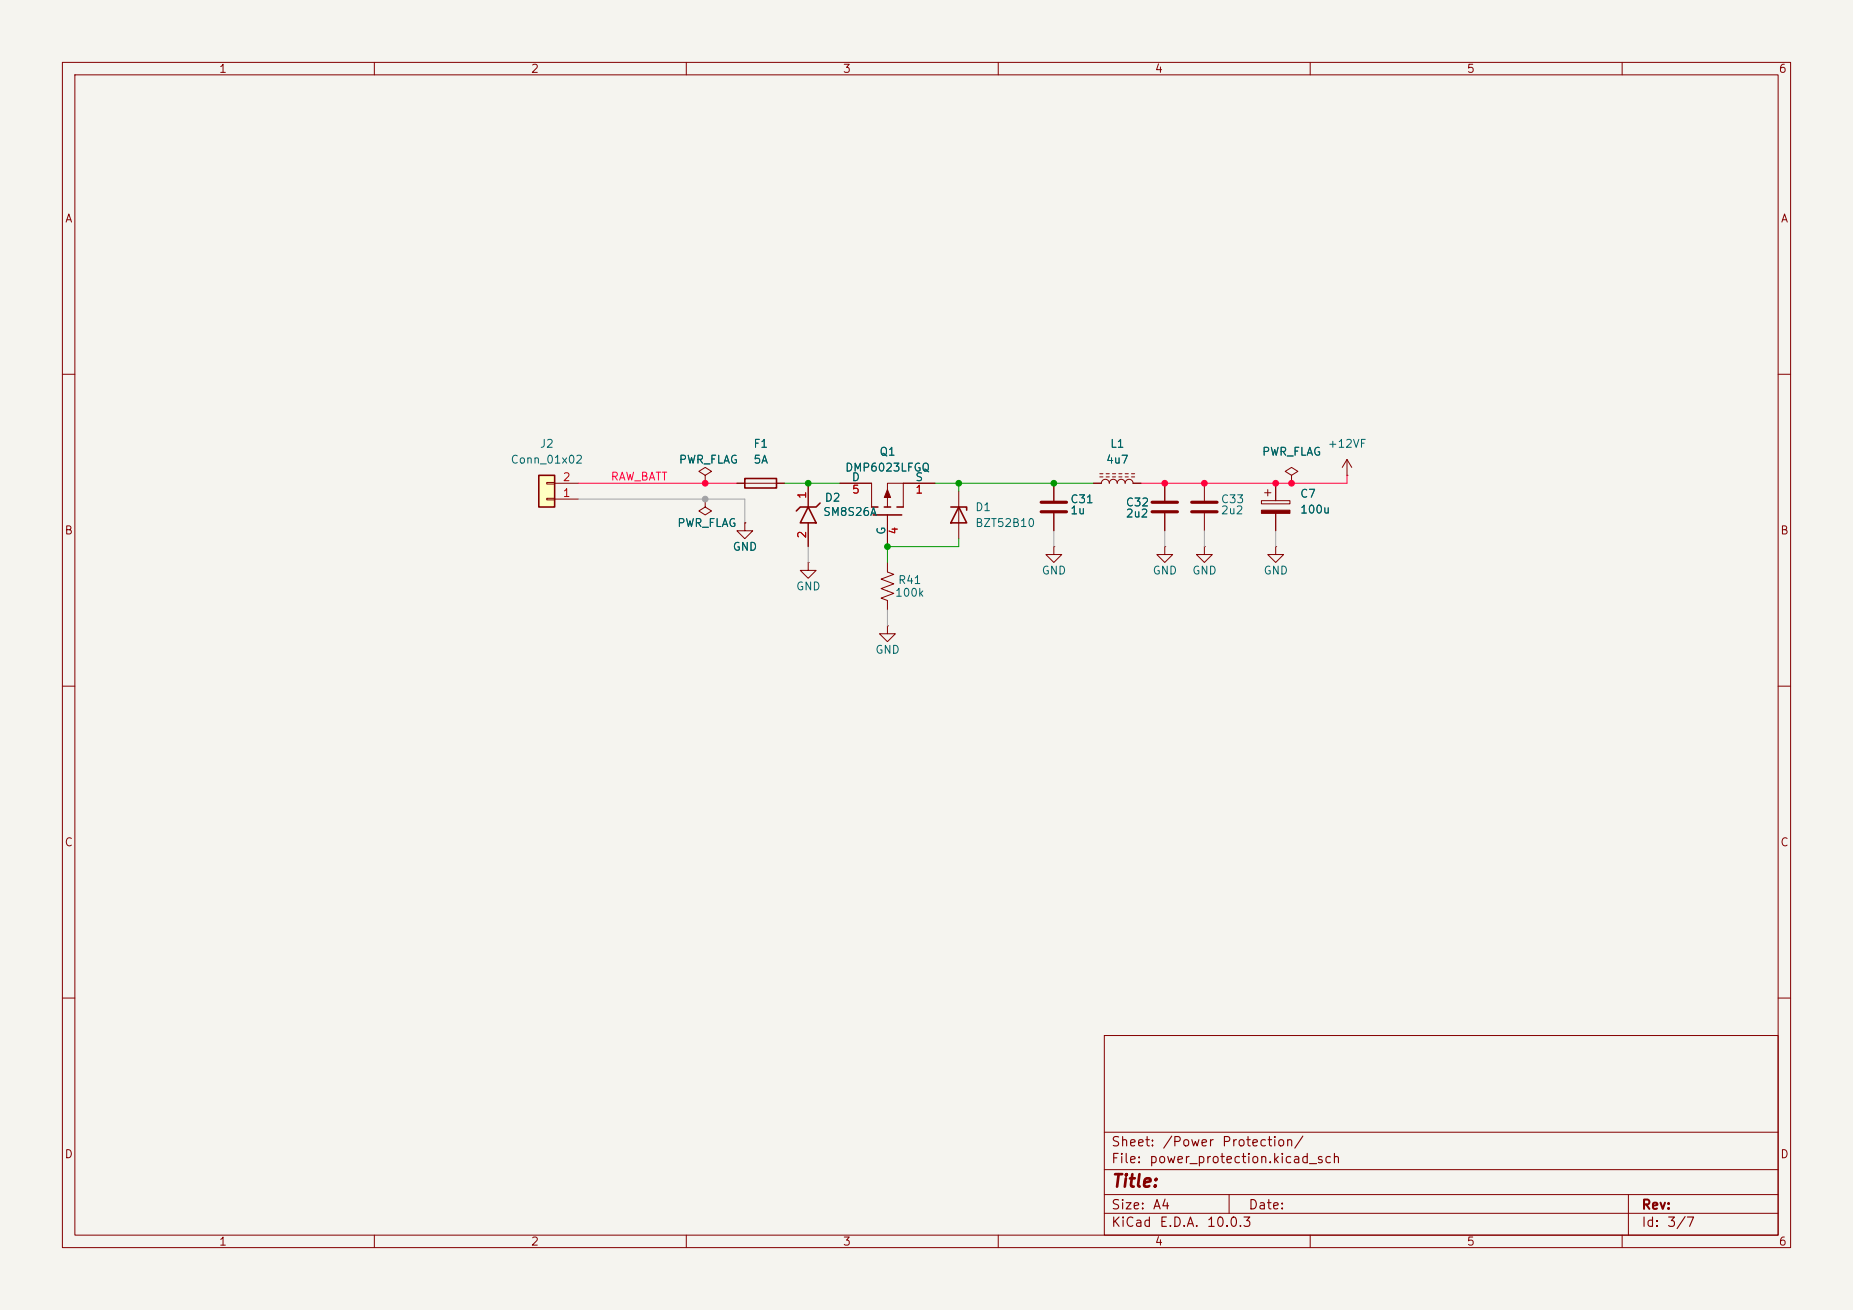
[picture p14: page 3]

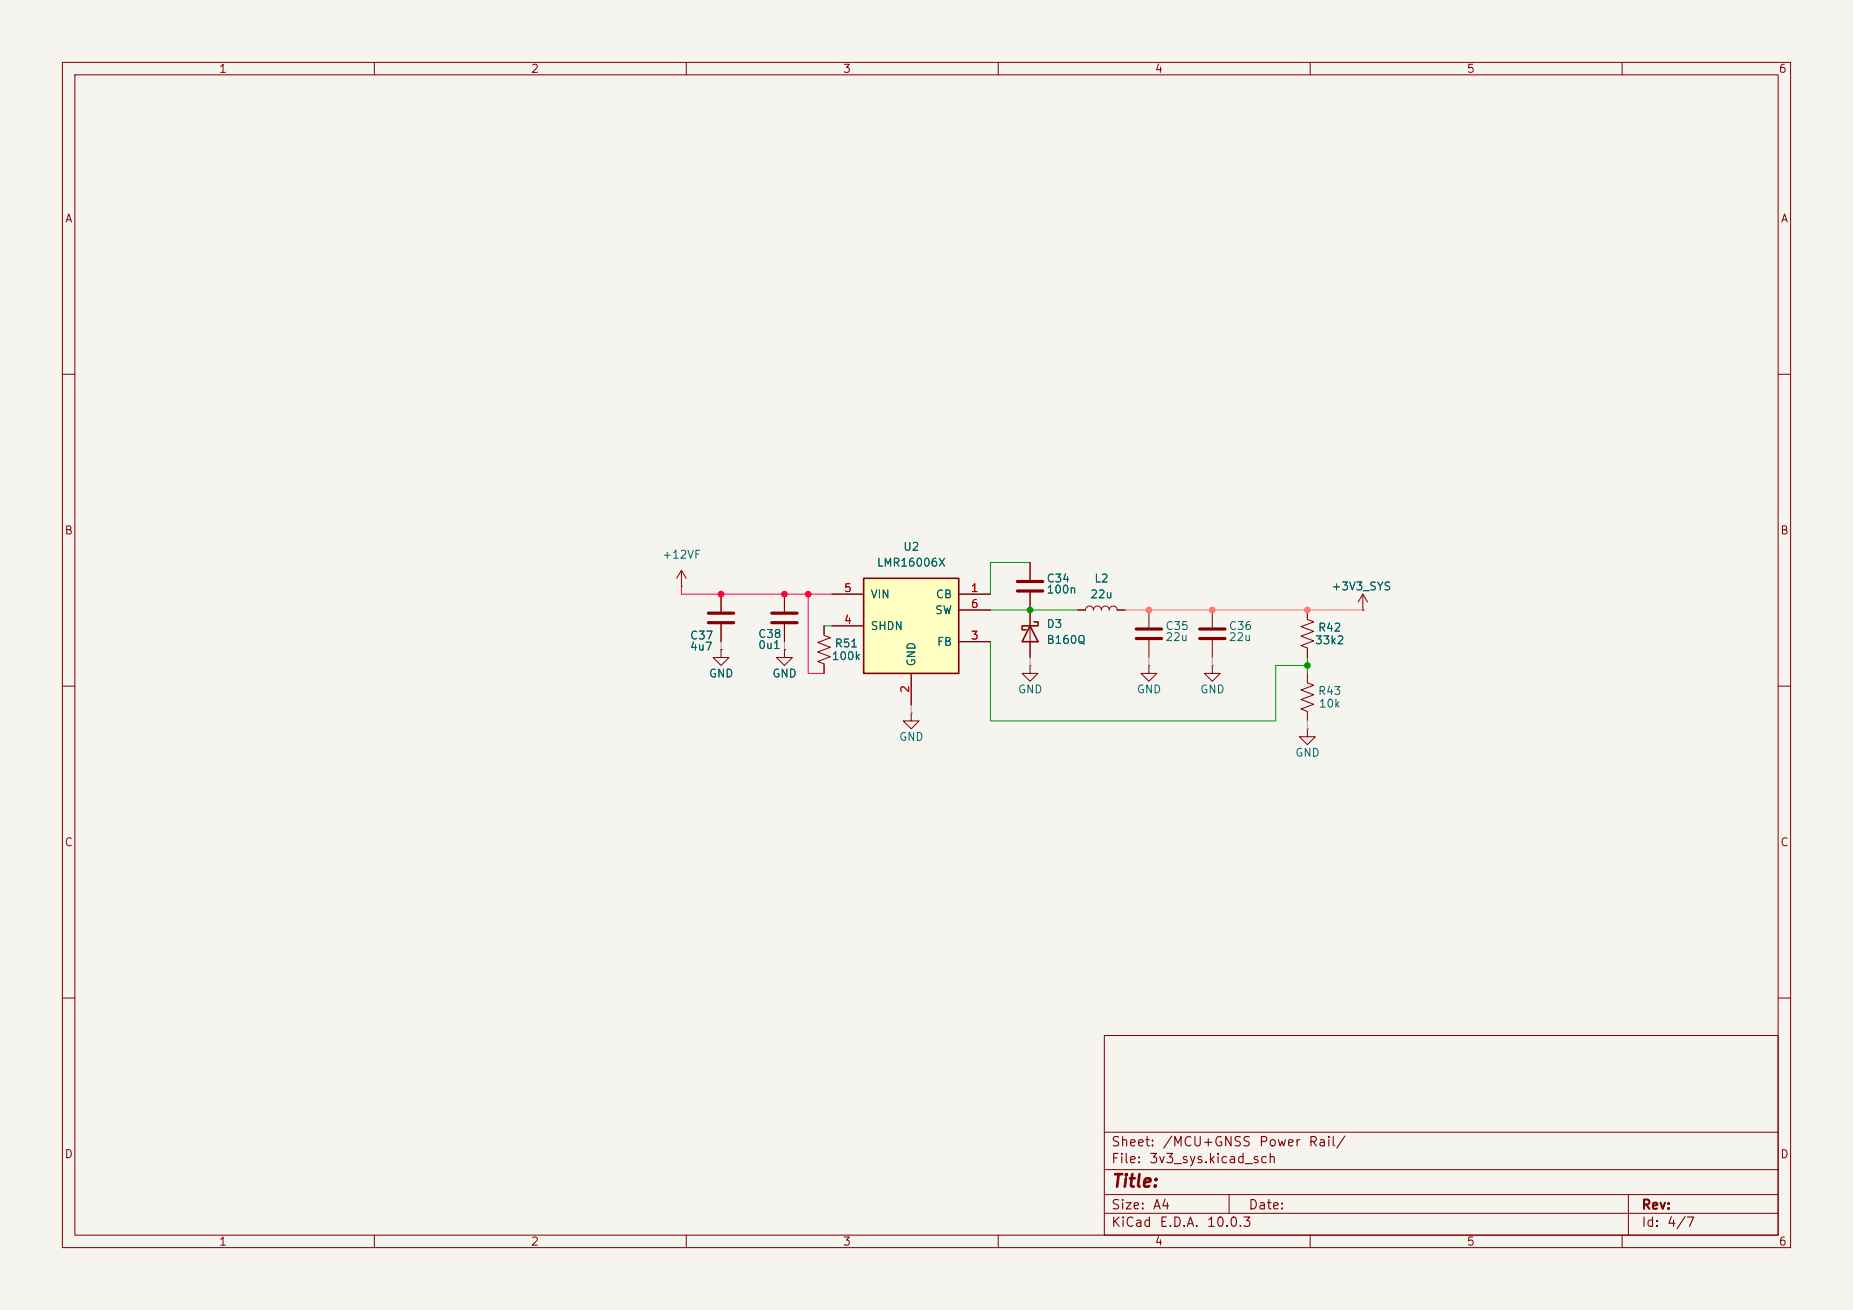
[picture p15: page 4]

Sheet: /MCU+GNSS Power Rail/
File: 3v3_sys.kicad_sch
Title:

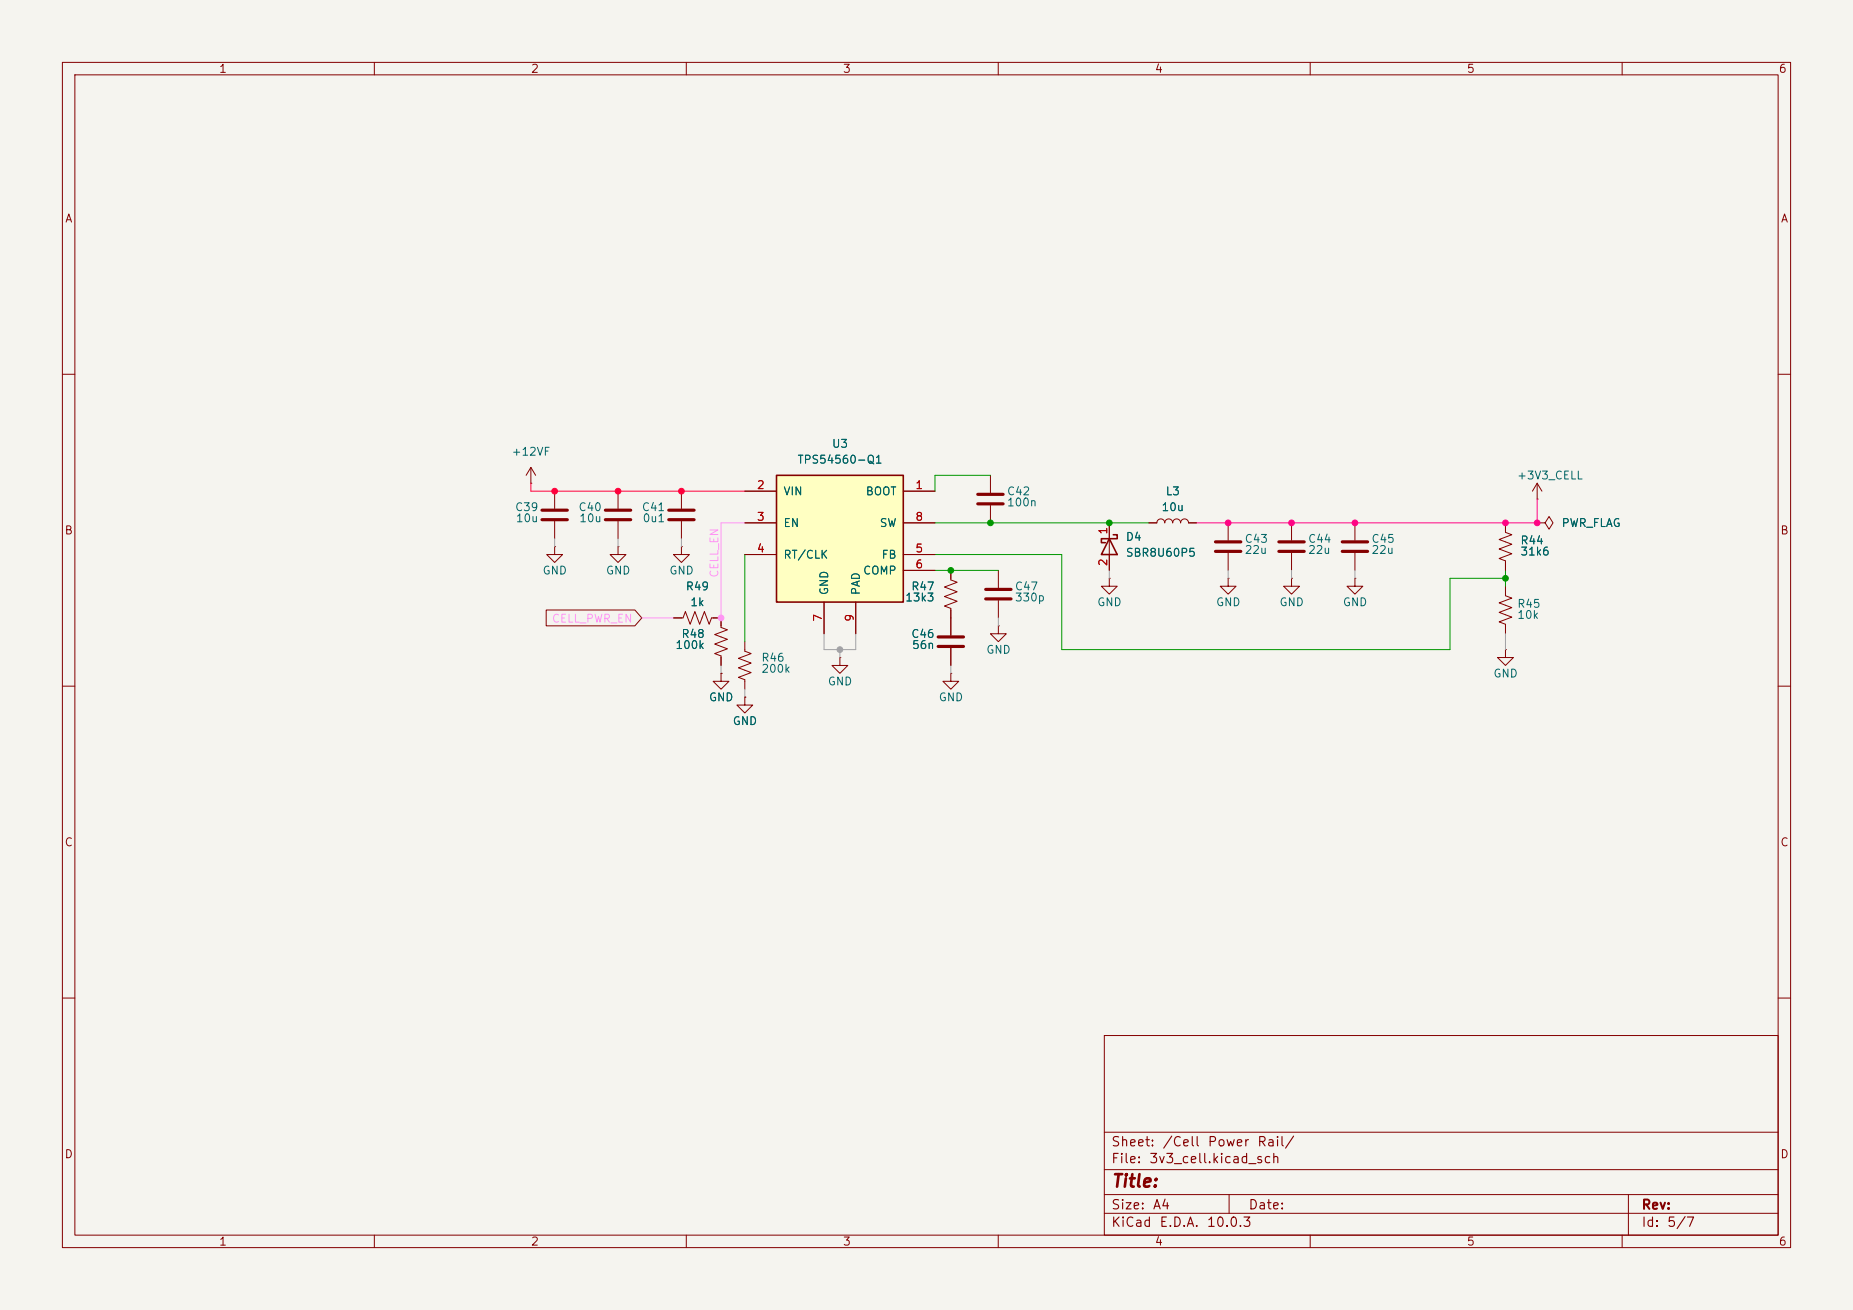
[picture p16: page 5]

Sheet: /Cell Power Rail/
File: 3v3_cell.kicad_sch
Title:

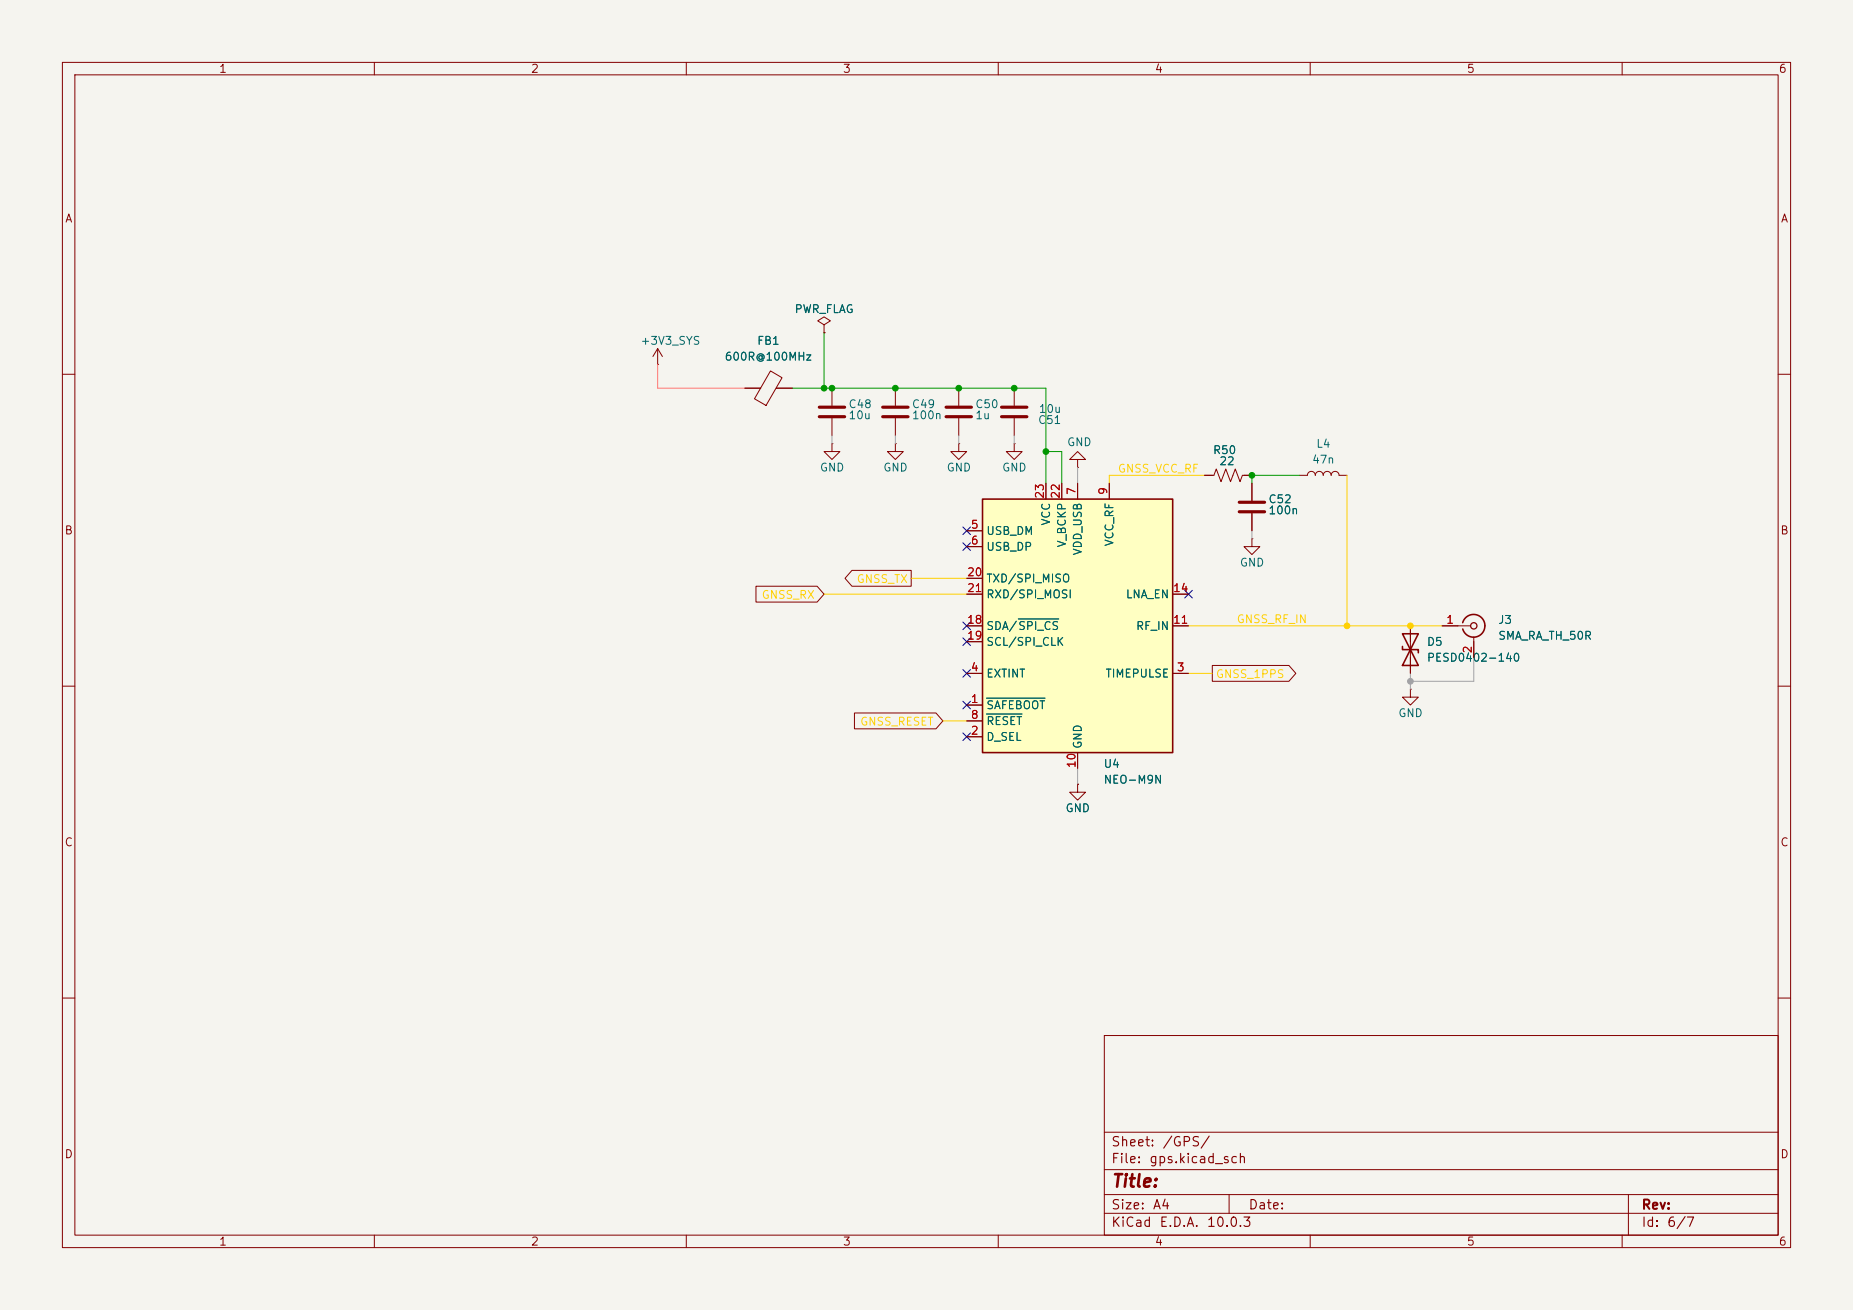
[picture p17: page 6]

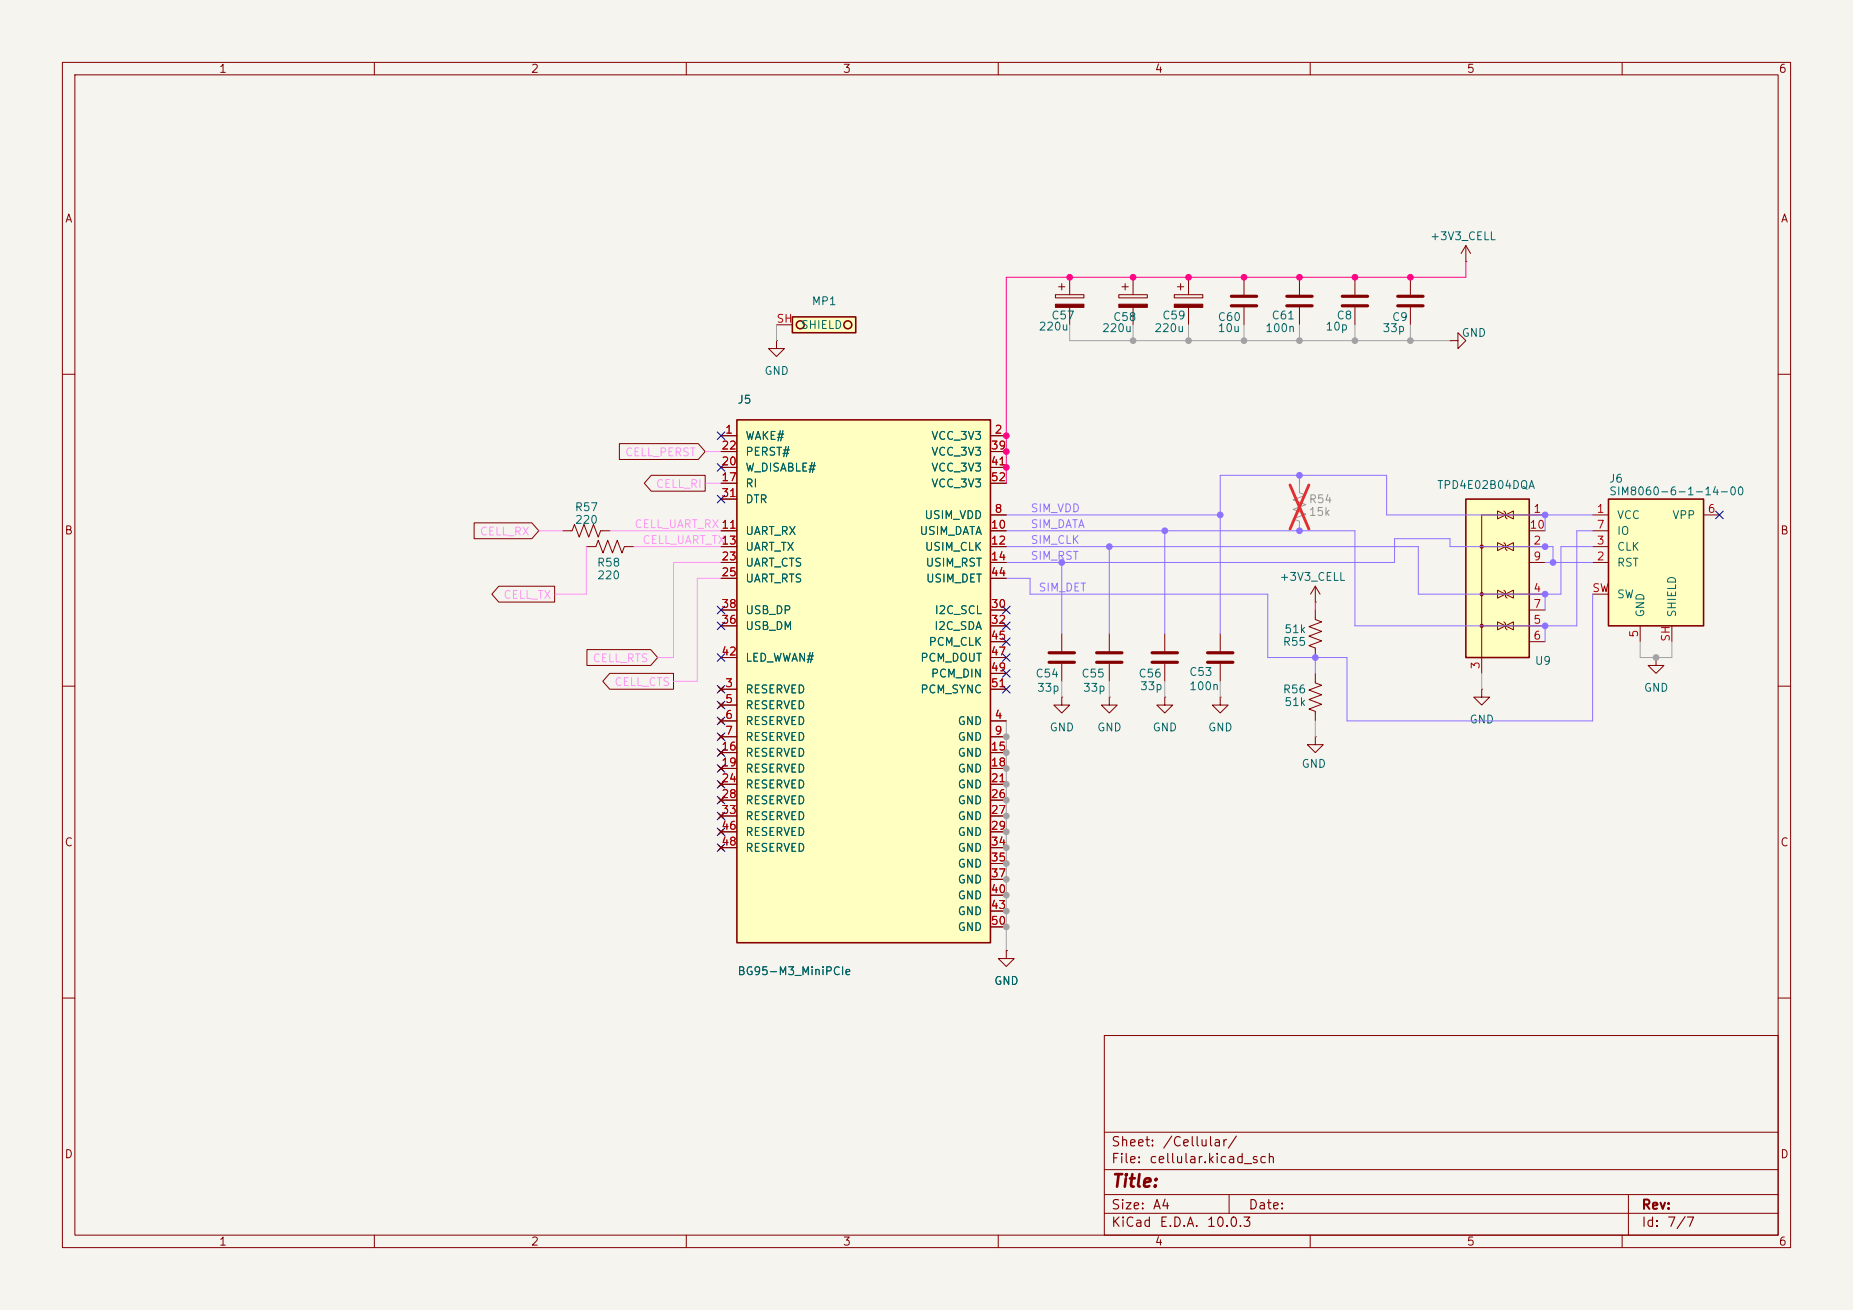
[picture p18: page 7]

SIM_DET SIM_CLK

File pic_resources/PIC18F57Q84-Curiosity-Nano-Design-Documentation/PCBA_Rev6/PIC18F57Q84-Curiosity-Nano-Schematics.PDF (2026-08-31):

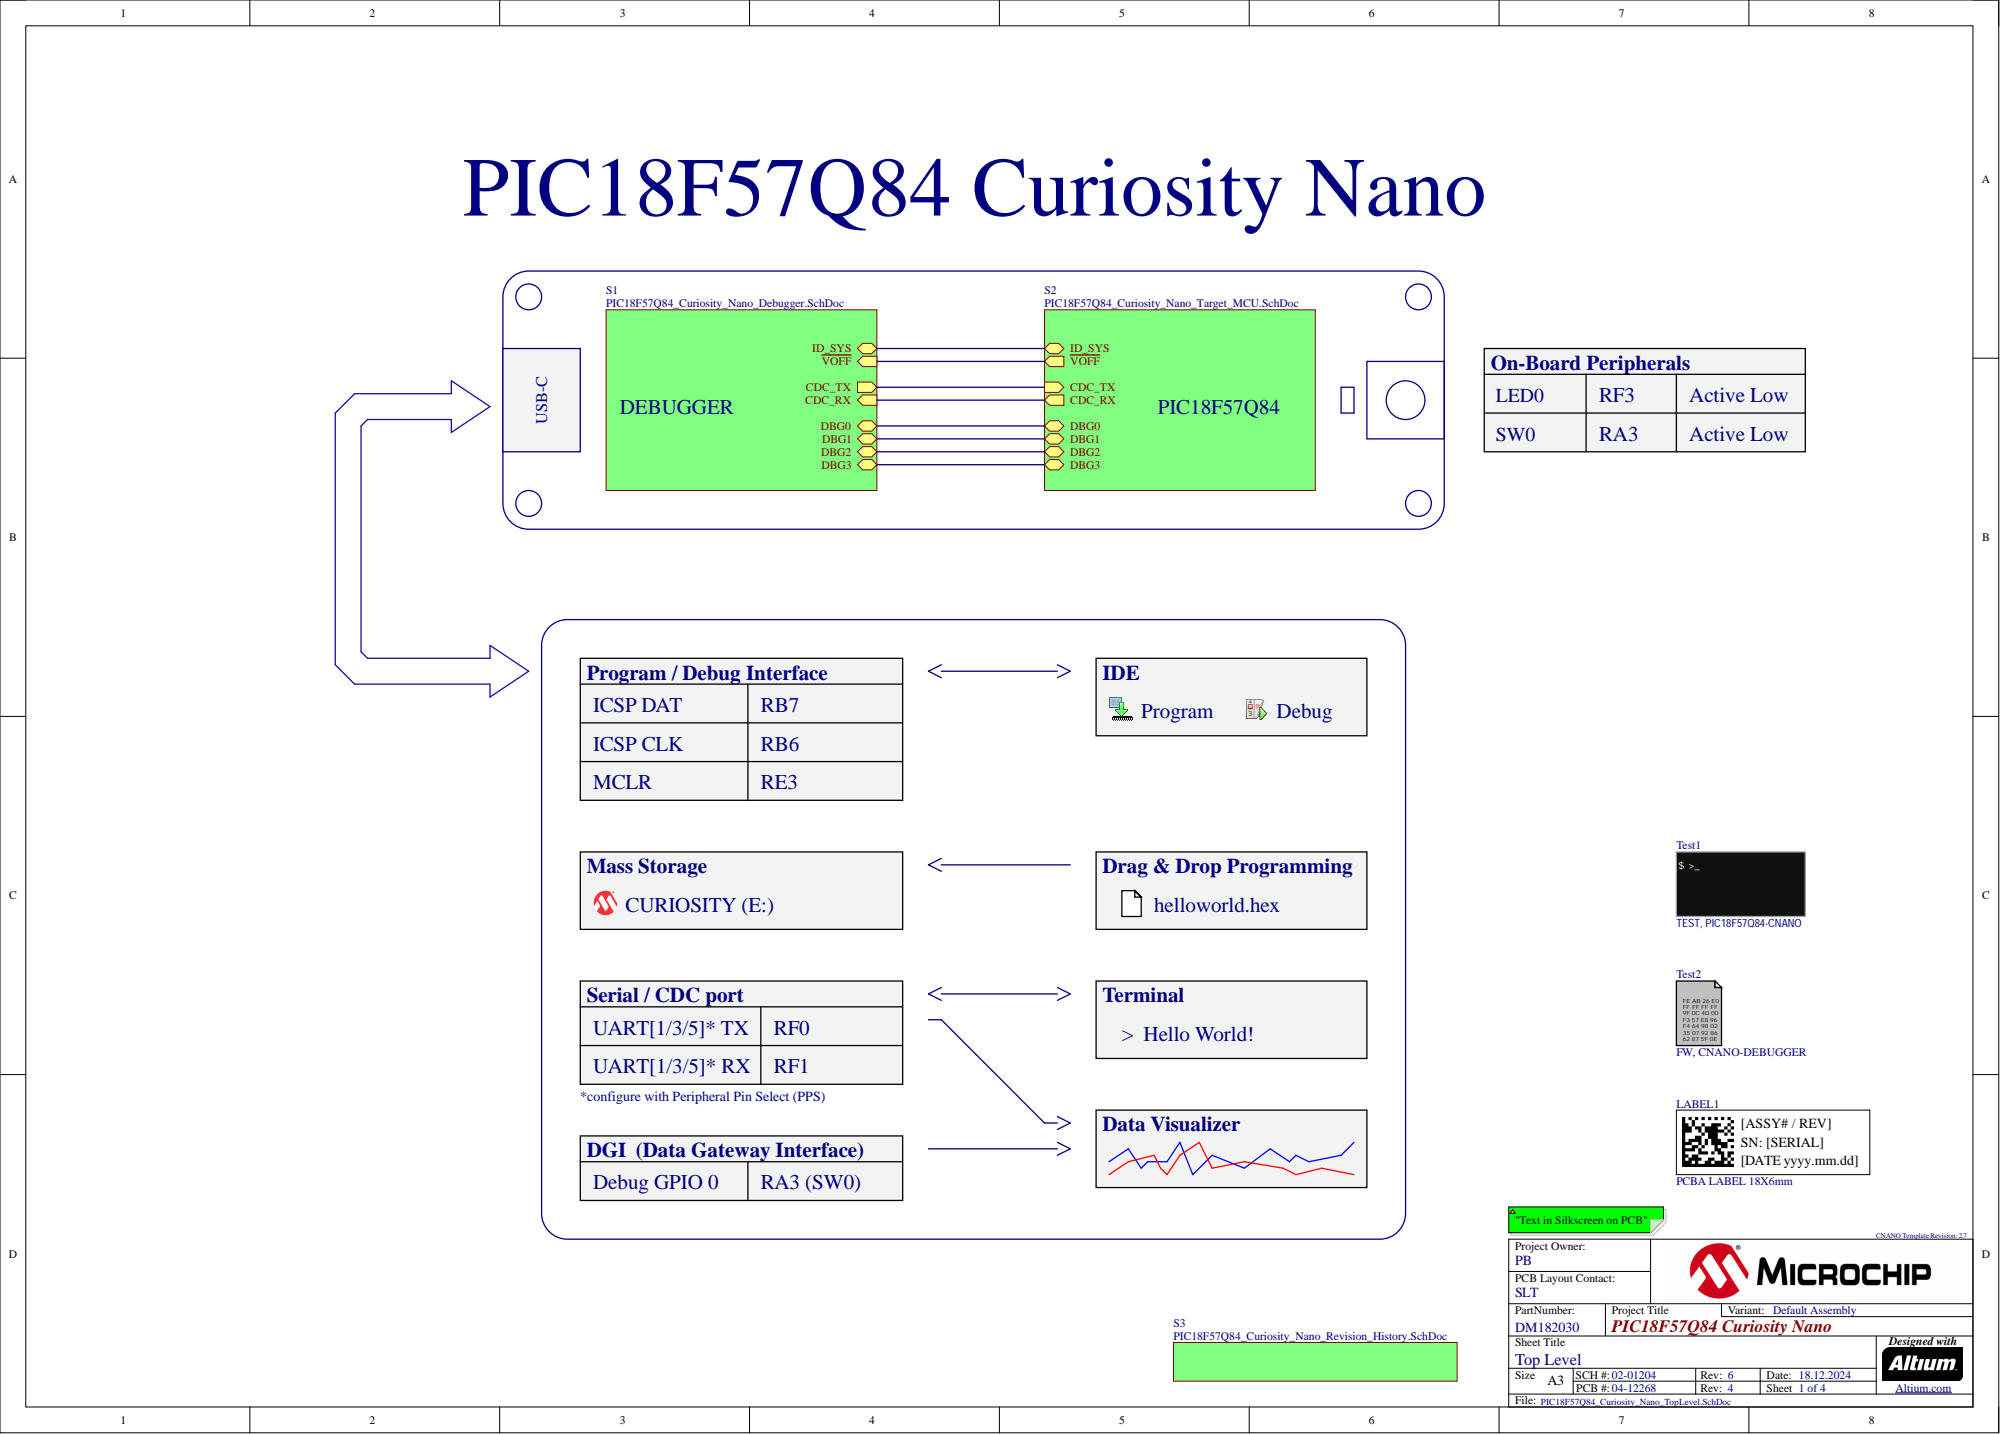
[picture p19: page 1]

LED0 | RF3 | Active Low

SW0 | RA3 | Active Low

ICSP DAT | RB7

ICSP CLK | RB6

MCLR | RE3

UART[1/3/5]* TX | RF0

UART[1/3/5]* RX | RF1

*configure with Peripheral Pin Select (PPS)

[ASSY# / REV]
SN: [SERIAL]
[DATE yyyy.mm.dd]

DGI (Data Gateway Interface)

"Text in Silkscreen on PCB"

Sheet Title Top Level | Designed with Altium.com

Size A3 | SCH #: 02-01204 | Rev: 6 | Date: 18.12.2024

PCB #: 04-12268 | Rev: 4 | Sheet

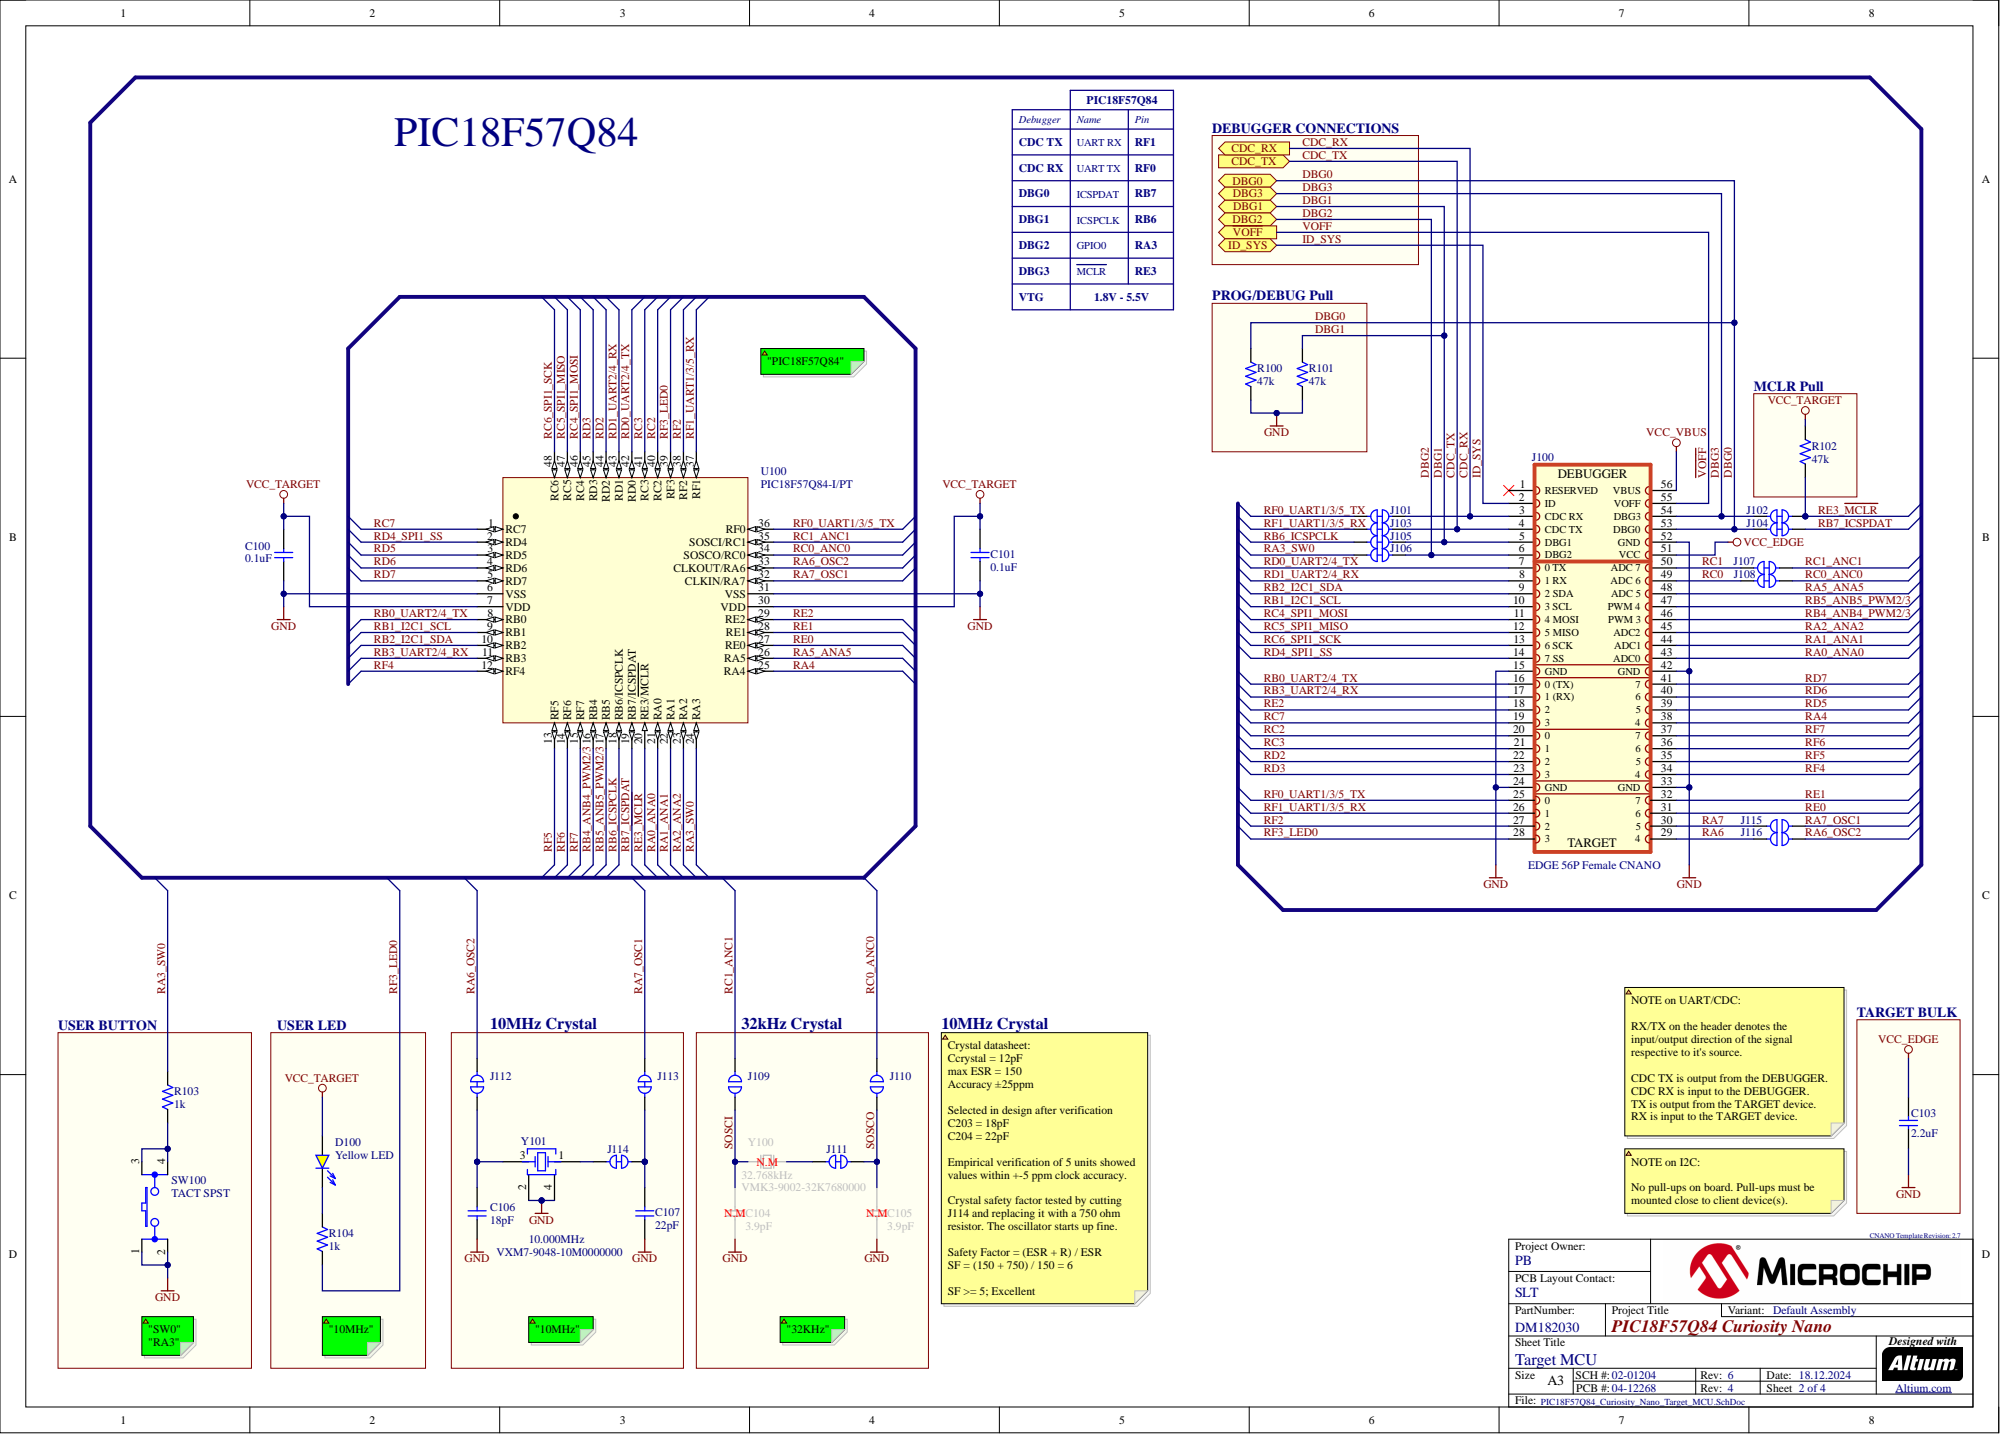
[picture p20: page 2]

Deb u g g e r | Na m e | Pi n

CDC TX | UAR T RX | RF1

CDC_RX | CDC_RX

CDC_TX
DBG 0

CDC RX | UAR T TX | RF0

DBG3 | MC L R | RE3

VTG | 1.8V - 5.5V

DBG 1

NOTE on UART/CDC:

RX/TX on the header denotes the
input/output direction of the signal
respective to it's source.

CDC TX is output from the DEBUG
CDC RX is input to the DEBUG
TX is output from the TARGET device.
RX is input to the TARGET device.

Empirical verification of 5 units showed
values within +-5 ppm clock accuracy

No pull-ups on board. Pull-ups must be
mounted close to client device(s).

Crystal safety factor tested by cutting
J114 and replacing it with a 750 ohm
resistor. The oscillator starts up fine.

Safety Factor = (ESR + R) / ESR

Sheet Title Target MCU | Designed with Altium.com

Size A 3 | SCH #: 02-01204 | Rev: 6 | Date: 18.12.2024

PCB #: 04-12268 | Rev: 4 | Sheet

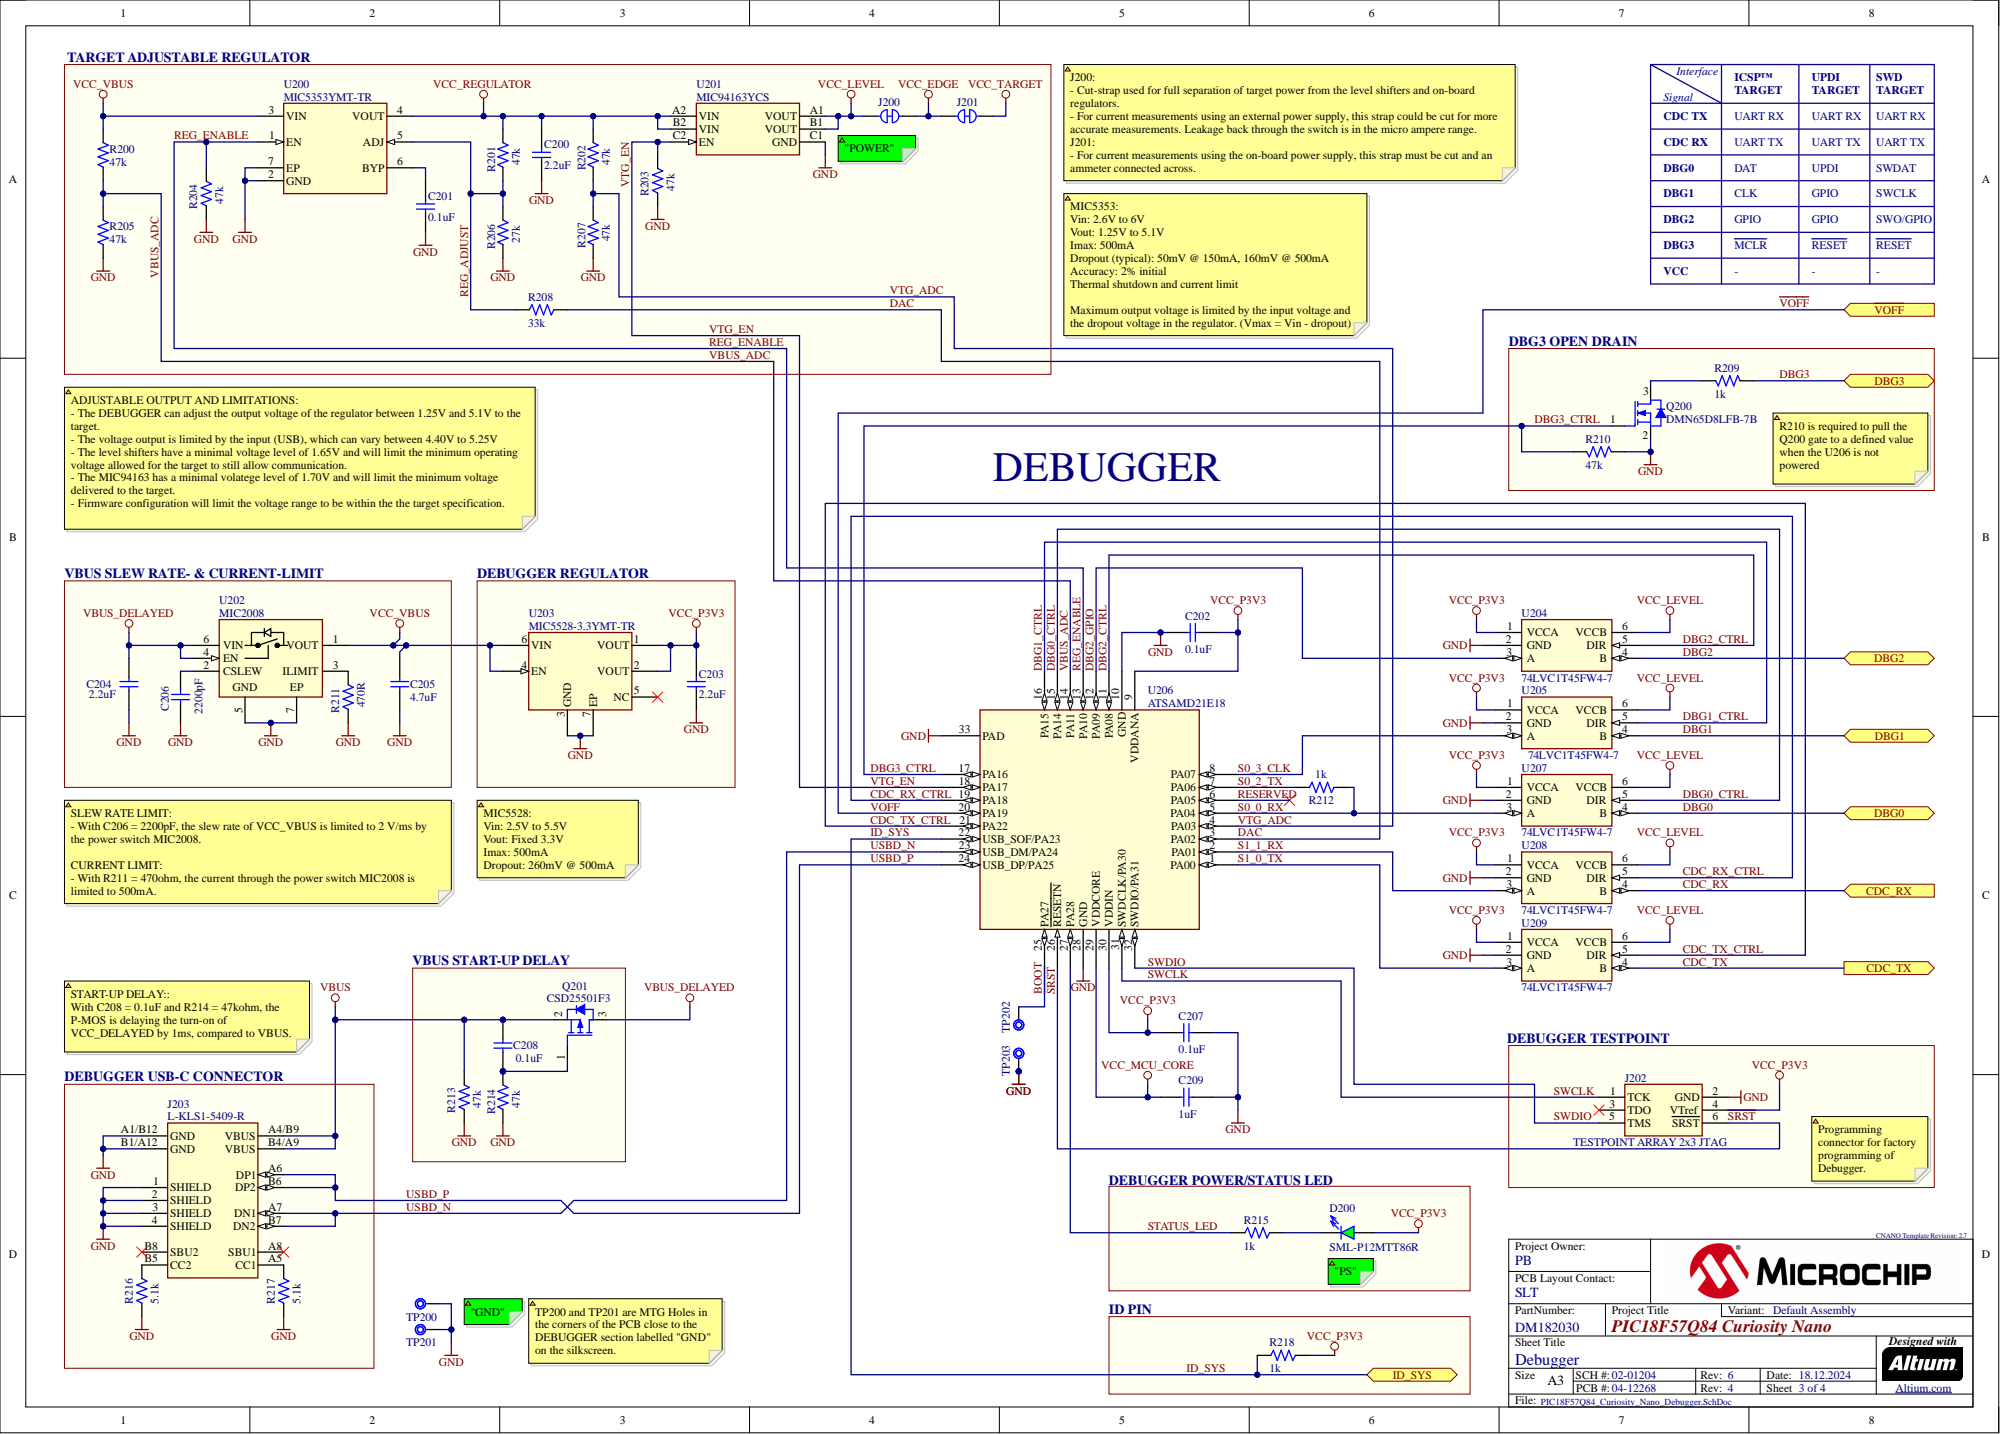
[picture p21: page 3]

- Cut-strap used for full separation of target power from the level shifters and on-board
regulators.
- For current measurements using an external power supply, this strap could be cut for more
accurate measurements. Leakage back through the switch is in the micro ampere range.
- For current measurements using the on-board power supply, this strap must be cut and an
ammeter connected across.

DBG1 | CLK | GPIO | SWCLK

MIC5353:
Vin: 2.6V to 6V
Vout: 1.25V to 5.1V
Imax: 500mA
Dropout (typical): 50mV @ 150mA, 160mV @ 500mA
Accuracy: 2% initial
Thermal shutdown and current limit

GPIO

Maximum output voltage is limited by the input voltage and
the dropout voltage in the regulator. (Vmax = Vin - dropout)

ADJUSTABLE OUTPUT AND LIMITATIONS:
- The DEBUGGER can adjust the output voltage of the regulator between 1.25V and 5.1V to the
target.
- The voltage output is limited by the input (USB), which can vary between 4.40V to 5.25V
- The level shifters have a minimal voltage level of 1.65V and will limit the minimum operating
voltage allowed for the target to still allow communication.
- The MIC94163 has a minimal volatege level of 1.70V and will limit the minimum voltage
delivered to the target.
- Firmware configuration will limit the voltage range to be within the the target specification.

R210 is required to pull the
Q200 gate to a defined value
when the U206 is not
powered

VBUS SLEW RATE- & CURRENT-LIMIT

VCC_P3V3 C202 | VCC_P3V3

VCC_LEVEL U204

SLEW RATE LIMIT:
- With C206 = 2200pF, the slew rate of VCC_VBUS is limited to 2 V/ms by
the power switch MIC2008.

CURRENT LIMIT:
- With R211 = 470ohm, the current through the power switch MIC2008 is
limited to 500mA.

VBUS START-UP DELAY

START-UP DELAY::
With C208 = 0.1uF and R214 = 47kohm, the
P-MOS is delaying the turn-on of
VCC_DELAYED by 1ms, compared to VBUS.

DEBUGGER POWER/STATUS LED

TP200 and TP201 are MTG Holes in
the corners of the PCB close to the
DEBUGGER section labelled "GND"
on the silkscreen.

Sheet Title Debugger | Designed with Altium.com

Size A3 | SCH #: 02-01204 | Rev: 6 | Date: 18.12.2024

PCB #: 04-12268 | Rev: 4 | Sheet

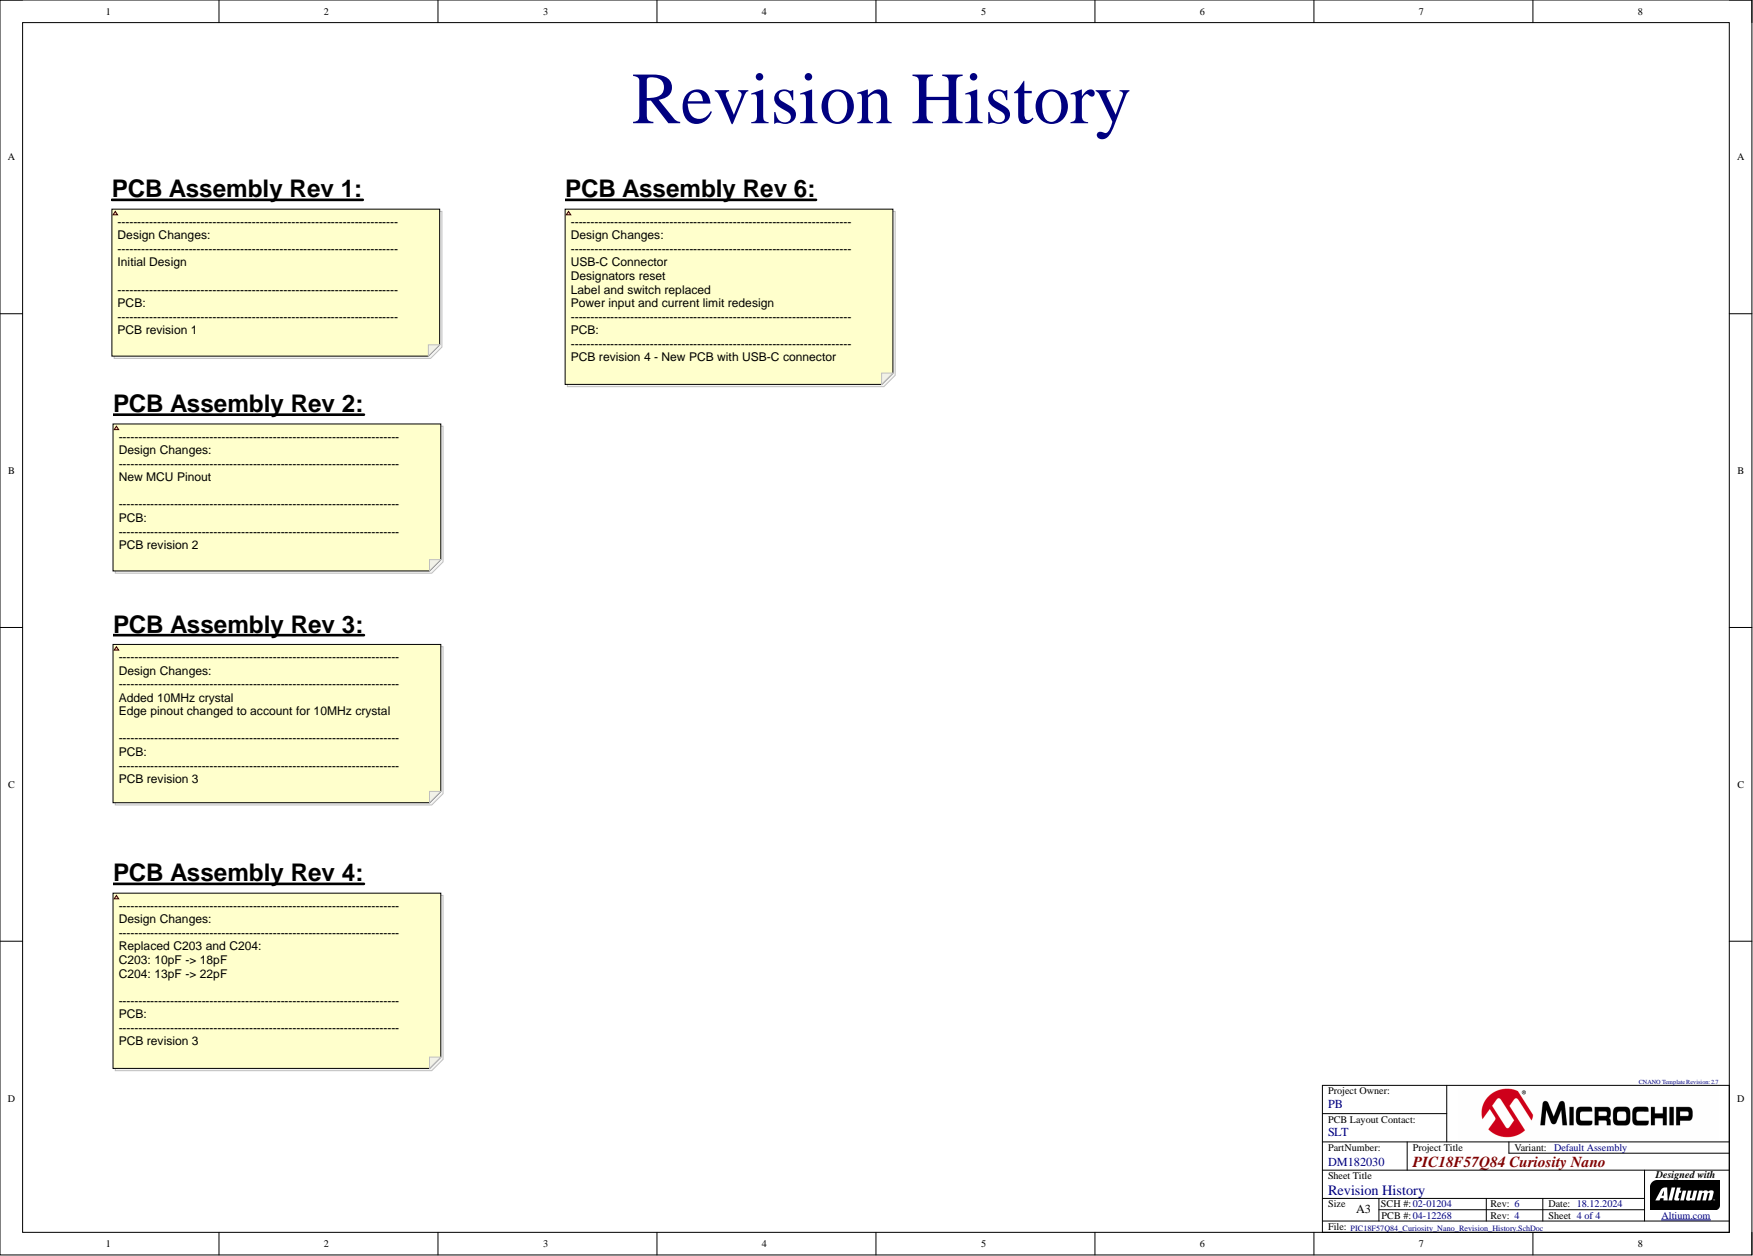
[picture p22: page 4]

Design Changes:
USB-C Connector
Designators reset
Label and switch replaced
Power input and current limit redesign
PCB:
PCB revision 4 - New PCB with USB-C connector

Added 10MHz crystal
Edge pinout changed to account for 10MHz crystal

Sheet Title Revision History | Designed with Altium.com

Size A3 | SCH #: 02-01204 | Rev: 6 | Date: 18.12.2024

PCB #: 04-12268 | Rev: 4 | Sheet

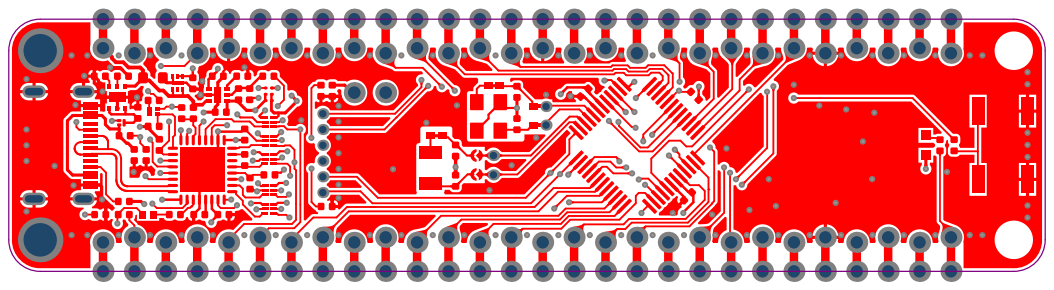
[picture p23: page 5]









Centerline of staggered through-
holes for pin headers.


Test Point Placement [Bottom View]

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





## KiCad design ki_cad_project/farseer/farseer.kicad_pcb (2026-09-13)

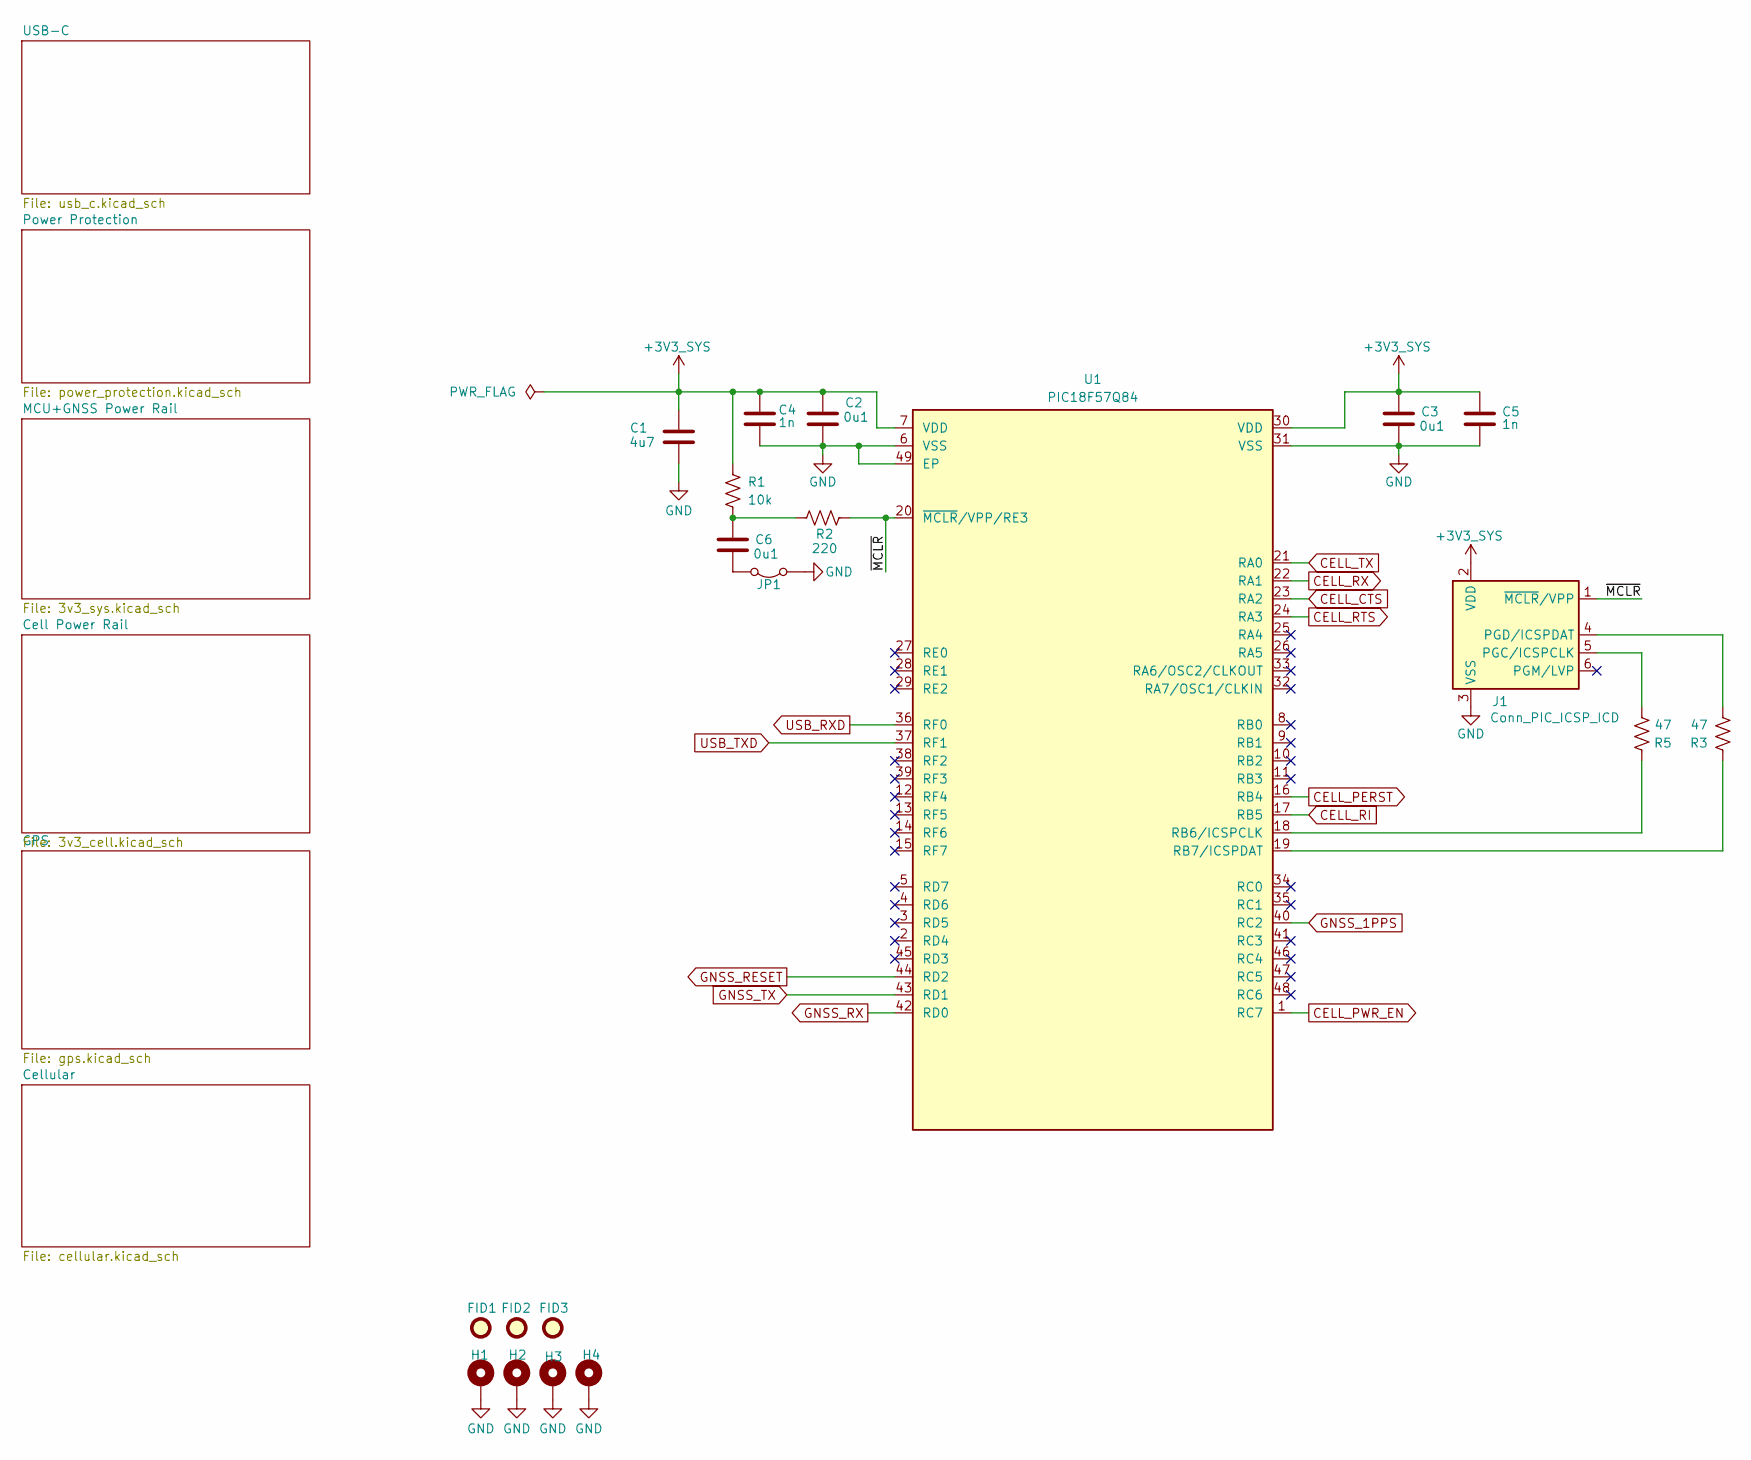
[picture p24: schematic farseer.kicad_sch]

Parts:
C1: 4u7; C_0805_2012Metric; MPN GCM21BR71C475KA73L
C2, C3, C6: 0u1; C_0402_1005Metric; MPN GCM155R71E104KE02D
C4, C5: 1n; C_0402_1005Metric; MPN GCM155R71H102KA37D
FID1, FID2, FID3: Fiducial; Fiducial_1mm_Mask2mm
H1, H2, H3, H4: MountingHole; MountingHole_3.2mm_M3_Pad_Via
J1: Conn_PIC_ICSP_ICD; PinHeader_1x06_P2.54mm_Vertical; MPN 61300611021
JP1: PinHeader_1x02_P2.54mm_Vertical; MPN 61300211121
R1: 10k; R_0603_1608Metric; MPN AC0603FR-0710KL
R2: 220; R_0603_1608Metric; MPN AC0603FR-07220RL
R3, R5: 47; R_0603_1608Metric; MPN AC0603FR-0747RL
U1: PIC18F57Q84; TQFP-48-1EP_7x7mm_P0.5mm_EP3.5x3.5mm_ThermalVias; MPN PIC18F57Q84-I/PT; DigikeyPN 150-PIC18F57Q84-I/PT-ND

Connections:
+3V3_SYS: C1.2, C2.1, C3.1, C4.1, C5.1, J1.2 (VDD), R1.1, U1.7 (VDD), U1.30 (VDD); also elsewhere on the board
/~MCLR: J1.1 (~MCLR/VPP), R2.2, U1.20 (~MCLR/VPP/RE3)
CELL_CTS: U1.23 (RA2); also elsewhere on the board
CELL_PERST: U1.16 (RB4); also elsewhere on the board
CELL_PWR_EN: U1.1 (RC7); also elsewhere on the board
CELL_RI: U1.17 (RB5); also elsewhere on the board
CELL_RTS: U1.24 (RA3); also elsewhere on the board
CELL_RX: U1.22 (RA1); also elsewhere on the board
CELL_TX: U1.21 (RA0); also elsewhere on the board
GND: C1.1, C2.2, C3.2, C4.2, C5.2, H1.1 (1_1), H2.1 (1_1), H3.1 (1_1), H4.1 (1_1), J1.3 (VSS), JP1.2 (B), U1.6 (VSS), U1.31 (VSS), U1.49 (EP); also elsewhere on the board
GNSS_1PPS: U1.40 (RC2); also elsewhere on the board
GNSS_RESET: U1.44 (RD2); also elsewhere on the board
GNSS_RX: U1.42 (RD0); also elsewhere on the board
GNSS_TX: U1.43 (RD1); also elsewhere on the board
unnamed: C6.1, R1.2, R2.1
unnamed: J1.5 (PGC/ICSPCLK), R5.2
unnamed: J1.4 (PGD/ICSPDAT), R3.2
unnamed: C6.2, JP1.1 (A)
unnamed: R5.1, U1.18 (RB6/ICSPCLK)
unnamed: R3.1, U1.19 (RB7/ICSPDAT)
USB_RXD: U1.36 (RF0); also elsewhere on the board
USB_TXD: U1.37 (RF1); also elsewhere on the board

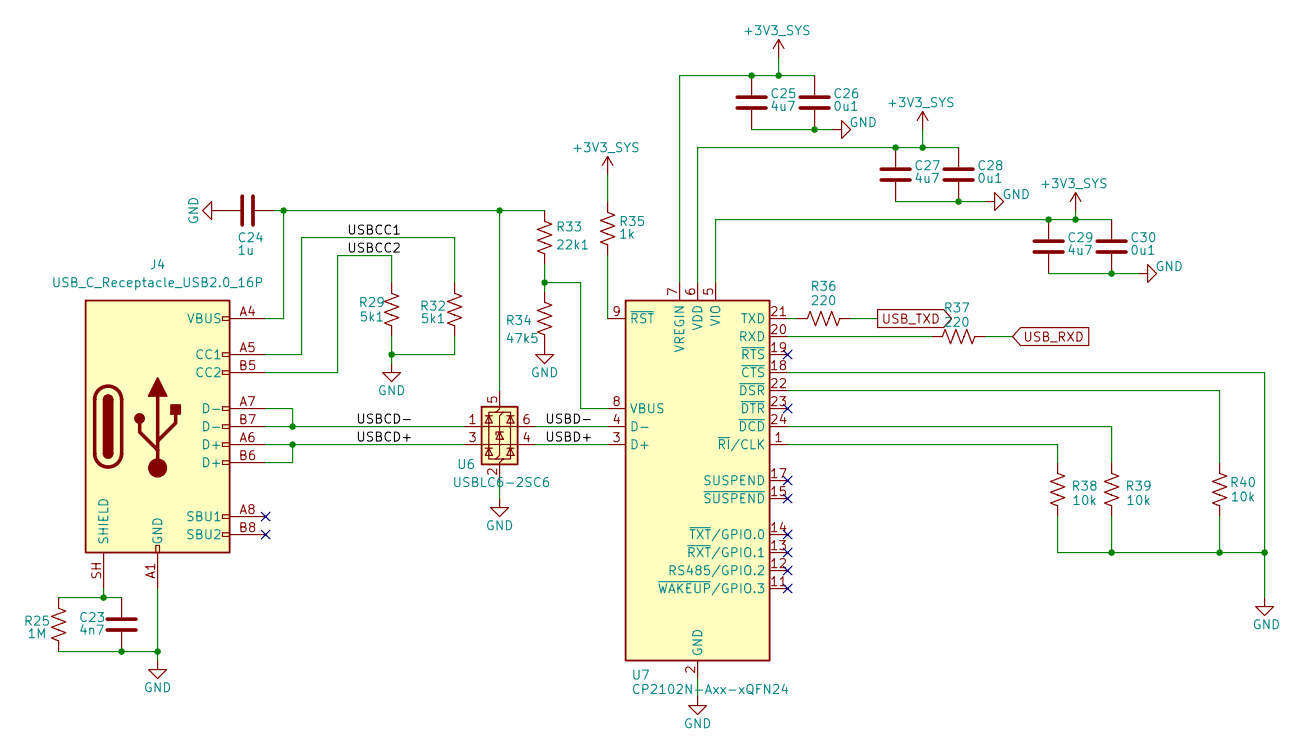
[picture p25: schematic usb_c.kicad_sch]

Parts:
C23: 4n7; C_1206_3216Metric; MPN C1206C472KGRACAUTO
C24: 1u; C_0402_1005Metric; MPN GCM155R71C105KA55D
C25, C27, C29: 4u7; C_0603_1608Metric; MPN GRT188C71C475KE13D
C26, C28, C30: 0u1; C_0402_1005Metric; MPN GCM155R71E104KE02D
J4: USB_C_Receptacle_USB2.0_16P; USB_C_Receptacle_GCT_USB4105-xx-A_16P_TopMnt_Horizontal; MPN USB4105-GF-A
R25: 1M; R_0603_1608Metric; MPN AC0603FR-071ML
R29, R32: 5k1; R_0603_1608Metric; MPN AC0603FR-075K1L
R33: 22k1; R_0603_1608Metric; MPN AC0603FR-0722K1L
R34: 47k5; R_0603_1608Metric; MPN AC0603FR-0747K5L
R35: 1k; R_0603_1608Metric; MPN AC0603FR-071KL
R36, R37: 220; R_0603_1608Metric; MPN AC0603FR-07220RL
R38, R39, R40: 10k; R_0603_1608Metric; MPN AC0603FR-0710KL
U6: USBLC6-2SC6; SOT-23-6; MPN USBLC6-2SC6Y
U7: CP2102N-Axx-xQFN24; QFN-24-1EP_4x4mm_P0.5mm_EP2.6x2.6mm; MPN CP2102N-A02-GQFN24

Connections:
+3V3_SYS: C25.1, C26.1, C27.1, C28.1, C29.1, C30.1, R35.2, U7.5 (VIO), U7.6 (VDD), U7.7 (VREGIN); also elsewhere on the board
/USB-C/USBCC1: J4.A5 (CC1), R32.2
/USB-C/USBCC2: J4.B5 (CC2), R29.1
/USB-C/USBCD+: J4.A6 (D+), J4.B6 (D+), U6.3 (I/O2)
/USB-C/USBCD-: J4.A7 (D-), J4.B7 (D-), U6.1 (I/O1)
/USB-C/USBD+: U6.4 (I/O2), U7.3 (D+)
/USB-C/USBD-: U6.6 (I/O1), U7.4 (D-)
GND: C23.2, C24.2, C25.2, C26.2, C27.2, C28.2, C29.2, C30.2, J4.A1 (GND), J4.A12 (GND), J4.B1 (GND), J4.B12 (GND), R25.1, R29.2, R32.1, R34.1, R38.1, R39.1, R40.1, U6.2 (GND), U7.2 (GND), U7.18 (~CTS), U7.25 (GND); also elsewhere on the board
unnamed: C23.1, J4.SH (SHIELD), R25.2
unnamed: C24.1, J4.A4 (VBUS), J4.A9 (VBUS), J4.B4 (VBUS), J4.B9 (VBUS), R33.1, U6.5 (VBUS)
unnamed: R37.2, U7.20 (RXD)
unnamed: R36.1, U7.21 (TXD)
unnamed: R33.2, R34.2, U7.8 (VBUS)
unnamed: R39.2, U7.24 (~DCD)
unnamed: R40.2, U7.22 (~DSR)
unnamed: R38.2, U7.1 (~RI/CLK)
unnamed: R35.1, U7.9 (~RST)
USB_RXD: R37.1; also elsewhere on the board
USB_TXD: R36.2; also elsewhere on the board

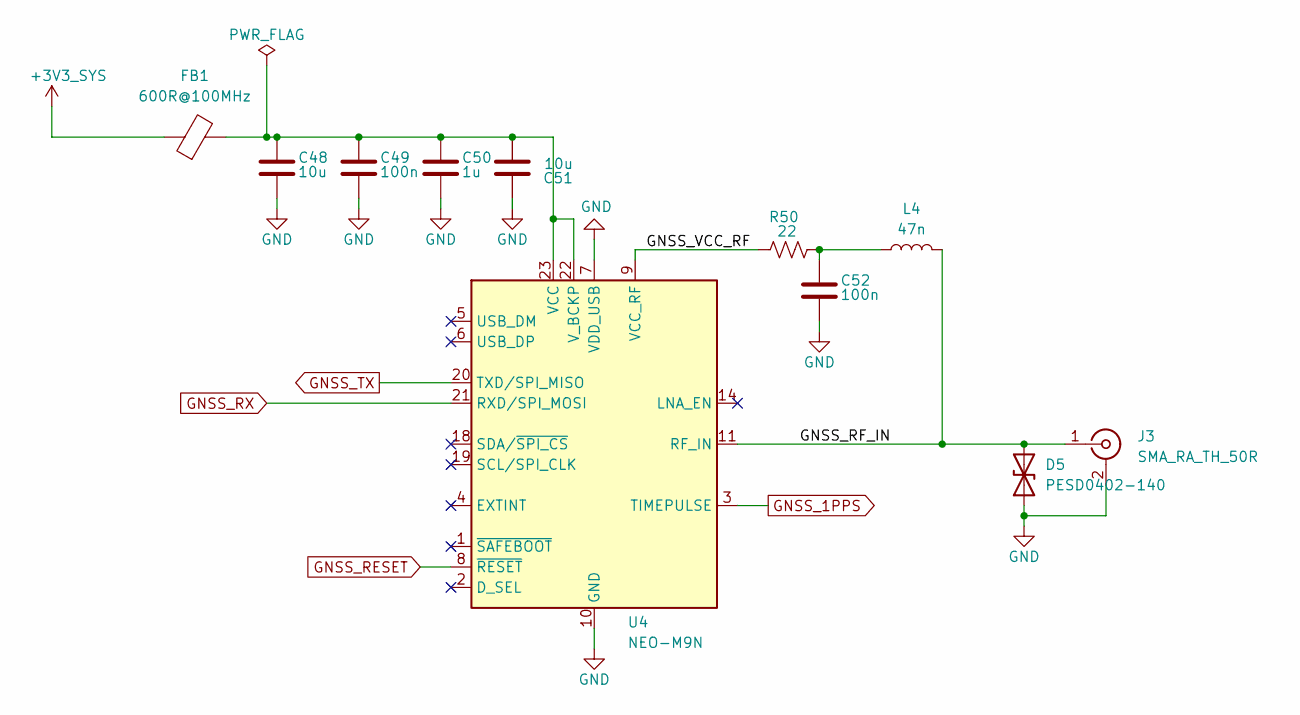
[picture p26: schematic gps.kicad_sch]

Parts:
C48, C51: 10u; C_0805_2012Metric; MPN GCM21BR71C106KE22L
C49, C52: 100n; C_0402_1005Metric; MPN GCM155R71C104KA55D
C50: 1u; C_0603_1608Metric; MPN GCM188R71C105KA64D
D5: PESD0402-140; D_0402_1005Metric_PESD0402-140; MPN PESD0402-140
FB1: 600R@100MHz; L_0603_1608Metric; MPN BLM18KG601SZ1D
J3: SMA_RA_TH_50R; SMA_Amphenol_901-143_Horizontal; MPN 132136; DigikeyPN ACX1232-ND
L4: 47n; L_0603_1608Metric; MPN LQW18AN47NG00D
R50: 22; R_0805_2012Metric; MPN ERJ-P06J220V
U4: NEO-M9N; ublox_NEO-M9N-00B; MPN NEO-M9N-00B

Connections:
+3V3_SYS: FB1.1; also elsewhere on the board
/GPS/GNSS_RF_IN: D5.2 (A2), J3.1 (In), L4.2, U4.11 (RF_IN)
/GPS/GNSS_VCC_RF: R50.1, U4.9 (VCC_RF)
GND: C48.2, C49.2, C50.2, C51.1, C52.2, D5.1 (A1), J3.2 (Ext), U4.7 (VDD_USB), U4.10 (GND), U4.12 (GND), U4.13 (GND), U4.24 (GND); also elsewhere on the board
GNSS_1PPS: U4.3 (TIMEPULSE); also elsewhere on the board
GNSS_RESET: U4.8 (~RESET); also elsewhere on the board
GNSS_RX: U4.21 (RXD/SPI_MOSI); also elsewhere on the board
GNSS_TX: U4.20 (TXD/SPI_MISO); also elsewhere on the board
unnamed: C52.1, L4.1, R50.2
unnamed: C48.1, C49.1, C50.1, C51.2, FB1.2, U4.22 (V_BCKP), U4.23 (VCC)

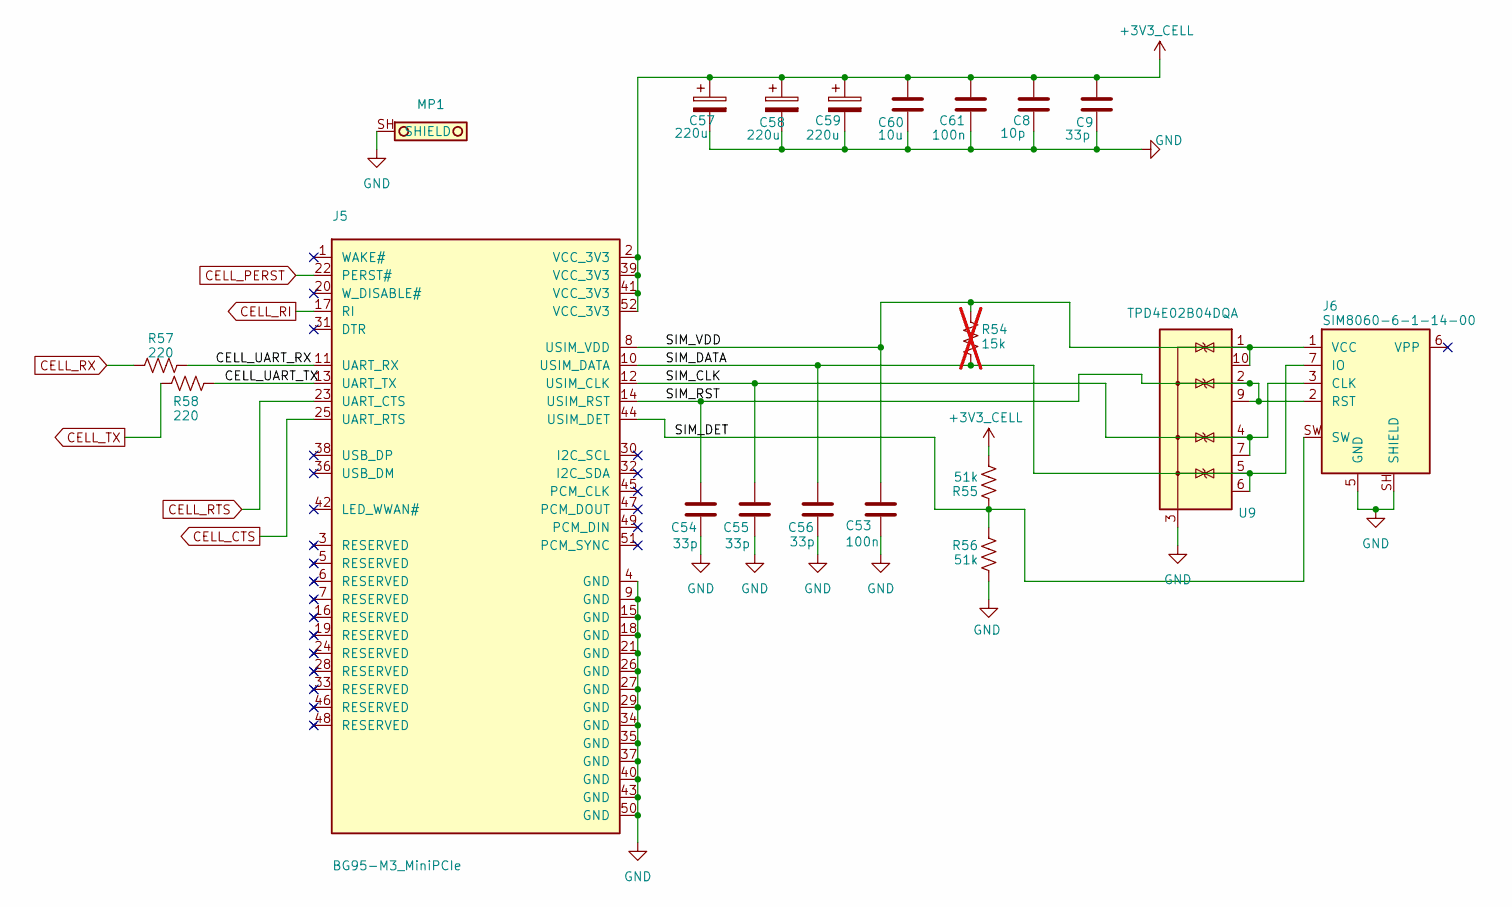
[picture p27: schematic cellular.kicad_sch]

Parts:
C8: 10p; C_0402_1005Metric; MPN GCM1555C1H100JA16D
C9, C54, C55, C56: 33p; C_0402_1005Metric; MPN GCM1555C1H330JA16D
C53, C61: 100n; C_0402_1005Metric; MPN GCM155R71C104KA55D
C57, C58, C59: 220u; CP_EIA-7343-31_Kemet-D; MPN T525D227M006ATE025
C60: 10u; C_0805_2012Metric; MPN GCM21BR71C106KE22L
J5: BG95-M3_MiniPCIe; Molex_67910-5700_MiniPCIe; MPN 679105700
J6: SIM8060-6-1-14-00; nanoSIM_GCT_SIM8060-6-1-14-00; MPN SIM8060-6-1-14-00-A
MP1: MiniPCIe_Latch; Molex_48099-5701_MiniPCIe_Latch; MPN 48099-5701
R54: 15k; R_0402_1005Metric; MPN AC0402FR-0715KL; not fitted
R55, R56: 51k; R_0402_1005Metric; MPN AC0402FR-0751KL
R57, R58: 220; R_0603_1608Metric; MPN AC0603FR-07220RL
U9: TPD4E02B04DQA; USON-10_2.5x1.0mm_P0.5mm; MPN TPD4E02B04DQAR

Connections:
+3V3_CELL: C8.1, C9.1, C57.1, C58.1, C59.1, C60.1, C61.1, J5.2 (VCC_3V3), J5.39 (VCC_3V3), J5.41 (VCC_3V3), J5.52 (VCC_3V3), R55.2; also elsewhere on the board
/Cellular/CELL_UART_RX: J5.11 (UART_RX), R57.2
/Cellular/CELL_UART_TX: J5.13 (UART_TX), R58.2
/Cellular/SIM_CLK: C55.1, J5.12 (USIM_CLK), J6.3 (CLK), U9.4 (IO3), U9.7 (NC)
/Cellular/SIM_DATA: C56.1, J5.10 (USIM_DATA), J6.7 (IO), R54.2, U9.5 (IO4), U9.6 (NC)
/Cellular/SIM_DET: J5.44 (USIM_DET), J6.SW, R55.1, R56.1
/Cellular/SIM_RST: C54.1, J5.14 (USIM_RST), J6.2 (RST), U9.2 (IO2), U9.9 (NC)
/Cellular/SIM_VDD: C53.1, J5.8 (USIM_VDD), J6.1 (VCC), R54.1, U9.1 (IO1), U9.10 (NC)
CELL_CTS: J5.25 (UART_RTS); also elsewhere on the board
CELL_PERST: J5.22 (PERST#); also elsewhere on the board
CELL_RI: J5.17 (RI); also elsewhere on the board
CELL_RTS: J5.23 (UART_CTS); also elsewhere on the board
CELL_RX: R57.1; also elsewhere on the board
CELL_TX: R58.1; also elsewhere on the board
GND: C8.2, C9.2, C53.2, C54.2, C55.2, C56.2, C57.2, C58.2, C59.2, C60.2, C61.2, J5.4 (GND), J5.9 (GND), J5.15 (GND), J5.18 (GND), J5.21 (GND), J5.26 (GND), J5.27 (GND), J5.29 (GND), J5.34 (GND), J5.35 (GND), J5.37 (GND), J5.40 (GND), J5.43 (GND), J5.50 (GND), J6.5 (GND), J6.SH (SHIELD), MP1.SH (SHIELD_SH), R56.2, U9.3 (G), U9.8 (G); also elsewhere on the board

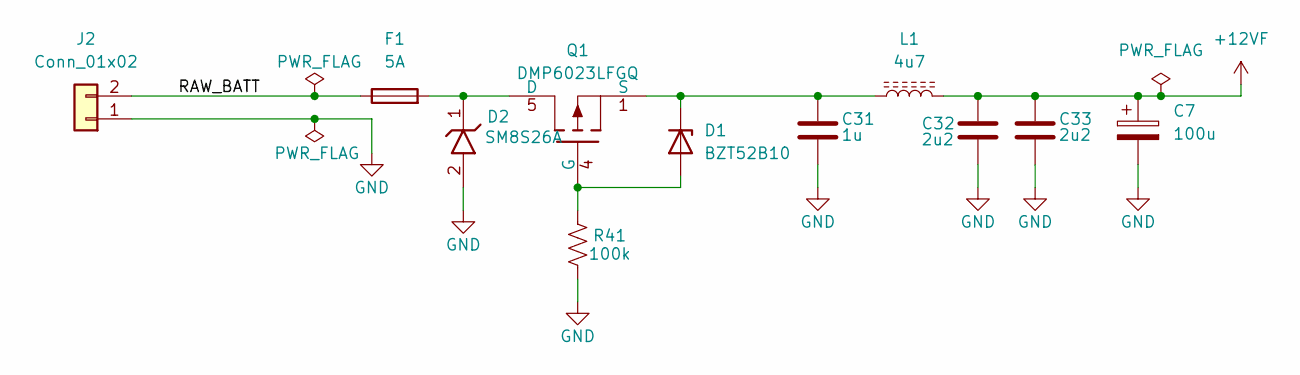
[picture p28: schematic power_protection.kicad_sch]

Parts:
C7: 100u; CP_Elec_10x10.5; MPN EEH-ZA1H101P
C31: 1u; C_0805_2012Metric; MPN GCM21BR71H105KA03L
C32, C33: 2u2; C_1206_3216Metric; MPN GCM31CR71H225KA55L
D1: BZT52B10; D_SOD-123F; MPN BZT52B10Q-7
D2: SM8S26A; Littelfuse_DO-218AB; MPN SM8S26A
F1: 5A; Fuseholder_Blade_Mini_Keystone_3568; MPN 0297005.WXNV
J2: Conn_01x02; SolderWire-0.5sqmm_1x02_P4.6mm_D0.9mm_OD2.1mm_Relief
L1: 4u7; L_Bourns_SRN8040TA; MPN SRN8040TA-4R7M
Q1: DMP6023LFGQ; Diodes_PowerDI3333-8; MPN DMP6023LFGQ-13
R41: 100k; R_0603_1608Metric; MPN AC0603FR-07100KL

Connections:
+12VF: C7.1, C32.1, C33.1, L1.2; also elsewhere on the board
/Power Protection/RAW_BATT: F1.1, J2.2
GND: C7.2, C31.2, C32.2, C33.2, D2.2 (A), J2.1, R41.1; also elsewhere on the board
unnamed: D1.2 (A), Q1.4 (G), R41.2
unnamed: C31.1, D1.1 (K), L1.1, Q1.1 (S), Q1.2 (S), Q1.3 (S)
unnamed: D2.1 (K), F1.2, Q1.5 (D)

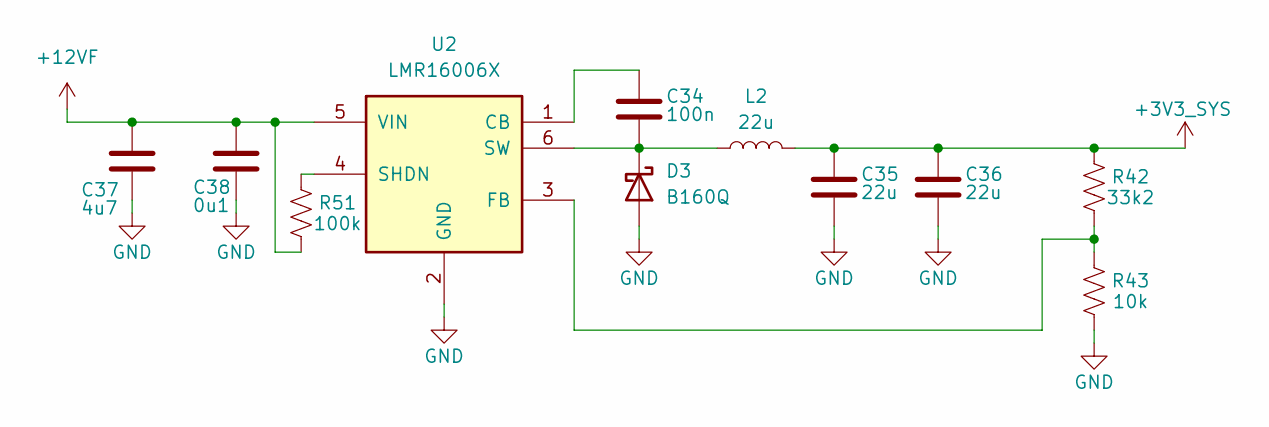
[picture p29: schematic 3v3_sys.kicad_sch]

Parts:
C34: 100n; C_0805_2012Metric; MPN GCM21BR71H104KA37L
C35, C36: 22u; C_0805_2012Metric; MPN GCM21BR61A226ME36L
C37: 4u7; C_1210_3225Metric; MPN GCM32ER71H475KA55L
C38: 0u1; C_0805_2012Metric; MPN GCM21BR71H104KA37L
D3: B160Q; D_SMA; MPN B160Q-13-F
L2: 22u; L_Bourns_SRN6045TA; MPN SRN6045TA-220M
R42: 33k2; R_0603_1608Metric; MPN AC0603FR-0733K2L
R43: 10k; R_0603_1608Metric; MPN AC0603FR-0710KL
R51: 100k; R_0603_1608Metric; MPN AC0603FR-07100KL
U2: LMR16006X; TSOT-23-6; MPN LMR16006XDDCR

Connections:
+3V3_SYS: C35.1, C36.1, L2.2, R42.2; also elsewhere on the board
+12VF: C37.1, C38.1, R51.1, U2.5 (VIN); also elsewhere on the board
GND: C35.2, C36.2, C37.2, C38.2, D3.2 (A), R43.1, U2.2 (GND); also elsewhere on the board
unnamed: C34.2, D3.1 (K), L2.1, U2.6 (SW)
unnamed: C34.1, U2.1 (CB)
unnamed: R42.1, R43.2, U2.3 (FB)
unnamed: R51.2, U2.4 (SHDN)

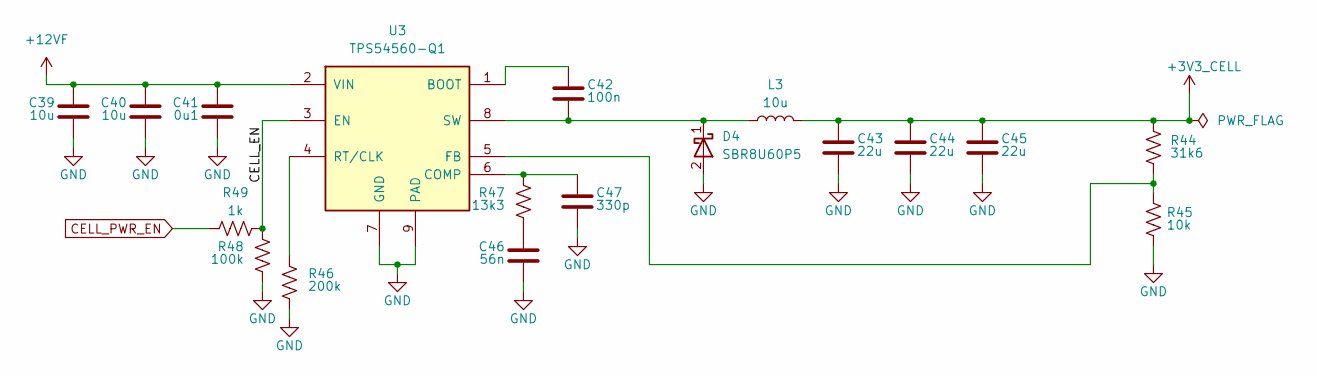
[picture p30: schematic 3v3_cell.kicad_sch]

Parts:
C39, C40: 10u; C_1210_3225Metric; MPN GCM32ER71H106KA03L
C41: 0u1; C_0805_2012Metric; MPN GCM21BR71H104KA37L
C42: 100n; C_0805_2012Metric; MPN GCM21BR71H104KA37L
C43, C44, C45: 22u; C_1206_3216Metric; MPN GCM31CR71C226KE02L
C46: 56n; C_0603_1608Metric; MPN GCM188R71H563KA55D
C47: 330p; C_0603_1608Metric; MPN GCM1885C1H331JA16D
D4: SBR8U60P5; D_PowerDI-5_SBR8U60P5; MPN SBR8U60P5-13
L3: 10u; L_Coilcraft_XAL6060-XXX; MPN XAL6060-103MEC
R44: 31k6; R_0603_1608Metric; MPN AC0603FR-0731K6L
R45: 10k; R_0603_1608Metric; MPN AC0603FR-0710KL
R46: 200k; R_0603_1608Metric; MPN AC0603FR-07200KL
R47: 13k3; R_0603_1608Metric; MPN AC0603FR-0713K3L
R48: 100k; R_0603_1608Metric; MPN AC0603FR-07100KL
R49: 1k; R_0603_1608Metric; MPN AC0603FR-071KL
U3: TPS54560-Q1; SOIC-8-1EP_3.9x4.9mm_P1.27mm_EP2.95x4.9mm_Mask2.71x3.4mm_Th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; MPN TPS54560QDDARQ1; DigikeyPN 296-38302-1-ND

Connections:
+3V3_CELL: C43.1, C44.1, C45.1, L3.2, R44.1; also elsewhere on the board
+12VF: C39.1, C40.1, C41.1, U3.2 (VIN); also elsewhere on the board
/Cell Power Rail/CELL_EN: R48.1, R49.2, U3.3 (EN)
CELL_PWR_EN: R49.1; also elsewhere on the board
GND: C39.2, C40.2, C41.2, C43.2, C44.2, C45.2, C46.2, C47.2, D4.2 (A), R45.2, R46.2, R48.2, U3.7 (GND), U3.9 (PAD); also elsewhere on the board
unnamed: C46.1, R47.2
unnamed: C42.2, D4.1 (K), L3.1, U3.8 (SW)
unnamed: C42.1, U3.1 (BOOT)
unnamed: C47.1, R47.1, U3.6 (COMP)
unnamed: R44.2, R45.1, U3.5 (FB)
unnamed: R46.1, U3.4 (RT/CLK)

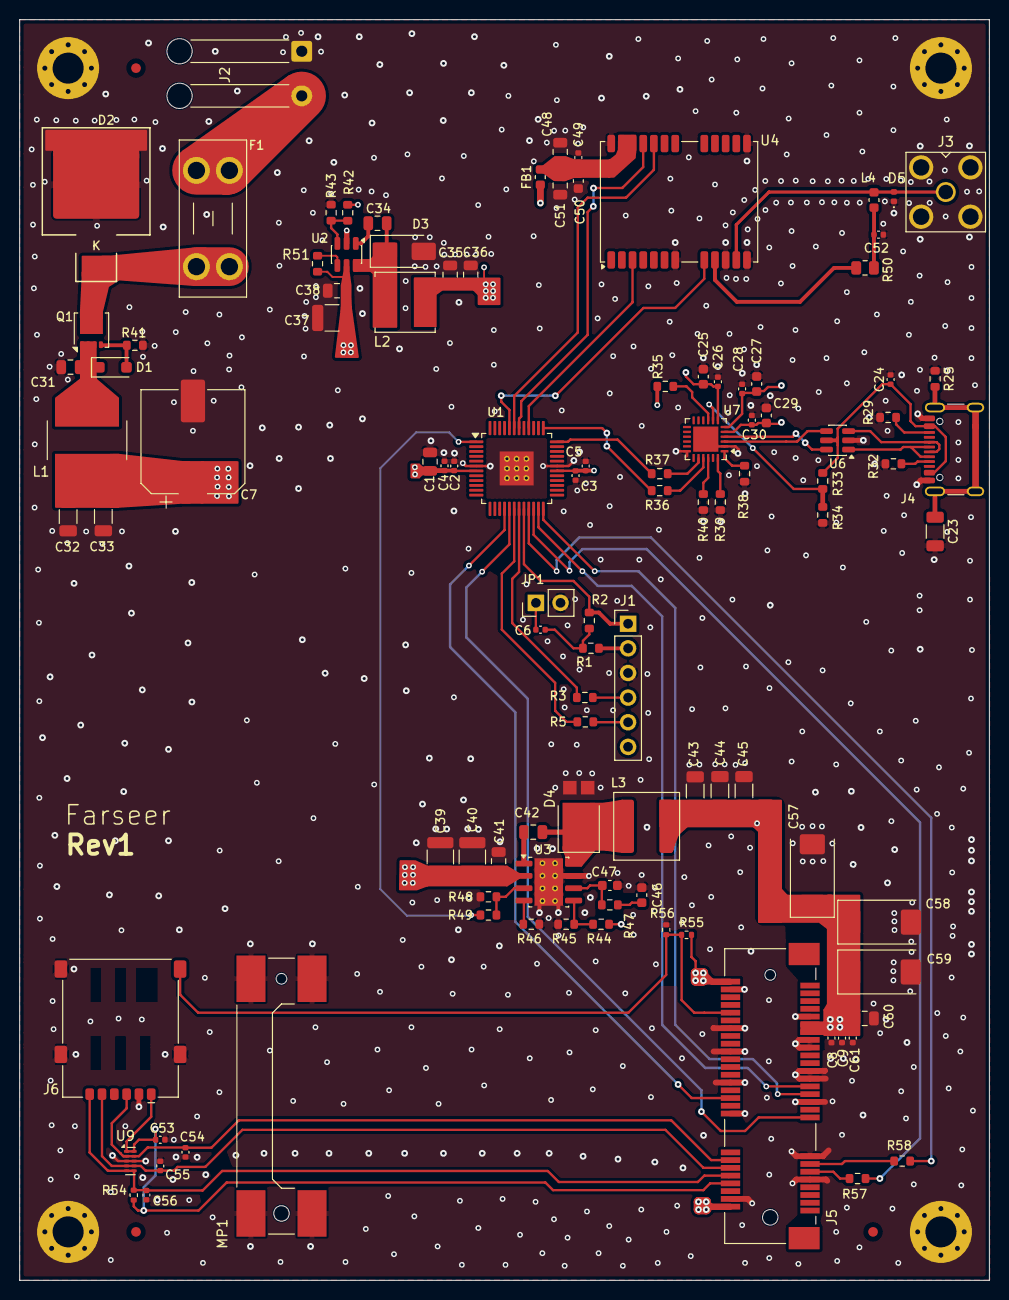
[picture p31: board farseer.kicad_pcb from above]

Board: 4 copper layers, 100.0 x 130.0 mm, 113 parts (0 on the bottom side), 65 nets.

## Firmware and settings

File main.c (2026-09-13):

/**
 * @file main.c
 * @author james
 * @date 2026-07-03
 * @brief Farseer prototype: non-blocking superloop tying the NEO-M9N GNSS and the
 *        BG95-M3 cellular link together.
 *
 * The loop never blocks: UART RX is interrupt-fed into ring buffers, GPS bytes
 * are drained and parsed, and BG95_Task() cooperatively brings up an LTE-M link,
 * transmits datagrams, monitors signal quality, and delivers downlink data. A
 * cellular stall therefore can no longer starve GPS ingest.
 *
 * Capture and transmit run at different rates on purpose. Every fix the NEO-M9N
 * produces (10 Hz) goes into the telemetry ring; the uplink drains overlapping
 * windows out of it at 5 Hz, so each fix rides in several consecutive datagrams.
 * Nothing is discarded for being un-sendable at the moment it was measured, and a
 * modem stall shows up as latency the server's livestream delay absorbs rather
 * than as a hole in the data.
 *
 * Data flow:  NEO-M9N TX --(38400)--> RD1/UART2 (ISR) --> GPS_Process --> UART1 terminal
 *             (module runs at its 38400 power-on default; RMC+GGA at 10 Hz is
 *              ~1.6 kB/s, about 43% of that link, so no baud change is needed)
 *             GPS_GetFix --> telemetry ring --> binary batch --> UART3 --> BG95 --> UDP server
 *
 * Pin assignments: see board_pins.h.
 */

// CONFIG1 (see DS40002213F sec 8.5.1)
#pragma config FEXTOSC = OFF            // External oscillator not enabled
#pragma config RSTOSC = HFINTOSC_64MHZ  // Power-up with HFINTOSC @ 64 MHz, CDIV 1:1

// CONFIG2 (sec 8.5.2)
// JTAGEN resets to 1 (TAP enabled). While enabled, RA0 (TMS), RA5 (TCK),
// RB3 (TDO) and RB5 (TDI) become dedicated JTAG pins and are cut off from the
// port/PPS logic (sec 39.1.1) -- the board uses RA0 = CELL_TX (U3RX) and
// RB5 = CELL_RI. Boundary scan is not used (JTAG cannot program this part).
#pragma config JTAGEN = OFF             // Release RA0/RA5/RB3/RB5 for I/O

// CONFIG3 (sec 8.5.3)
#pragma config MCLRE = EXTMCLR          // MCLR pin enabled (RE3)

// CONFIG4 (sec 8.5.4)
#pragma config LVP = ON                 // Low-voltage programming (ICSP / PICkit)

// CONFIG5 (sec 8.5.5)
#pragma config WDTE = OFF               // Watchdog timer disabled

#include <xc.h>
#include <stdio.h>
#include "board_pins.h"
#include "uart1.h"
#include "uart2.h"
#include "uart3.h"
#include "timer.h"
#include "gps.h"
#include "bg95.h"
#include "telemetry.h"

/* 5 Hz uplink. Fast enough that the server's 2-3 s livestream delay hides the
 * packetisation entirely, and slow enough that each datagram carries several
 * fixes, which is what pays for the redundancy: the per-packet overhead (IP,
 * UDP and LTE headers, plus an AT round-trip) is amortised over 8 fixes instead
 * of being paid per fix. */
#define UDP_SEND_INTERVAL_MS 200

/* How often to print the link/telemetry health beacon, in ms. */
#define HEALTH_INTERVAL_MS 5000

/**
 * @brief Downlink handler: called when a UDP datagram arrives from the server.
 *
 * The downlink is a very low volume control channel (as little as a single
 * byte), so for now the payload is echoed to the debug terminal. Hook real
 * command handling in here.
 */
static void on_downlink(const uint8_t *data, uint16_t len)
{
    printf("[BG95] downlink payload: ");
    for (uint16_t i = 0; i < len; i++) {
        printf("%02X ", data[i]);
    }
    printf(" | \"");
    for (uint16_t i = 0; i < len; i++) {
        uint8_t c = data[i];
        /* printable ASCII stays as-is; everything else shown as '.' */
        printf("%c", (c >= 0x20 && c <= 0x7E) ? (char)c : '.');
    }
    printf("\"\r\n");
}

/**
 * @brief Select HFINTOSC at 64 MHz as the system clock.
 *
 * RSTOSC already sets this at reset, but set it explicitly so the clock source
 * is unambiguous, then wait for the HFINTOSC to report ready.
 */
static void Clock_Init(void)
{
    OSCFRQbits.HFFRQ = 0b1000; // HFINTOSC = 64 MHz
    OSCCON1bits.NOSC = 0b110;  // New oscillator source = HFINTOSC
    OSCCON1bits.NDIV = 0b0000; // Clock divider = 1:1

    while (OSCCON3bits.ORDY == 0) {  // wait for clock switch to complete
        ;
    }
    while (OSCSTATbits.HFOR == 0) {  // wait for HFINTOSC to stabilize
        ;
    }
}

int main(void)
{
    Clock_Init();
    UART1_Init();
    UART2_Init();
    UART3_Init();
    Timer0_Init();
    INTCON0bits.GIE = 1;    // enable interrupts for the Timer0 millisecond tick

    printf("\r\nFarseer boot: NEO-M9N + BG95 UDP (non-blocking)\r\n");

    /* Kick off GPS config; it is re-sent below until the module ACKs, so a
     * still-booting NEO-M9N that misses the first frame is retried. */
    GPS_Configure();
    uint32_t last_gps_cfg = millis();
    printf("[GPS] link @38400; configuring for 10 Hz (RMC+GGA); awaiting ACK\r\n");

    BG95_Init(on_downlink);
    printf("[BG95] bring-up started; loop is non-blocking\r\n");

    Telemetry_Init();

    uint32_t last_send = millis();
    uint32_t last_health = millis();
    uint16_t last_fix_seq = 0;      /* seq of the last fix pushed to the ring */
    bool     link_was_ready = false;
    for (;;) {
        /* Drain GPS bytes so the NEO-M9N is never starved, regardless of what
         * the cellular link is doing. */
        char c;
        while (UART2_TryReadByte(&c)) {
            GPS_Process(c);
        }

        /* Re-send the GPS config once per second until the module ACKs it, in
         * case the NEO-M9N was still booting when the first frame was sent. */
        if (!GPS_ConfigAcked() && (millis() - last_gps_cfg) >= 1000) {
            last_gps_cfg = millis();
            GPS_Configure();
        }

        /* Advance the cellular link/send/receive state machine. */
        BG95_Task();

        /* Capture every locked fix at the full nav rate. GPS_Fix.seq advances
         * once per locked epoch, so comparing it is how a fresh fix is told from
         * a repeat read of the previous one. This is polled rather than driven
         * from the parser so the ring is filled from the foreground, where a
         * long BG95 transaction cannot preempt it mid-update. */
        GPS_Fix fix;
        GPS_GetFix(&fix);
        if (fix.valid && fix.seq != last_fix_seq) {
            last_fix_seq = fix.seq;
            Telemetry_PushFix(&fix);
        }

        /* Fixes pile up during the seconds the modem spends attaching at boot.
         * Zero the overflow counter the moment the link comes up so the server
         * is not told a healthy boot lost data. */
        if (BG95_IsReady() != link_was_ready) {
            link_was_ready = BG95_IsReady();
            if (link_was_ready) {
                Telemetry_LinkReady();
            }
        }

        /* Build and hand over the next datagram. The buffer is only offered when
         * the driver is idle, so the packet is always assembled from the newest
         * ring contents rather than having gone stale waiting in a queue.
         *
         * last_send only advances on a successful claim: if the modem is busy
         * the deadline stays passed and the send happens the moment it frees up,
         * so a stall is followed by catch-up rather than by skipped slots. */
        if ((millis() - last_send) >= UDP_SEND_INTERVAL_MS) {
            uint16_t max_len;
            uint8_t *buf = BG95_ClaimTxBuffer(&max_len);
            if (buf != NULL) {
                last_send = millis();
                uint16_t n = Telemetry_BuildPacket(buf, max_len);
                if (n > 0) {
                    BG95_CommitTxBuffer(n);
                }
            }
        }

        /* Health beacon. Between them these numbers localise a fault without a
         * debugger: gps rx=0 means nothing is arriving on UART2 (wiring, power
         * or baud), rx>0 with valid=0 means the bytes are garbage (baud
         * mismatch), and valid>0 with depth=0 means the link is fine and the
         * receiver simply has no lock yet.
         *
         * Once running, watch three things. u2drop must stay at 0; if it moves,
         * the payload write is blocking long enough to lose NMEA and needs
         * chunking across loop iterations. depth should hover near the batch
         * size and return to it after a stall -- pinned near TLM_RING_SLOTS
         * means the uplink is not keeping up and fixes are being lost. And the
         * QISEND round-trip is what sets the real ceiling on send rate, so the
         * max is the number to size any future interval change against. */
        if ((millis() - last_health) >= HEALTH_INTERVAL_MS) {
            last_health = millis();

            uint32_t gps_bytes, gps_sentences;
            GPS_RxStats(&gps_bytes, &gps_sentences);
            printf("\r\n[GPS] health: rx=%lu bytes, valid=%lu sentences, "
                   "cfg_acked=%d, u2drop=%u\r\n",
                   (unsigned long)gps_bytes, (unsigned long)gps_sentences,
                   (int)GPS_ConfigAcked(), (unsigned)UART2_RxDropped());

            BG95_TxStats tx;
            BG95_GetTxStats(&tx);
            printf("[TLM] ring depth=%u/%u drops=%u | sent=%u sendfail=%u tmo=%u"
                   " | qisend ms last=%u min=%u avg=%u max=%u\r\n",
                   (unsigned)Telemetry_RingDepth(), (unsigned)TLM_RING_SLOTS,
                   (unsigned)Telemetry_DropCount(),
                   (unsigned)tx.sent, (unsigned)tx.send_fail,
                   (unsigned)tx.timeouts, (unsigned)tx.rt_last_ms,
                   (unsigned)tx.rt_min_ms, (unsigned)tx.rt_avg_ms,
                   (unsigned)tx.rt_max_ms);
        }
    }

    return 0;
}

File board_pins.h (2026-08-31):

/**
 * @file board_pins.h
 * @brief Farseer custom-board PIC18F57Q84 pin map (48-pin TQFP).
 *
 * Matches the KiCad schematic (farseer.kicad_sch + child sheets). Net names are
 * peripheral-relative (CELL_RX = card UART_RX, USB_RXD = bridge RXD, etc.).
 * Do not reassign reserved pins below to other functions.
 */
#ifndef BOARD_PINS_H
#define BOARD_PINS_H

/* --- In use by firmware -------------------------------------------------- */
/* RC7  CELL_PWR_EN   out  GPIO     -> U3 (TPS54560-Q1) EN; HIGH = 3V3_CELL on */
/* RF0  USB_RXD       out  U1TX     -> U7 CP2102N RXD (console) */
/* RF1  USB_TXD       in   U1RX     <- U7 CP2102N TXD */
/* RA1  CELL_RX       out  U3TX     -> J5 pin 11 UART_RX (via R57) */
/* RA0  CELL_TX       in   U3RX     <- J5 pin 13 UART_TX (via R58) */
/* RD0  GNSS_RX       out  U2TX     -> U4 NEO-M9N pin 21 RXD */
/* RD1  GNSS_TX       in   U2RX     <- U4 NEO-M9N pin 20 TXD */
/* RB6  ICSPCLK       —    ICSP     -> J1 PGC */
/* RB7  ICSPDAT       —    ICSP     -> J1 PGD */
/* RE3  MCLR          in   reset    -> J1 MCLR / R1 pull-up */

/* --- Wired on PCB, not driven/read by firmware yet — do not reuse -------- */
/* RB4  CELL_PERST    out  GPIO     -> J5 pin 22 PERST# (active-low reset) */
/* RB5  CELL_RI       in   INT2     <- J5 pin 17 RI (wake / URC) */
/* RD2  GNSS_RESET    out  GPIO     -> U4 pin 8 RESET_N (active-low) */
/* RC2  GNSS_1PPS     in   CCP1     <- U4 pin 3 TIMEPULSE */
/* RA2  CELL_CTS      in   U3CTS    <- J5 pin 25 UART_RTS (HW flow control) */
/* RA3  CELL_RTS      out  U3RTS    -> J5 pin 23 UART_CTS (HW flow control) */

/* --- Reserved on schematic, not wired yet -------------------------------- */
/* RB1  (spare)       —    —        reserved for W_DISABLE# if needed later */

#endif /* BOARD_PINS_H */

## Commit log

2026-08-31 added initial farseer resources
    [02-01204-R6_PNP.csv, 02-01204-R6_TPR.csv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]
2026-09-13 finished rev1
    [3v3_cell.kicad_sch, 3v3_sys.kicad_sch, cellular.kicad_sch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]
